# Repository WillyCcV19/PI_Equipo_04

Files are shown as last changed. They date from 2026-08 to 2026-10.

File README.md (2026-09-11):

# EQUIPO N° IV - Proyecto Integrador 2026-2  
<div align="center">

<!-- Banner animado (capsule-render funciona nativo en GitHub, sin GIFs pesados) -->


<!-- Texto tipo "máquina de escribir" (animado, se genera al vuelo) -->
<a href="#-qué-va-a-consistir-el-proyecto">
  Typing SVG
</a>

<br/><br/>






</div>

### Carrera de Ingeniería Industrial / Informática   
**Universidad Peruana Cayetano Heredia**

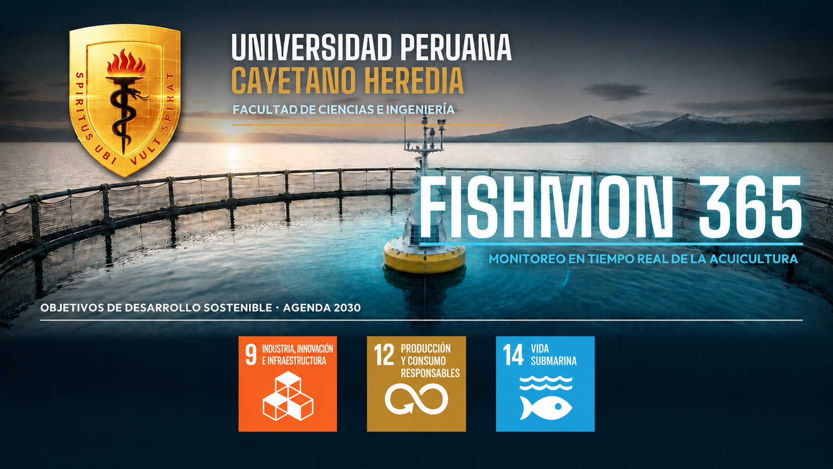
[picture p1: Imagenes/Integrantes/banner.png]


---

## 👫 ¿Quiénes somos?

Somos participantes del curso Proyecto Integrador 2026-2, integrados por estudiantes de Ingeniería Industrial e Informática de la Universidad Peruana Cayetano Heredia. Nuestra misión es utilizar la metodología de diseño para desarrollar soluciones creativas y técnicamente fundamentadas que aporten valor social, tecnológico y ambiental.

---

## ⚙️  Justificación Técnica y Fundamento Biológico

Para validar técnicamente el desarrollo de FISHMON 365, nos basamos en la normativa e investigación oficial del Fondo Nacional de Desarrollo Pesquero (FONDEPES - PRODUCE, Perú) [1]:

### 1. Especie Cultivada y Taxonomía

- **Especie de crianza:** Trucha Arco Iris [1].
- **Nombre científico oficial:** *Oncorhynchus mykiss* (denominada anteriormente *Salmo gairdneri irideus*) [1].
- **Ambiente de cultivo:** Agua dulce continental (recursos hídricos lóticos como ríos, arroyos y manantiales, y lénticos como lagunas) [1].

### 2. Sistemas de Acuicultura en el Perú y Diagnóstico de Mortalidad

| Criterio Técnico | Sistema Convencional (Estanquería) | Sistema No Convencional (Jaulas Flotantes) |
|---|---|---|
| **Infraestructura principal** | Estanques de concreto, mampostería de piedra y tierra [1]. | Jaulas flotantes en lagos y lagunas [1]. |
| **Distribución Regional** | Mayor prevalencia en la Región Junín [1]. | Predominante en la Región Puno (concentra el 98% de esta modalidad) [1]. |
| **Aporte a la Producción Nacional (2012)** | Junín: 3,412.53 TM/Año (13.78%) [1]. | Puno: 18,471.02 TM/Año (74.59%) [1]. |
| **Variabilidad del Medio** | Altamente vulnerable a fluctuaciones de caudal, temperatura y arrastre de sólidos por lluvias [1]. | Vulnerable a eventos de anoxia global en la columna de agua y ecorregiones lénticas [1]. |

### 3. Causa Principal de Mortalidad: Asfixia e Hipoxia por Deficiencia de Oxígeno Disuelto (O₂)

La mayor tasa de mortandad o pérdida de rendimiento biológico-económico en los cultivos de trucha se debe a la pérdida del equilibrio entre el Hospedador, el Patógeno y el Ambiente ($H + P + A = E$) [1].

Específicamente, el factor crítico es la asfixia e hipoxia por baja concentración de oxígeno disuelto ($O_2$). De acuerdo con FONDEPES [1]:

> *"Como la crianza se realiza a grandes densidades es recomendable que la cantidad de oxígeno no sea menor a 5.5 mg/l (60% de saturación de oxígeno) en los momentos de máximo consumo en el cultivo, ya que de lo contrario los peces van a presentar signos de asfixia"* [1, p. 12].
>
> *"Pueden presentarse peces con hipoxia, aunque haya suficiente oxígeno en el medio de cultivo por la presencia de nitritos"* [1, p. 62].

---

## ⚙️ ¿En qué va a consistir el proyecto?

**FISHMON 365** es un **dispositivo multiparámetro portátil y autónomo** diseñado para el **monitoreo en tiempo real y a multinivel** de la calidad del agua dulce en sistemas de cultivo de trucha (*Oncorhynchus mykiss*) [1]. 

El sistema está compuesto por una **sección flotante con electrónica blindada** y una **sonda sumergible vertical multinivel**, equipada con sensores calibrados para realizar lecturas continuas a tres profundidades distintas dentro de la columna de agua. Toda la información capturada es procesada y transmitida de forma inalámbrica mediante tecnología **IoT** directamente a una **aplicación móvil para smartphone**, enviando alertas tempranas en tiempo real ante variaciones fuera de los rangos seguros [1].

Para garantizar la continuidad operativa en zonas rurales o ante posibles cortes de energía eléctrica, el equipo integra un **sistema de alimentación autónomo con batería de respaldo**, asegurando mediciones ininterrumpidas las 24 horas del día.

---

### Perfil de Medición Multinivel en la Columna de Agua

Dado que parámetros críticos como el oxígeno disuelto y la temperatura varían verticalmente según la dinámica del estanque, la descomposición de materia orgánica y el nivel de alimentación [1], **FISHMON 365** monitorea tres estratos clave:

| Profundidad / Estrato | Justificación Técnica Biológica | Impacto en la Trucha Arco Iris |
| :--- | :--- | :--- |
| **Superficie** | Zona de mayor intercambio gaseoso atmosférico e incidencia de radiación solar [1]. | Evalúa la temperatura máxima y la saturación inicial de oxígeno [1]. |
| **Nivel Medio (Media Agua)** | Zona de natación activa y desplazamiento del cardumen de truchas en crecimiento [1]. | Garantiza que la masa de agua habitada mantenga tenores de $O_2 \ge 5.5\text{ mg/L}$ [1]. |
| **Nivel de Fondo (Suelo acuícola)** | Zona de acumulación de alimento no consumido, heces, materia orgánica y alimentación del pez [1]. | Detecta zonas anóxicas ($O_2 < 3.0\text{ mg/L}$), acumulación de nitritos y variaciones de pH por descomposición [1]. |

---

## 🌿 Contexto de Aplicación y Validación de Campo: Santa Eulalia

Para validar el prototipo en condiciones reales de campo de la sierra de Lima, el dispositivo se probará en las piscigranjas de agua dulce del distrito de Santa Eulalia (Provincia de Huarochirí, Lima):

- **Ubicación de prueba:** Valle del río Santa Eulalia (Afluente del río Rímac).
- **Altitud de evaluación:** Entre 1,036 m.s.n.m. y 1,400 m.s.n.m. (zona de cuenca media).
- **Características hídricas:** Aguas continentales dulceacuícolas lóticas (ríos y arroyos de deshielo/manantial) [1].
- **Impacto ambiental local:** Permite monitorear la variación de temperatura y oxígeno disuelto en temporadas de estiaje vs. avenidas (lluvias), previniendo el estrés branquial y mortandades masivas [1].

---

## 🌿 ¿Qué problemáticas soluciona?

| Problema Actual en la Truchicultura | Solución Técnica que Aporta FISHMON 365 | Sustento Oficial (FONDEPES) |
|---|---|---|
| Altas mortandades por asfixia silenciosa ($O_2 < 5.5\text{ mg/L}$) | Monitoreo continuo de Oxígeno Disuelto con alertas sonoras/visuales inmediatas. | *"A menores niveles de $O_2$ (0 - 3.0 mg/l), la trucha muere; entre 3.1 - 4.5 mg/l sufre grave estrés"* [1, p. 12]. |
| Elevados costos de equipos comerciales de laboratorio | Diseño portátil de bajo costo con componentes e integración local | Permite acceso a tecnología a productores de subsistencia y menor escala ($99.44\%$ del mercado) [1, p. 9]. |
| Mediciones manuales extemporáneas que no previenen crisis | Lectura inmediata en campo con diagnóstico automático vía IoT | Permite ajustar inmediatamente la tasa de recambio de agua por hora (R/A/H) [1, p. 11]. |
| Falta de conectividad en zonas altoandinas/rurales | Funcionamiento en modo offline con almacenamiento SD y sincronización posterior IoT | Asegura el registro histórico sin depender de cobertura celular continua. |
| Falta de estandarización técnica del criador | Configuración de umbrales bajo la NTP y manuales de PRODUCE/FONDEPES | Ajustado a los rangos óptimos del agua para *Oncorhynchus mykiss* [1, p. 12-13]. |

---

## 🌿 Alineación con Objetivos de Desarrollo Sostenible (ODS)

Nos comprometemos con la agenda global incorporando las metas oficiales ajustadas según la fuente de la Organización de las Naciones Unidas (ONU):

### 🌿 ODS 9: Industria, Innovación e Infraestructura

**Meta 9.5:** *Aumentar la investigación científica y mejorar la capacidad tecnológica de los sectores industriales de todos los países, en particular los países en desarrollo, entre otras cosas fomentando la innovación e incrementando considerablemente de aquí a 2030 el número de personas que trabajan en investigación y desarrollo por millón de habitantes y los gastos en investigación y desarrollo de los sectores público y privado.*

### 🌿 ODS 12: Producción y Consumo Responsables

**Meta 12.a:** *Ayudar a los países en desarrollo a fortalecer su capacidad científica y tecnológica para avanzar hacia modalidades de consumo y producción más sostenibles.*

### 🌿 ODS 14: Vida Submarina y Recursos Hídricos

**Meta 14.7:** *De aquí a 2030, aumentar los beneficios económicos que los pequeños Estados insulares en desarrollo y los países menos adelantados obtienen del uso sostenible de los recursos marinos, en particular mediante la gestión sostenible de la pesca, la acuicultura y el turismo.*

**Meta 14.a:** *Aumentar los conocimientos científicos, desarrollar la capacidad de investigación y transferir tecnología marina, teniendo en cuenta los Criterios y Directrices para la Transferencia de Tecnología Marina de la Comisión Oceanográfica Intergubernamental, a fin de mejorar la salud de los océanos y potenciar la contribución de la biodiversidad marina al desarrollo de los países en desarrollo, en particular los pequeños Estados insulares en desarrollo y los países menos adelantados.*

---

## 🌿 Matriz de Parámetros Técnicos de Medición (Agua Dulce)

Basado estrictamente en las especificaciones del Manual de Cultivo de Trucha - FONDEPES [1]:

| Parámetro Fisicoquímico | Rango Crítico / Letal | Rango Óptimo de Cultivo | Impacto Biológico en la Trucha Arco Iris |
|---|---|---|---|
| **Oxígeno Disuelto ($O_2$)** | $< 3.0\text{ mg/L}$ (Muerte)<br>$3.1 - 4.5\text{ mg/L}$ (Estrés grave) [1] | **$6.0 - 8.5\text{ mg/L}$** (Mínimo $5.5\text{ mg/L}$) [1] | La deficiencia causa asfixia, reducción del consumo de alimento y suspensión del crecimiento [1]. |
| **Temperatura ($T^\circ\text{C}$)** | $< 3^\circ\text{C}$ o $> 20^\circ\text{C}$ (Muerte / Riesgo severo) [1] | **$11 - 16^\circ\text{C}$** (Engorde óptimo: $15 - 16^\circ\text{C}$)<br>(Incubación: $8 - 10^\circ\text{C}$) [1] | Condiciona el metabolismo, apetito, velocidad de crecimiento y solubilidad del oxígeno disuelto [1]. |
| **Potencial de Hidrógeno (pH)** | $< 6.0$ o $> 9.0$ (Incompatible con la vida) [1] | **$7.0 - 8.0$** (Ligeramente alcalino) [1] | Niveles $< 6.5$ producen hemorragias branquiales y mortandades masivas [1]. |
| **Turbidez / Sólidos** | Elevados sólidos en suspensión [1] | Agua cristalina / Filtrada [1] | Los sólidos en suspensión dañan las branquias y sofocan a los alevinos [1]. |
| **Dióxido de Carbono ($CO_2$)** | $> 2.0\text{ ppm}$ [1] | $< 2.0\text{ ppm}$ [1] | Concentraciones altas merman el $O_2$ disuelto y alteran el pH sanguíneo del pez [1]. |

---

## 📷 Fotografía del equipo

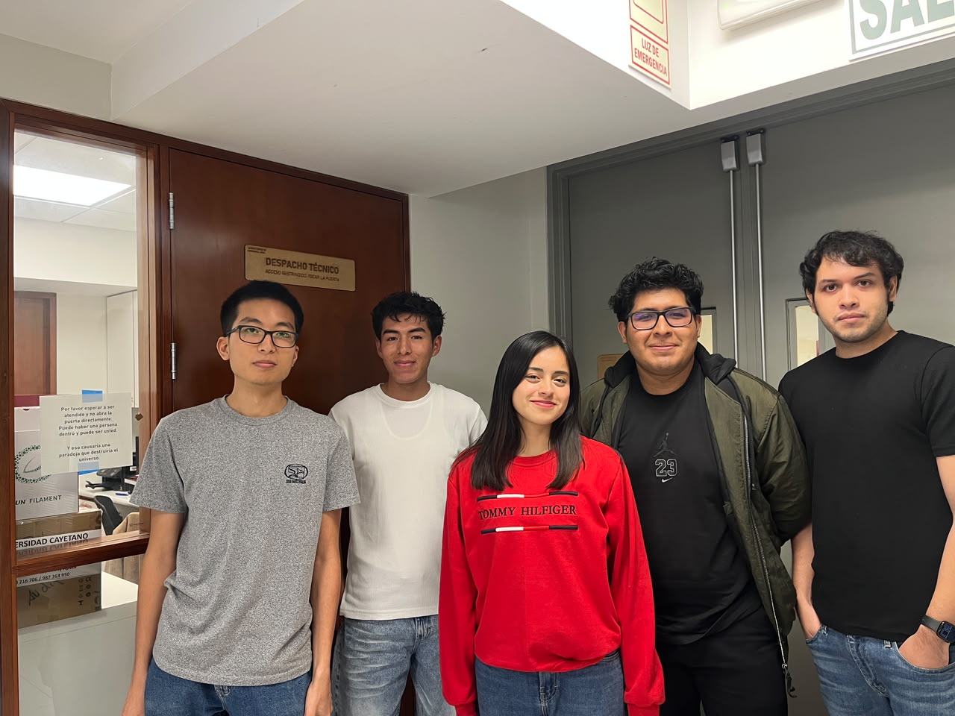
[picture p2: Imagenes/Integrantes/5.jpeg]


---

## 👫 Integrantes

| Foto | Nombre | Rol | Intereses |
|---|---| --- | --- |
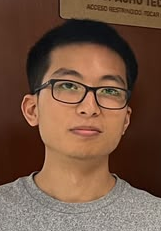
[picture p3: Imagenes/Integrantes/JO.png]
|  | **Karita John Kenneth** | **Líder / Diseñador** | **Diseño de prototipos, hardware** |
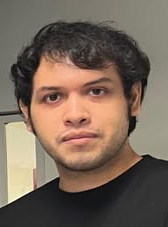
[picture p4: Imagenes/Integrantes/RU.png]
|  | **Cabrera Cermeno Ruben Andre** | **Desarrollo de sistemas** | **Tecnología e implementación de programas** |
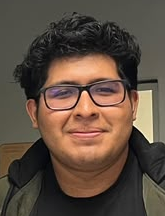
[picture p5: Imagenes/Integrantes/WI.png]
|  | **Ccatamayo Vasquez Willy Simeon** | **Programador / Modelador** | **Programación, simulación** |
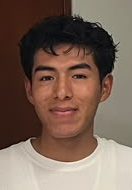
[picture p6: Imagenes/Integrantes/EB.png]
|  | **Pauccara Huancara Eber** | **Encargado de Documentación** | **Producción de documentos científicos y técnicos** |
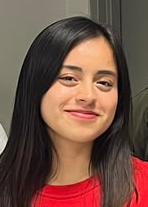
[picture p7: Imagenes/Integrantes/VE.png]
|  | **Quispitongo Leon Verenisse Mary**|  **Responsable de investigación** | **Gestión ambiental, desarrollo comunitario** |

---
##  Fotografía esperada del producto
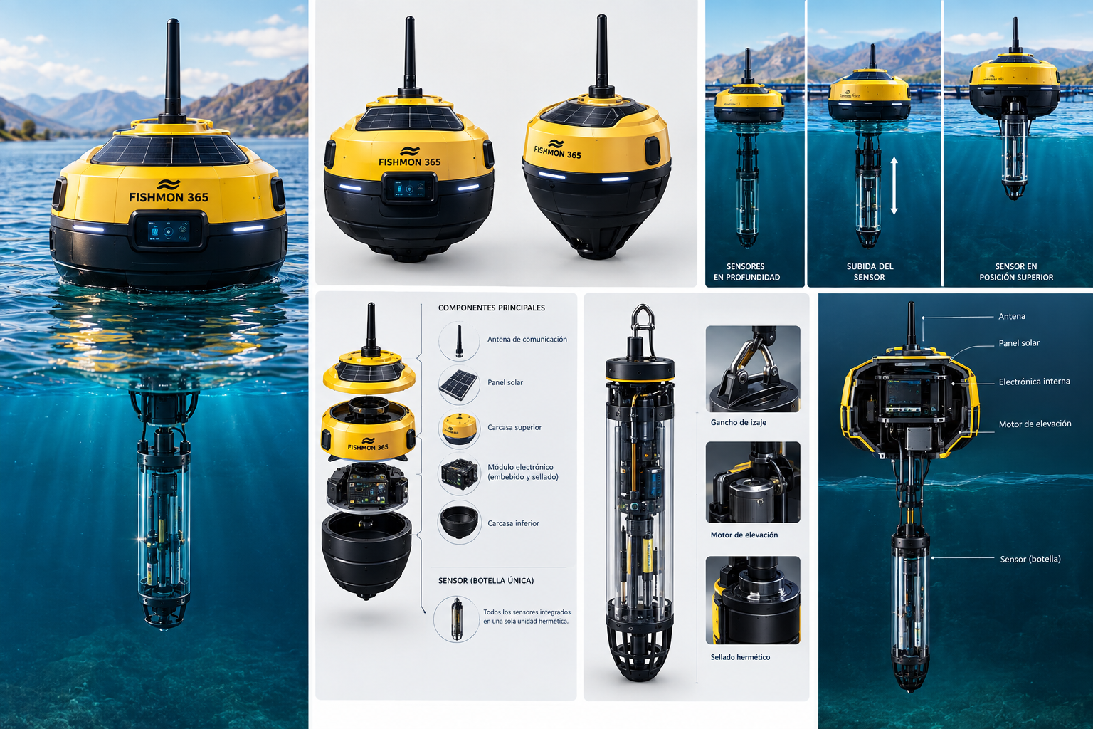
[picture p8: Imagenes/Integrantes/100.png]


---

##  Referencias Bibliográficas

1. **Fondo Nacional de Desarrollo Pesquero (FONDEPES).** (2013). *Manual de Cultivo de Trucha en Ambientes Convencionales*. Ministerio de la Producción (PRODUCE), Dirección General de Capacitación y Desarrollo Técnico en Acuicultura. Lima, Perú. 87 pp.
2. **Organización de las Naciones Unidas (ONU).** (2015). *Transformar nuestro mundo: la Agenda 2030 para el Desarrollo Sostenible*. Resolución aprobada por la Asamblea General el 25 de septiembre de 2015 (A/RES/70/1).

---

<p align="center">
  <strong>🐟 FISHMON 365 — Monitoreo inteligente para una acuicultura sostenible</strong>
</p>
<p align="center">
  <sub>© 2026 - Universidad Peruana Cayetano Heredia</sub>
</p>

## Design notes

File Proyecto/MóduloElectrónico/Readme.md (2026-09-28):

# Bill of materials (no necesariamente del esquemático presente en la carpeta)
- Sensor de oxígeno disuelto gravity
- 2x amplificadores CA3140
- 1x amplificador LM324N
- 2x transceptores LoRa V4 ... por especificar más
- 1x arduino nano
- 4x baterías 18650 1000mA (encontré varios en una laptop)
- respectivo socket paralelo
- módulo de carga
- 4x convertidores boost MT3608
- 1x regulador 7805 + circuito filtrado
- varios componentes pasivos (resistencias, capacitores)
- Conectores MOLEX varios ... por especificar más
- Motor paso a paso ... 28BYJ48 + ULN2003?
- Sensores IR de parada ... Por verse, se acoplarán con encoder
- Pin headers y pin sockets 2.54mm

## Esquemático en KiCAD
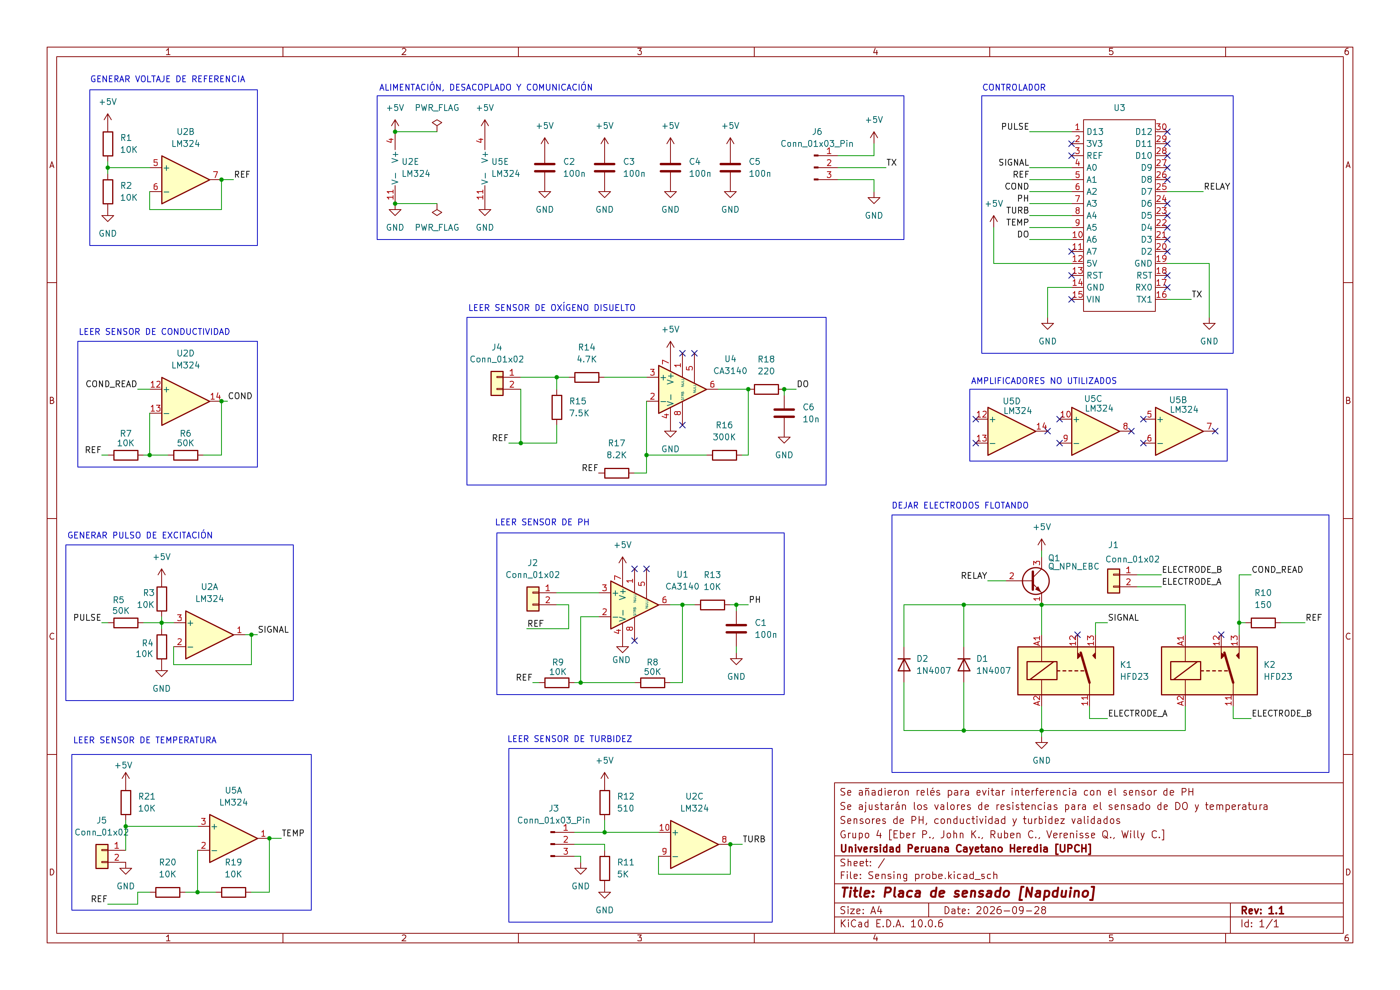
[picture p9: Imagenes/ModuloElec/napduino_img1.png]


## Renderizado 3D
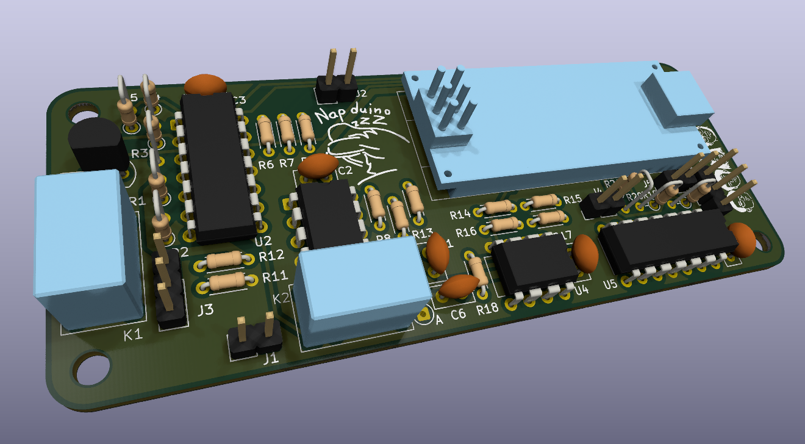
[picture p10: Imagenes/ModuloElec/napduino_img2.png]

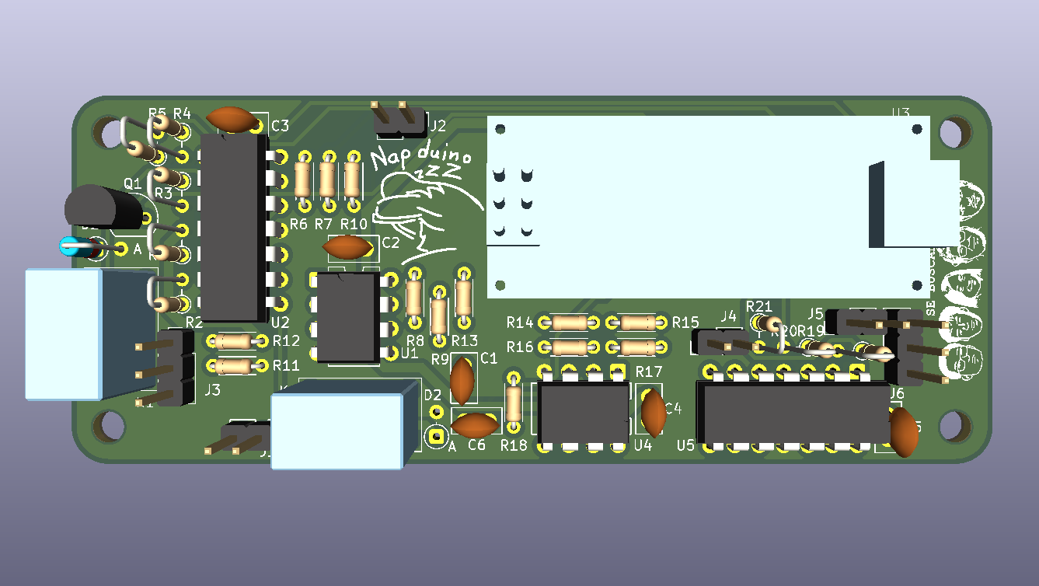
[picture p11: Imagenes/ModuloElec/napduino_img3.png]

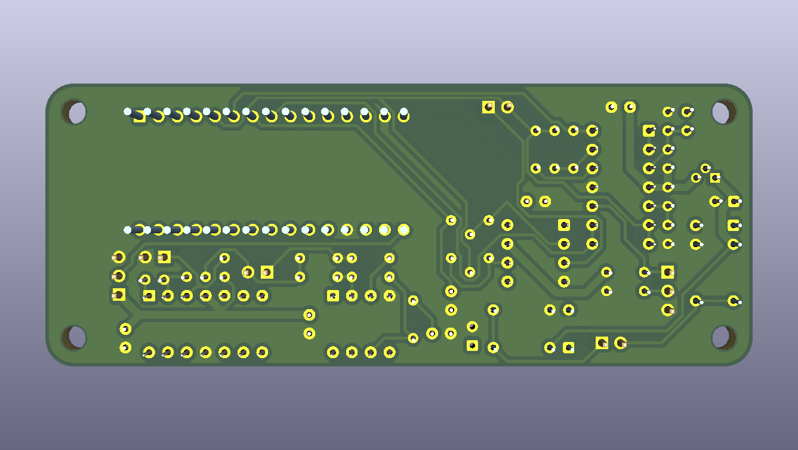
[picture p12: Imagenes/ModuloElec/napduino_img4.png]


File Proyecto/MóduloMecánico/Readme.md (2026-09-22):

Enlace de engranajes Onshape:
https://cad.onshape.com/documents/c017c4d093e17c726a0e157e/w/78a10127cb9374c262a4b3cb/e/6d86611f4e2b43c4129d2fff
Engranaje tipo gusano para evitar regresar....

## Engranaje tipo gusano
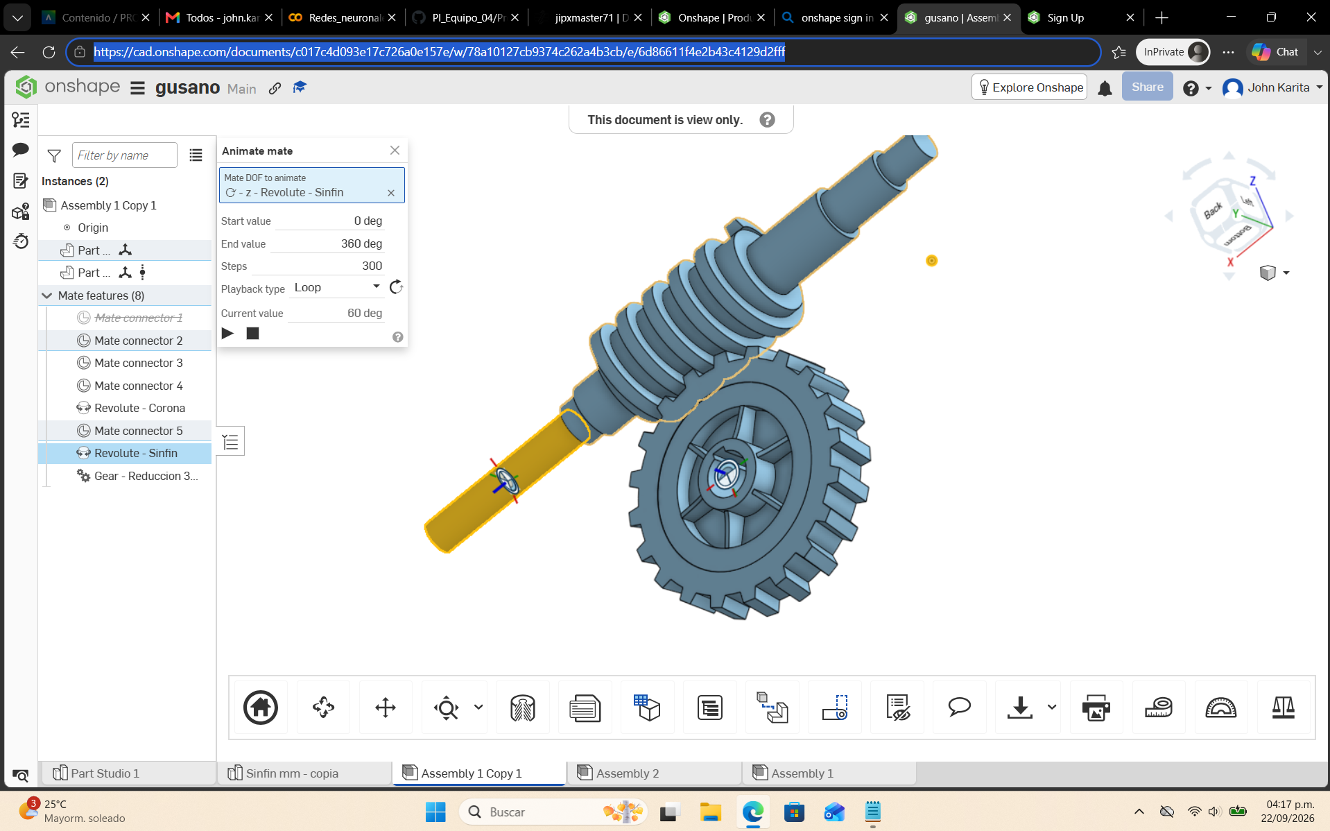
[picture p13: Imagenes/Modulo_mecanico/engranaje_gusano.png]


## Módulo de sensores
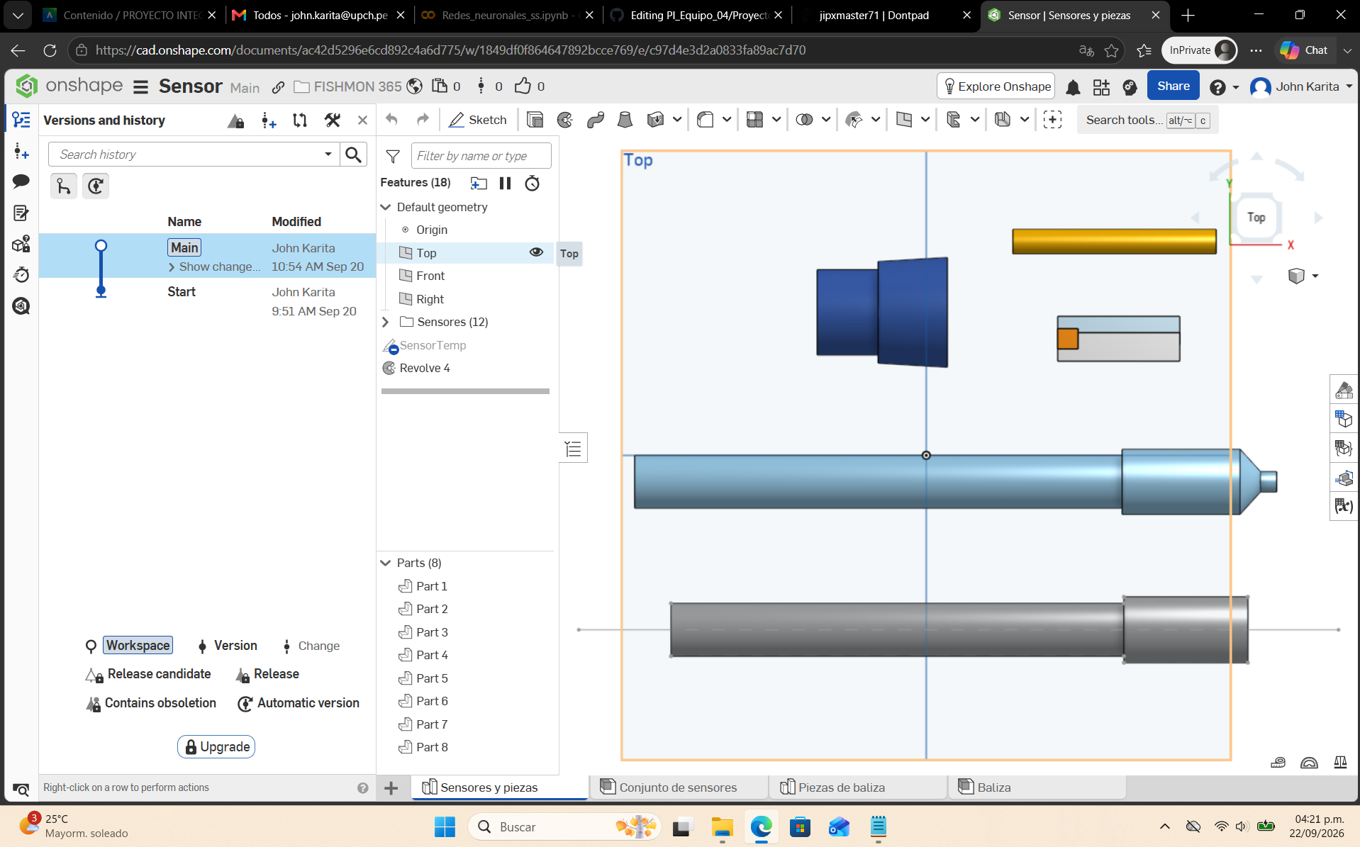
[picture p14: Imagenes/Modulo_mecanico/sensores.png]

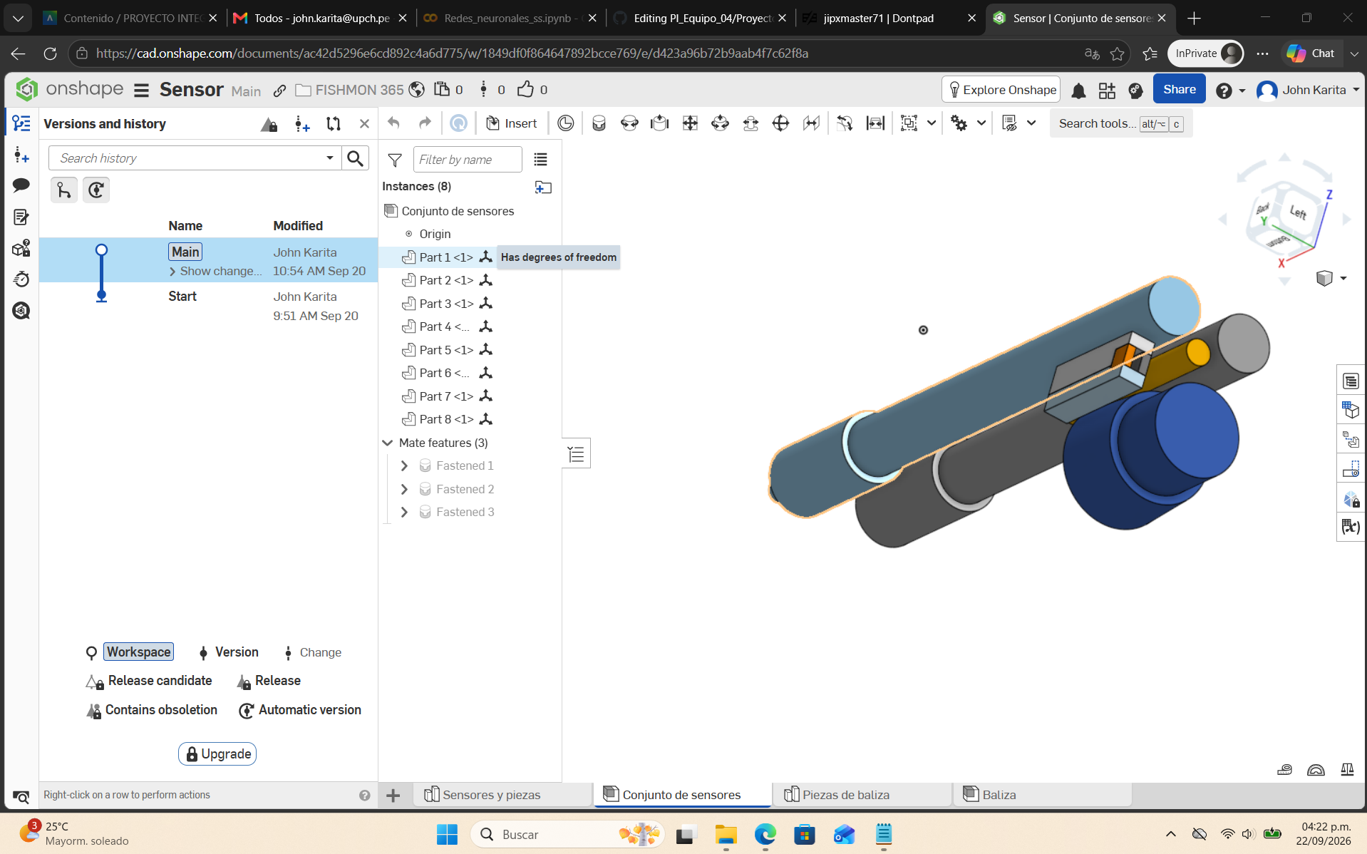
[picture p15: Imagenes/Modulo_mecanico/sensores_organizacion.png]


## Qué falta?
- Carcasa de engranajes + rodamientos
- Completar diseño de conjunto de sensores
- Comenzar carcasa de boya

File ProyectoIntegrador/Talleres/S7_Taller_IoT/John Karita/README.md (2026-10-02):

Ver códigos en la carpeta

## Actividad 1
- Lectura de voltaje promediado de un pin analógico
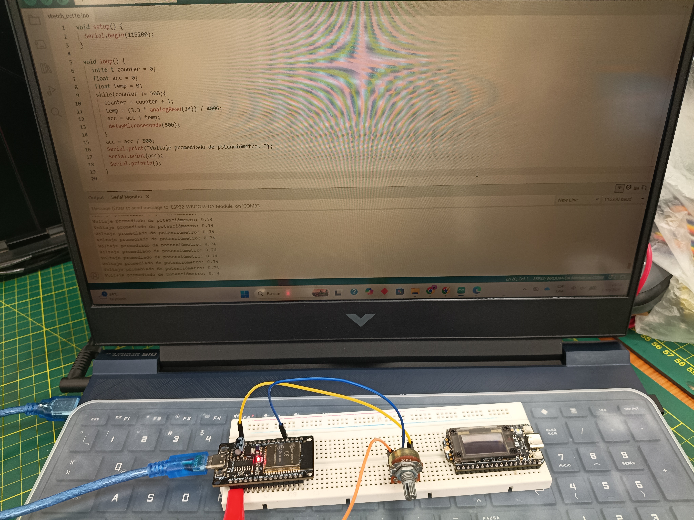
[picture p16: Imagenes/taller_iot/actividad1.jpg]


## Actividad 2
- Barrido de todas las redes disponibles
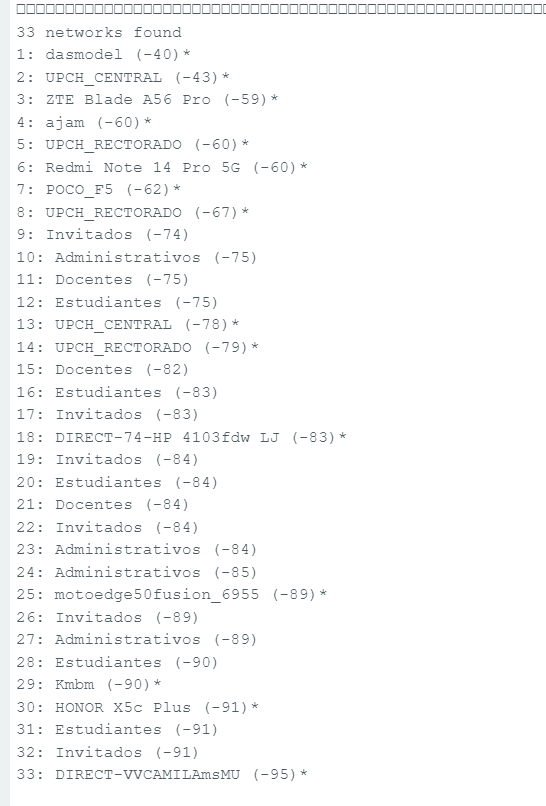
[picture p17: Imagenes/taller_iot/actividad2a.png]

- Conexión y resultados de intensidad, SSID y dirección IP
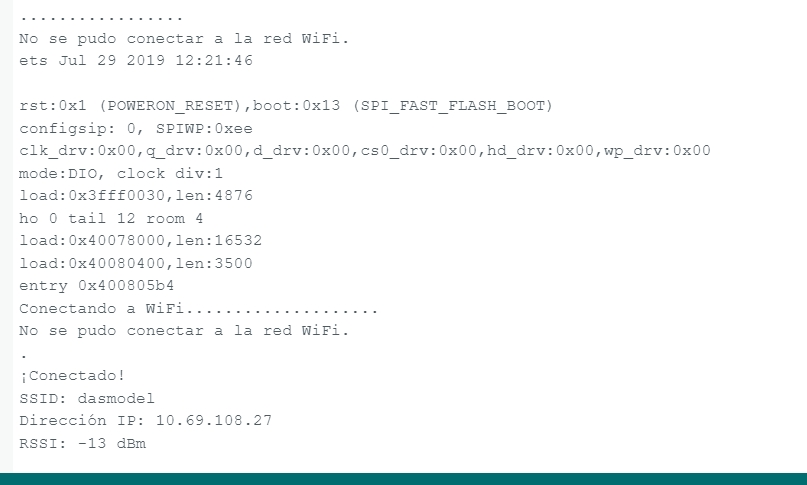
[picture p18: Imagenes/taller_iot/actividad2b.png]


## Actividad 3
- Envío de un único valor en Ubidots mqtt
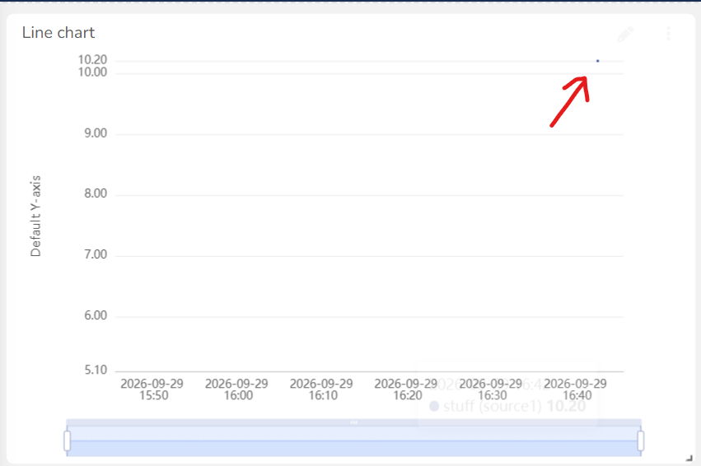
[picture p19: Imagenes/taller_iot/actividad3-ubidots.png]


## Actividad 4
- Recepción y visualización en dashboard de un sensor de turbidez 
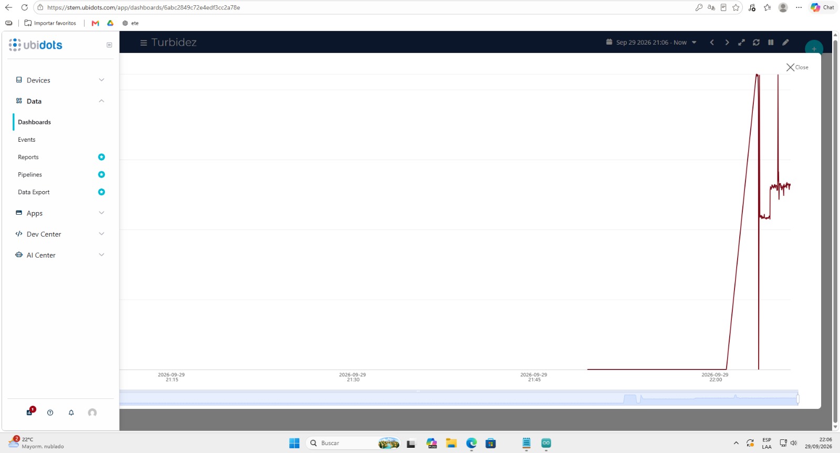
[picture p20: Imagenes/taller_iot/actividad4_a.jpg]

- Armado del circuito
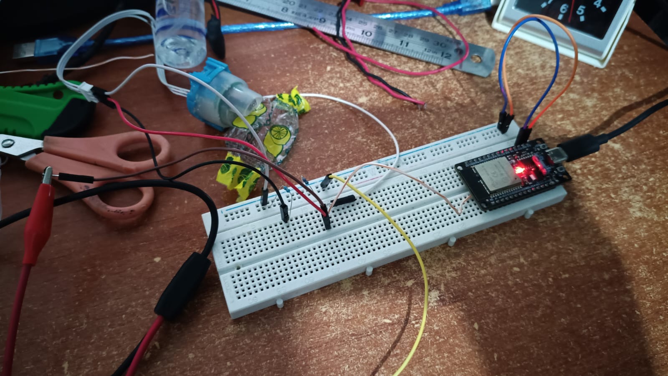
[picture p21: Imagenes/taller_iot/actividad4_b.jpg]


## Actividad 5
- Encendido de un LED mediante Ubidots con una variable creada
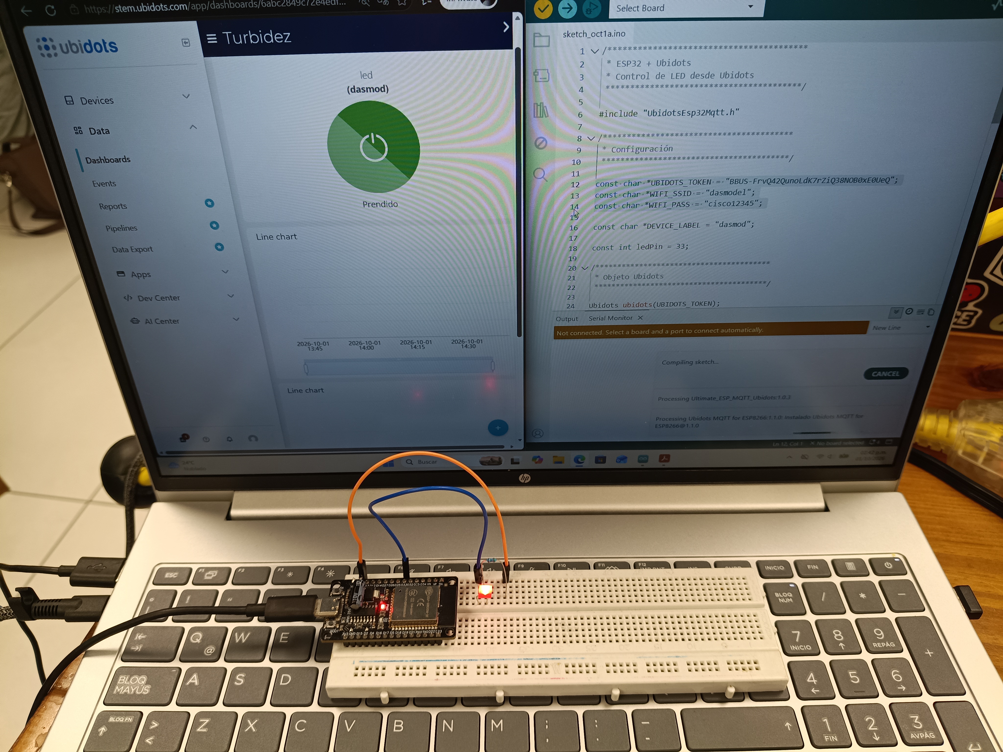
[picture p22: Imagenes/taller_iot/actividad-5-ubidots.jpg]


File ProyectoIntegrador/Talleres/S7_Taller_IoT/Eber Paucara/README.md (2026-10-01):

Taller de Internet de las Cosas (IoT)

## Actividad 01: Adquisición, filtrado y conversión de señal analógica a voltaje

| Evidencia | Código utilizado | Resultado e interpretación |
|---|---|---|
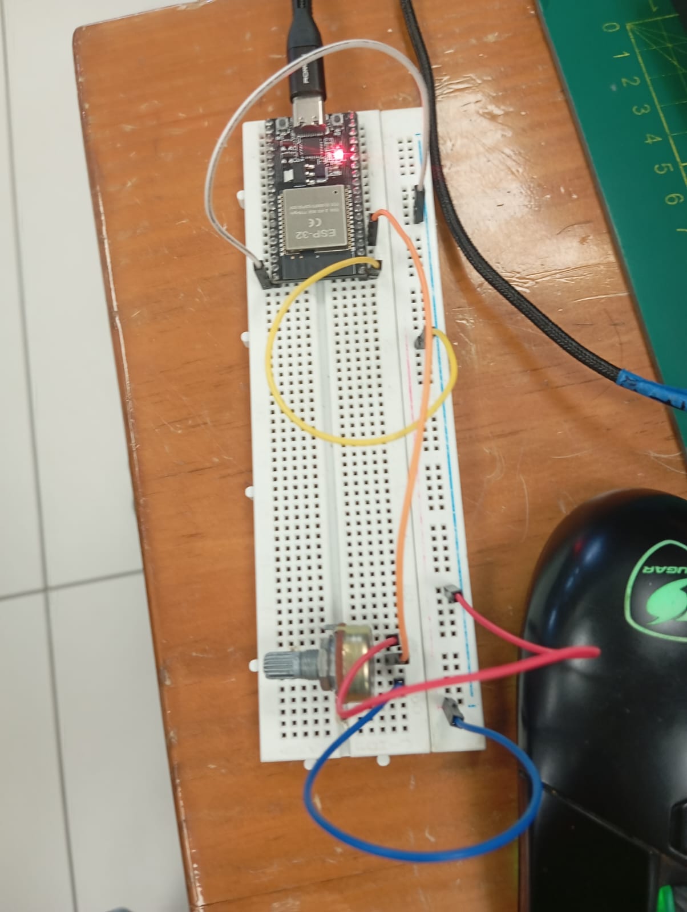
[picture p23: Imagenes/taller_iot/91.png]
| | ```cpp<br>int potPin = 34;<br>``` | Realicé la conexión del potenciómetro al pin 34 del ESP32 para obtener la lectura de la señal analógica. |
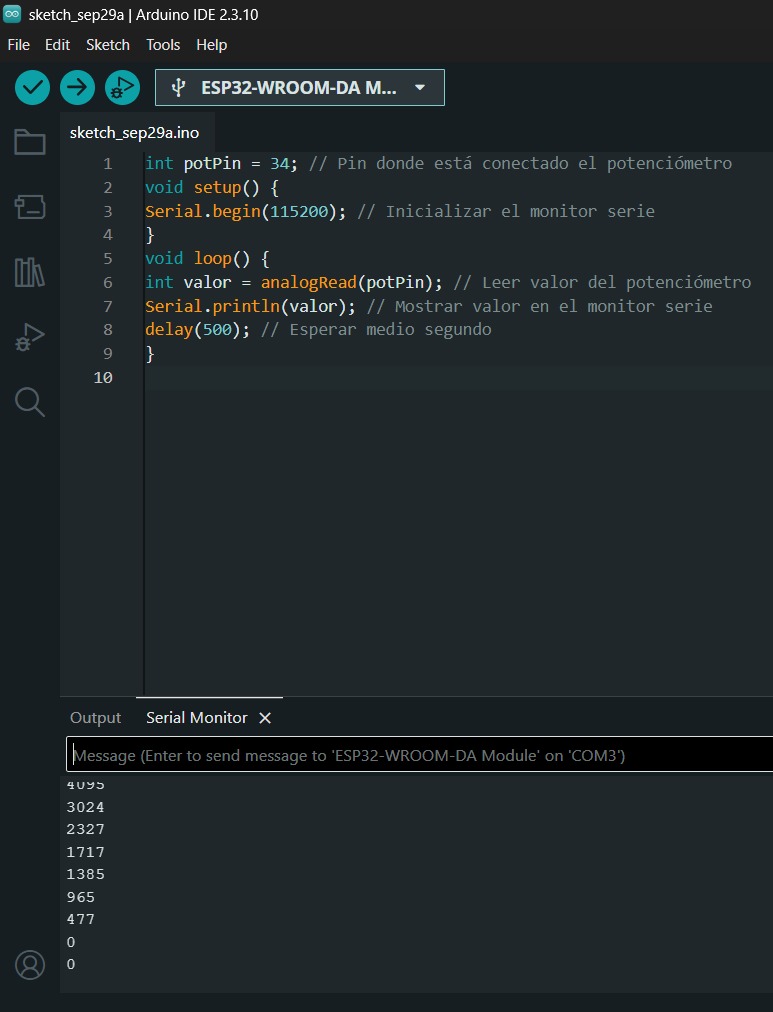
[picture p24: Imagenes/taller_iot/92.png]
|| ```cpp<br>valores[i] = analogRead(potPin);<br>suma = suma + valores[i];<br>delay(50);<br>``` | Realicé varias lecturas del potenciómetro para observar la variación de la señal. Para disminuir estas variaciones utilicé 10 lecturas y calculé su promedio. |
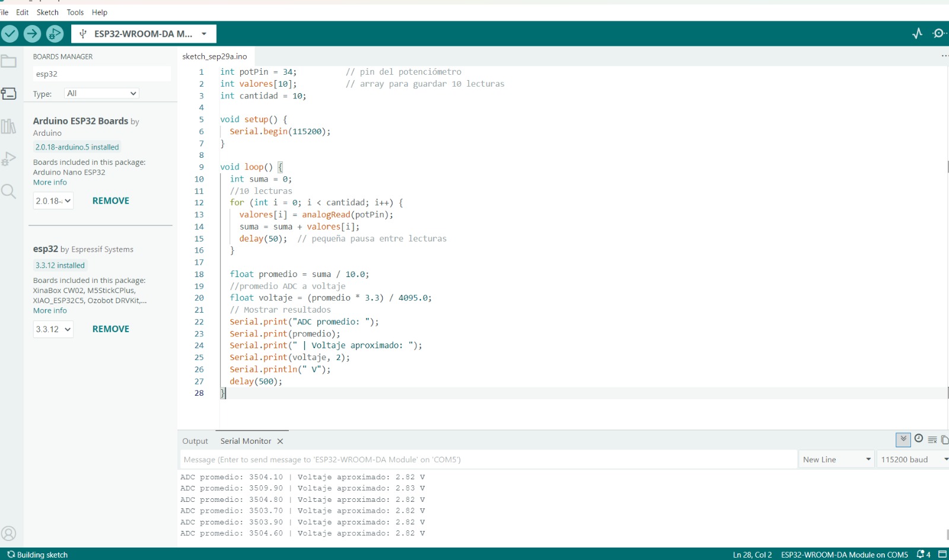
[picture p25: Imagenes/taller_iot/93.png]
|  | ```cpp<br>float promedio = suma / 10.0;<br>float voltaje = (promedio * 3.3) / 4095.0;<br>``` | Obtuve un **ADC promedio de 3504.70**. Luego convertí este valor a voltaje mediante la fórmula del ADC, obteniendo aproximadamente **2.82 V**. |

### Código completo utilizado

```cpp
int potPin = 34;
int valores[10];
int cantidad = 10;

void setup() {
  Serial.begin(115200);
}

void loop() {
  int suma = 0;

  for (int i = 0; i < cantidad; i++) {
    valores[i] = analogRead(potPin);
    suma = suma + valores[i];
    delay(50);
  }

  float promedio = suma / 10.0;
  float voltaje = (promedio * 3.3) / 4095.0;

  Serial.print("ADC promedio: ");
  Serial.print(promedio);
  Serial.print(" | Voltaje aproximado: ");
  Serial.print(voltaje, 2);
  Serial.println(" V");

  delay(500);
}
```

---

## Actividad 02: Escaneo de redes inalámbricas y conexión a red local

| Evidencia | Código utilizado | Resultado e interpretación |
|---|---|---|
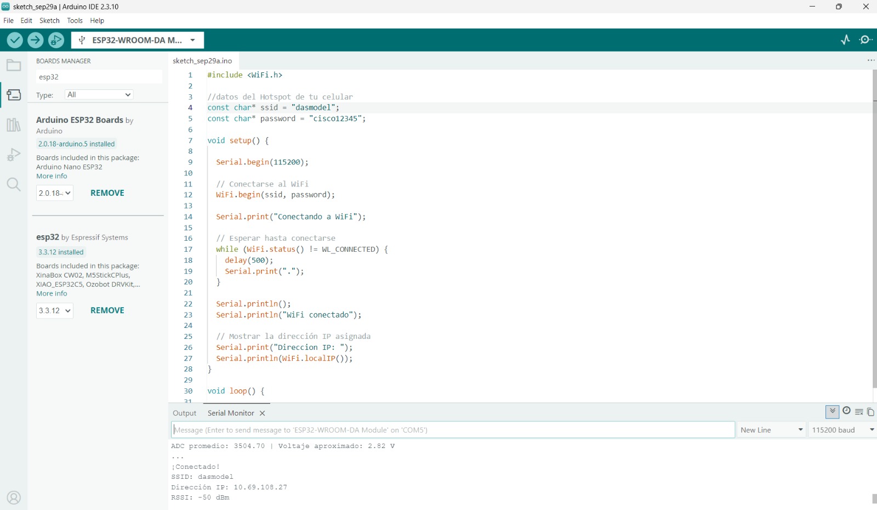
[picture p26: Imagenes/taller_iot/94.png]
|  | ```cpp<br>#include <WiFi.h><br>``` | Realicé el escaneo de las redes disponibles y se identificó la red **dasmodel** con una intensidad de **-43 dBm**. |
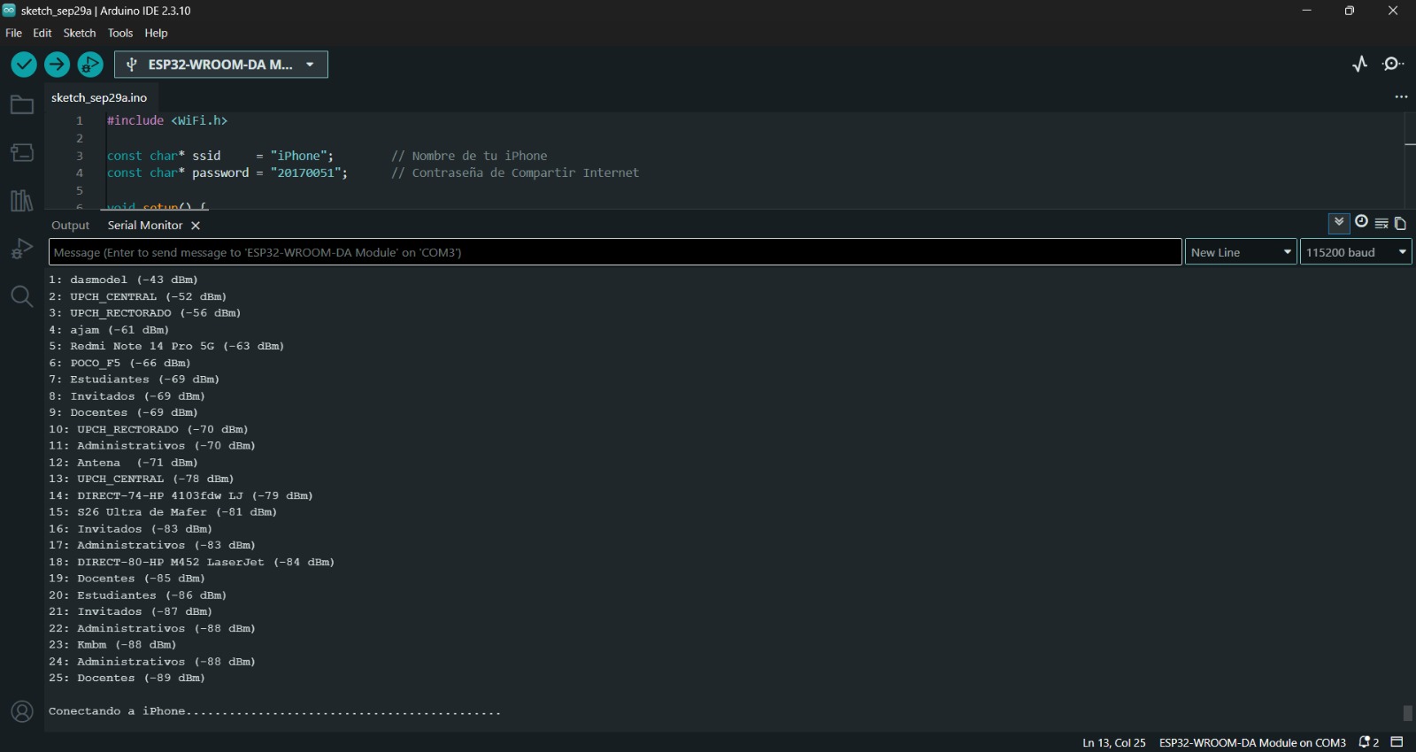
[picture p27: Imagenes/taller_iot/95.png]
|  | ```cpp<br>WiFi.begin(ssid, password);<br>while (WiFi.status() != WL_CONNECTED) {<br>  delay(500);<br>}<br>Serial.println("WiFi conectado");<br>Serial.println(WiFi.localIP());<br>``` | La conexión se realizó correctamente y el ESP32 mostró el mensaje **“WiFi conectado”**. La dirección IP asignada fue **10.69.108.27** y se registró una intensidad de señal de **-50 dBm**. |

### Código completo utilizado

```cpp
#include <WiFi.h>

const char* ssid = "dasmodel";
const char* password = "********";

void setup() {
  Serial.begin(115200);

  WiFi.begin(ssid, password);
  Serial.print("Conectando a WiFi");

  while (WiFi.status() != WL_CONNECTED) {
    delay(500);
    Serial.print(".");
  }

  Serial.println();
  Serial.println("WiFi conectado");
  Serial.print("Direccion IP: ");
  Serial.println(WiFi.localIP());
}

void loop() {
}
```

---

## Actividad 03: Telemetría del potenciómetro hacia ThingSpeak

| Evidencia | Código utilizado | Resultado e interpretación |
|---|---|---|
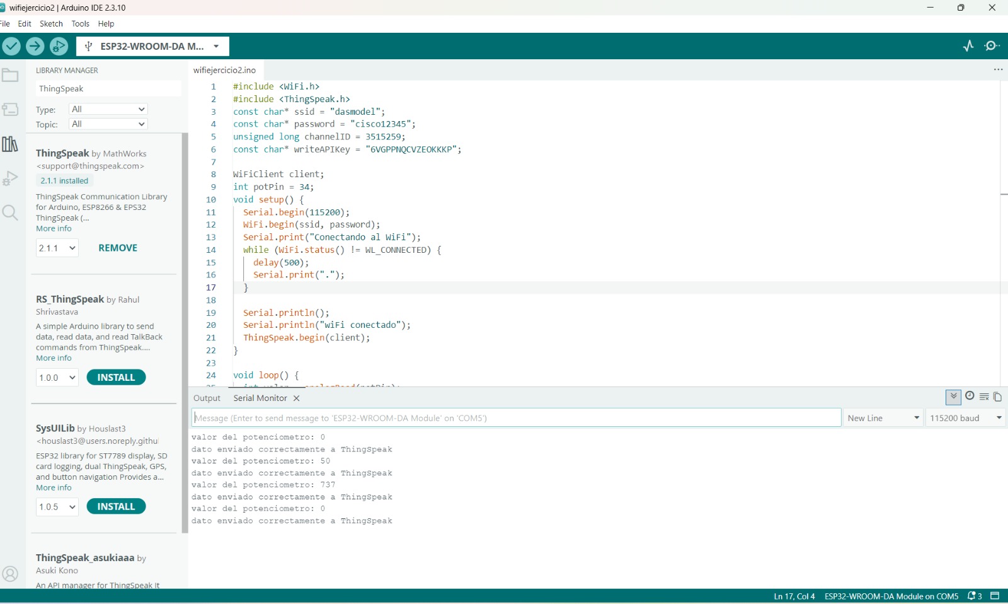
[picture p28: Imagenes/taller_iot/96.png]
|  | ```cpp<br>int valor = analogRead(potPin);<br>int respuesta = ThingSpeak.writeField(<br>  channelID, 1, valor, writeAPIKey<br>);<br>``` | Realicé la lectura del potenciómetro y envié su valor al **Campo 1** de ThingSpeak. La respuesta obtenida fue **200**, por lo que el envío se realizó correctamente. |
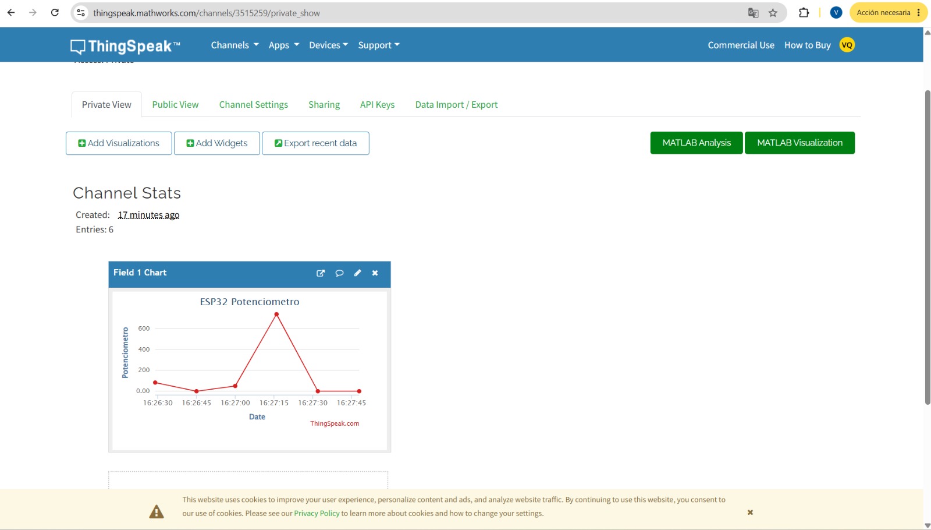
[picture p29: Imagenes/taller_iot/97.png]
|  | ```cpp<br>if (respuesta == 200) {<br>  Serial.println("dato enviado correctamente a ThingSpeak");<br>}<br>delay(15000);<br>``` | En el dashboard se observaron las variaciones del potenciómetro, con lecturas aproximadamente entre **0 y 737**. Los datos fueron enviados periódicamente cada **15 segundos**. |

### Código completo utilizado

```cpp
#include <WiFi.h>
#include <ThingSpeak.h>

const char* ssid = "dasmodel";
const char* password = "********";

unsigned long channelID = 3515259;
const char* writeAPIKey = "********";

WiFiClient client;
int potPin = 34;

void setup() {
  Serial.begin(115200);

  WiFi.begin(ssid, password);

  while (WiFi.status() != WL_CONNECTED) {
    delay(500);
  }

  ThingSpeak.begin(client);
}

void loop() {
  int valor = analogRead(potPin);

  int respuesta = ThingSpeak.writeField(
    channelID,
    1,
    valor,
    writeAPIKey
  );

  if (respuesta == 200) {
    Serial.println("dato enviado correctamente a ThingSpeak");
  } else {
    Serial.print("error al enviar. Codigo: ");
    Serial.println(respuesta);
  }

  delay(15000);
}
```
## Actividad 04: Visualización de lecturas continuas de sensores en Ubidots

| Evidencia | Descripción de la actividad | Resultado e interpretación |
|---|---|---|
|  | **Armado y conexión física del sensor**<br>Conecté el sensor de turbidez a la placa de pruebas mediante cables jumper, enlazando sus salidas hacia la tarjeta de desarrollo para capturar las lecturas del medio líquido. | El circuito quedó correctamente instalado en la mesa de trabajo, permitiendo enviar la señal analógica capturada por el sensor hacia la tarjeta para su procesamiento. |
|  | **Monitoreo y gráfica de turbidez en Ubidots**<br>Configuré un panel en la plataforma en la nube (Ubidots) denominado "Turbidez" para recibir y graficar las variaciones continuas del sensor en tiempo real. | La plataforma registró exitosamente la señal transmitida por internet, mostrando en la gráfica los picos y variaciones de turbidez a lo largo del tiempo de medición. |

---

## Actividad 05: Control remoto de actuadores (LED) desde la plataforma IoT

| Evidencia | Descripción de la actividad | Resultado e interpretación |
|---|---|---|
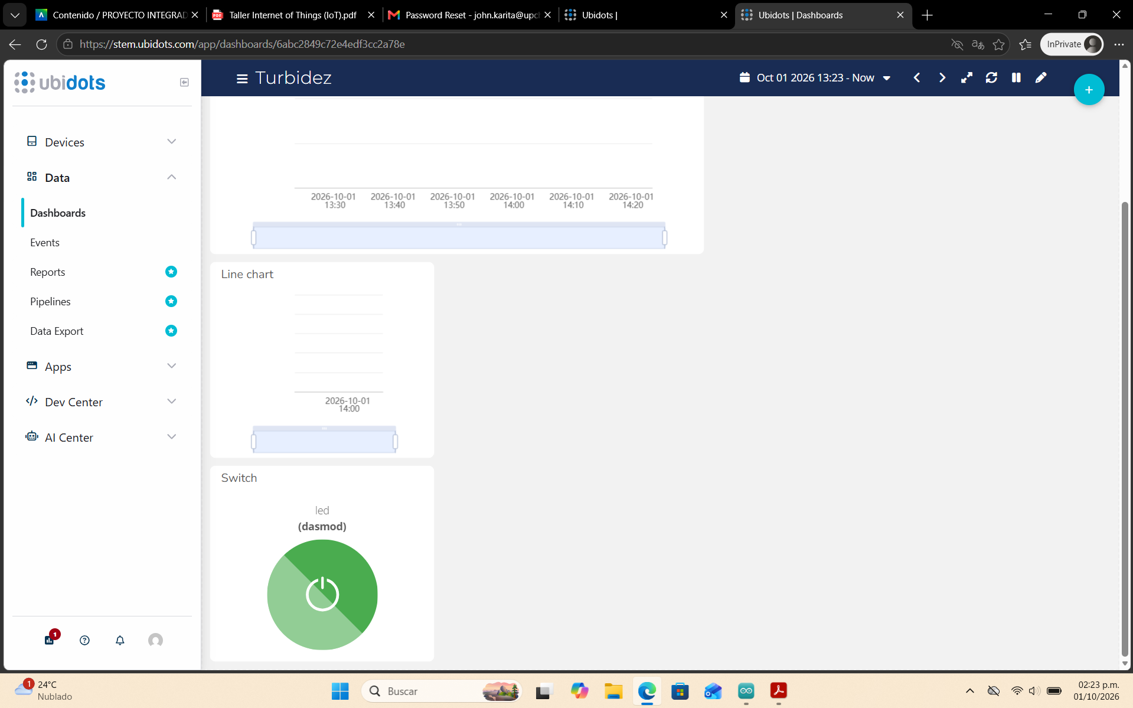
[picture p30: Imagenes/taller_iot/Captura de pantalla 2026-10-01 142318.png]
|  | **Creación del botón de control en la plataforma web**<br>Configuré una plataforma en la nube (Ubidots) creando un botón virtual encendido de color verde para mandar señales de control a la distancia[cite: 18, 47]. | Al presionar el botón virtual en la pantalla, la plataforma envió la orden por internet para activar el foco LED desde la página web en tiempo real[cite: 47]. |
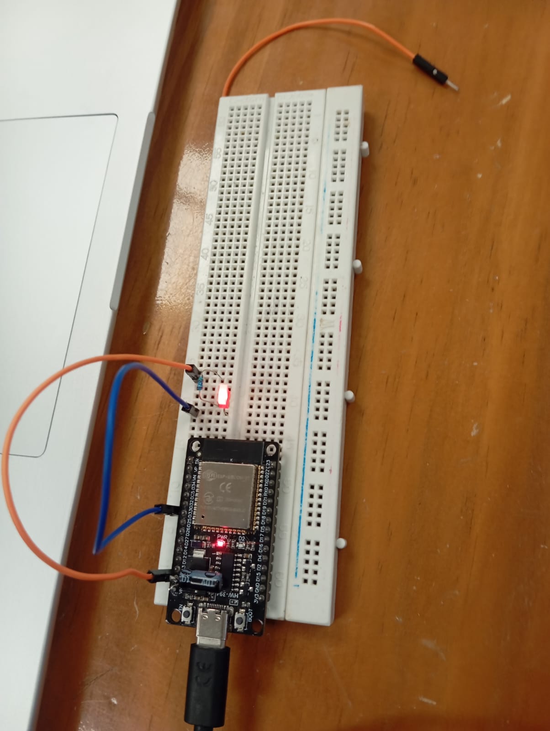
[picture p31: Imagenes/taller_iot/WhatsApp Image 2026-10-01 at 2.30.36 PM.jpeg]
|  | **Conexión e instalación del foco LED en la placa**<br>Conecté un foco LED rojo a la placa de pruebas junto a la tarjeta programable para que reciba las órdenes transmitidas por internet[cite: 5, 42]. | Al recibir la instrucción mandada desde la página web, la tarjeta encendió el foco LED rojo en la placa de manera inmediata[cite: 42]. |

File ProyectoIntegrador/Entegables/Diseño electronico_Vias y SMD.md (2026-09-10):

# Sistema de Monitoreo de Temperatura Subacuática

**ELABORADO POR:** Eber P.H.  
**PROYECTO:** PCB_Modulo_Sensores  

A continuación se presenta el desarrollo del circuito electrónico en EasyEDA para el **Módulo PCB — Sistema de Medición**, correspondiente a la versión de fabricación **THT** (Through-Hole Technology / tecnología de perforación e inserción).

---

| Vista | Tipo de Imagen | Descripción |
| :---: | :--- | :--- |
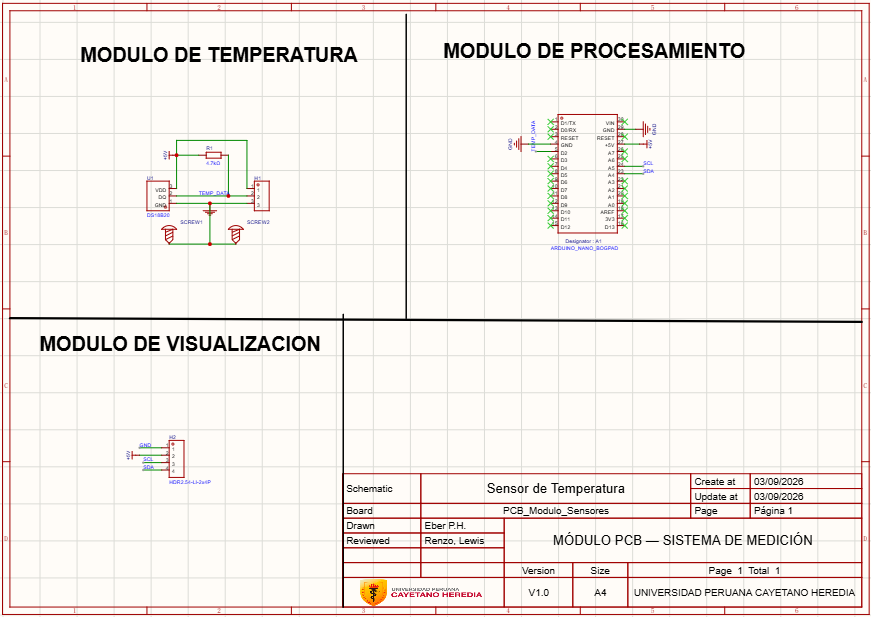
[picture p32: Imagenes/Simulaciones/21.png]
|  | **Esquemático General THT** | Diagrama eléctrico dividido en Módulo de Temperatura (sensor DS18B20 y resistencia de 4.7kΩ), Módulo de Procesamiento (Arduino Nano) y Módulo de Visualización (conector I2C). |
|  | **Diseño de PCB (Layout) THT** | Placa con perforaciones (*pads through-hole*) para los pines del Arduino Nano, sensor U1 en empaque TO-92, resistencia R1, conector I2C H2 y serigrafía institucional. |
|  | **Render 3D THT** | Visualización tridimensional de la tarjeta ensamblada con el módulo Arduino Nano sobre conectores tipo header, resistencia axial de carbón y conectores de interfaz. |

**ELABORADO POR:** Verenisse Quispitongo
**PROYECTO:** MODULO_PCB  

---

## 1. Versión Soldadura por Agujeros
| Vista | Tipo de Imagen | Descripción |
| :---: | :--- | :--- |
|  | **Esquemático General** | Diagrama eléctrico basado en el microcontrolador ESP32-WROOM-32 y un módulo óptico para la medición de turbidez, compuesto por un LED emisor y un fototransistor PT334-6C. La señal obtenida es enviada a una entrada del ESP32 para su procesamiento. |
|  | **Diseño de PCB (Layout)** | Distribución de los componentes del sistema en la tarjeta PCB, incluyendo el ESP32-WROOM-32, resistencias, LED y fototransistor utilizados para el módulo de turbidez, junto con sus respectivas conexiones y plano de tierra GND. |
|  | **Render 3D** | Modelo tridimensional de la tarjeta electrónica diseñada en EasyEDA, mostrando la disposición física del ESP32 y los componentes correspondientes al módulo óptico de medición de turbidez. |

---
*Diseño y documentación realizados en **EasyEDA**.*

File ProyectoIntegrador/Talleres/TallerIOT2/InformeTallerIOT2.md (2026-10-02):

# Práctica IoT: ESP32, MQTT y Node-RED

## 1. Objetivo

Implementar una comunicación IoT utilizando un ESP32, el protocolo MQTT y Node-RED, con el propósito de enviar datos de temperatura y humedad, visualizarlos en un dashboard y permitir el envío de comandos hacia el dispositivo.

---

## 2. Arquitectura implementada

La comunicación realizada durante la práctica puede representarse de la siguiente manera:

```text
Sensor
   ↓
 ESP32
   ↓
  WiFi
   ↓
Broker MQTT
   ↓
 Node-RED
   ↓
Dashboard
```

El ESP32 obtiene los datos del sensor y los publica mediante MQTT. Node-RED se suscribe al topic correspondiente, procesa la información recibida y finalmente la muestra mediante diferentes elementos gráficos. Node-RED permite conectar dispositivos, API y servicios mediante un editor visual basado en nodos.

---

## 4. Configuración en Node-RED

Se creó un flujo en Node-RED encargado de recibir los datos publicados por el ESP32.
El topic utilizado para recibir la información fue:

```text
equipo04/sensor/datos
```

Los datos recibidos fueron separados para mostrar:

- Temperatura.
- Humedad.
- Identificación del dispositivo.

También se agregó un control tipo **Switch LED**, mediante el cual se pueden enviar comandos al ESP32.

### Flujo implementado



En la imagen se observa el nodo MQTT de entrada conectado a distintos nodos de procesamiento y posteriormente a los elementos del dashboard.

---

## 5. Configuración del broker MQTT

Para establecer la comunicación se configuró Node-RED con el broker MQTT utilizado durante la práctica.
Se establecieron las credenciales correspondientes para permitir la autenticación con el broker.

### Configuración de seguridad


   
</div>
Posteriormente, en el nodo de entrada MQTT se configuró el topic:

```text
equipo04/sensor/datos
```

El mensaje fue configurado para recibirse como un **objeto JSON**, facilitando la extracción de los valores de temperatura, humedad y dispositivo.

### Configuración del topic



El broker actúa como intermediario entre el ESP32 y Node-RED, permitiendo que ambos puedan intercambiar información sin comunicarse directamente entre sí.

---
## 6. Circuito implementado

Para la implementación práctica se utilizó un ESP32 conectado a los sensores mediante una protoboard. El ESP32 se encargó de adquirir los datos de los sensores y posteriormente enviarlos mediante WiFi utilizando el protocolo MQTT.

A continuación se muestra el circuito utilizado durante la práctica:

<div align="center">



<br><br>


</div>

<p align="center">
  <em>Circuito implementado con ESP32 y sensor DTH11 con pin GPIO4.</em>
</p>

## 7. Visualización de los datos

Luego de establecer correctamente la comunicación, los datos recibidos fueron mostrados en el dashboard de Node-RED.
El dashboard permitió visualizar:

- Nombre del dispositivo.
- Temperatura en °C.
- Humedad relativa en %.
- Control del LED.
- Gráfica de variación de la temperatura.

### Dashboard

<div align="center">
  
</div>

Durante la prueba se obtuvo, por ejemplo:

```text
Dispositivo: ESP32_Equipo04
Temperatura: 24 °C
Humedad: 61 %
```

Esto permitió comprobar que los datos enviados desde el ESP32 estaban llegando correctamente al broker MQTT y posteriormente a Node-RED.

---

## 8. Gráfica en tiempo real

Además de los indicadores, se utilizó una gráfica para observar la variación de los datos a lo largo del tiempo.

<div align="center">

</div>

La gráfica permite observar los cambios producidos en las mediciones conforme el ESP32 continúa enviando información. Durante las pruebas se observan algunos cambios bruscos y una caída puntual en los valores, debido a que el ESP32 fue desconectado temporalmente para realizar ajustes y pruebas en el circuito. Una vez restablecida la conexión, el envío de datos continuó con normalidad, comprobándose que la comunicación entre el ESP32, el broker MQTT y Node-RED estaba funcionando correctamente.

---

## 9. Resultado

Se logró establecer correctamente la comunicación entre el ESP32, el broker MQTT y Node-RED. Los valores de temperatura y humedad fueron recibidos mediante el topic `equipo04/sensor/datos` y posteriormente mostrados en un dashboard mediante indicadores y una gráfica. También se implementó un control para el LED, demostrando que la comunicación puede realizarse en ambos sentidos: desde el ESP32 hacia Node-RED para enviar datos y desde Node-RED hacia el ESP32 para enviar comandos.

---

## 10. Conclusión

La práctica permitió comprender de manera aplicada el funcionamiento de una arquitectura IoT utilizando MQTT. El ESP32 actuó como dispositivo encargado de obtener y publicar los datos, el broker MQTT permitió gestionar la comunicación y Node-RED fue utilizado para procesar y visualizar la información mediante un dashboard. De esta manera se implementó un sistema básico de monitoreo y control en tiempo real.

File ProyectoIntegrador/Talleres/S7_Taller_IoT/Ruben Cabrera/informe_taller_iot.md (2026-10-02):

# Informe – Taller IoT con ESP32

---

## Introducción

En este taller se trabajó con la placa ESP32 en cinco actividades: la lectura de una señal analógica mediante un potenciómetro, el escaneo y la conexión a redes WiFi, el envío de datos a la plataforma Arduino Cloud para visualizarlos en tiempo real, el envío de la lectura de un sensor de temperatura a plataformas IoT y el control de un LED desde la nube. En este informe se interpretan las salidas obtenidas en cada ejercicio.

---

## Ejercicio 1: Lectura promediada de un potenciómetro

### Descripción del código

El programa toma **20 lecturas** del pin analógico conectado al potenciómetro, con una pausa de 10 ms entre cada una, y calcula su promedio para reducir el ruido de la señal. Luego convierte ese promedio a voltaje con la fórmula:

$$
V = \frac{\text{promedio ADC} \times 3.3}{4095}
$$

Finalmente, imprime el valor ADC promedio y el voltaje aproximado en el monitor serial cada 500 ms.

### Salida obtenida

Salida del ejercicio 1

### Interpretación

- El ADC del ESP32 tiene una resolución de **12 bits**, por lo que sus lecturas van de **0 a 4095**.
- Todas las lecturas muestran **4095.00**, que equivale a **3.30 V**. Es el valor máximo del ADC: el pin estaba recibiendo el voltaje completo de alimentación.
- Que el valor se mantenga constante indica que el potenciómetro estaba **girado al tope** durante la captura. En el ejercicio 3 se comprueba que, al girarlo, el valor sí recorre todo el rango de 0 a 4095.
- El promedio de 20 lecturas funciona como un **filtro**: en posiciones intermedias, el ADC del ESP32 suele variar varias unidades entre lecturas, y promediar estabiliza el resultado.

### Observaciones

- El texto del monitor serial (`ADC promedio:` con dos decimales) no coincide exactamente con el del código mostrado (`Promedio ADC:` con un decimal). Esto indica que la salida corresponde a una versión anterior del sketch, cargada antes de la última edición.
- En el cálculo del promedio se divide entre `20.0` de forma fija. Es preferible dividir entre `numLecturas`, para que el cálculo siga siendo correcto si se cambia la cantidad de lecturas.

---

## Ejercicio 2: Escaneo de redes WiFi y conexión

### Descripción del código

El programa utiliza la librería `WiFi.h` para escanear las redes WiFi cercanas y mostrar cada una con su intensidad de señal (RSSI, en dBm). Después intenta conectarse a la red `iPhone`, un hotspot creado desde un celular.

### Salida obtenida

Salida del ejercicio 2

### Interpretación del escaneo

El ESP32 detectó **25 redes**, ordenadas de mayor a menor intensidad de señal. El RSSI siempre es negativo, y mientras más cercano a 0, mejor es la señal:

| Rango RSSI | Calidad de señal | Ejemplos detectados |
|---|---|---|
| −30 a −50 dBm | Excelente | dasmodel (−43 dBm) |
| −50 a −60 dBm | Muy buena | UPCH_CENTRAL (−52 dBm), UPCH_RECTORADO (−56 dBm) |
| −60 a −70 dBm | Buena | ajam, Redmi Note 14 Pro 5G, POCO_F5, Estudiantes |
| −70 a −80 dBm | Débil | Antena, UPCH_CENTRAL (−78 dBm), DIRECT-74-HP |
| Menor a −80 dBm | Muy débil | Invitados (−83 dBm), Kmbm (−88 dBm), Docentes (−89 dBm) |

Algunas redes aparecen **repetidas** con distinta intensidad (Estudiantes, Docentes, Invitados, Administrativos, UPCH_CENTRAL). No es un error: son **varios puntos de acceso** de la red de la universidad que transmiten el mismo nombre desde distintas ubicaciones, y el ESP32 detecta cada uno por separado. También se detectaron hotspots de celulares y redes `DIRECT-…` de impresoras con WiFi Direct.

### Interpretación del intento de conexión

- Después del escaneo aparece `Conectando a iPhone...` seguido de muchos puntos, que representan los intentos de conexión. La conexión **no se logró**.
- La red `iPhone` **no aparece entre las 25 redes detectadas**, por lo que el ESP32 no podía conectarse a ella. Una causa probable es que el hotspot transmitía en la banda de **5 GHz**, mientras que el ESP32 **solo trabaja en 2.4 GHz**. En iPhone esto se soluciona activando la opción **"Maximizar compatibilidad"** en los ajustes de Compartir Internet.
- Al final aparecen **caracteres ilegibles**. Esto suele indicar que el ESP32 **se reinició**: al arrancar, la placa imprime mensajes a 74880 baudios, y el monitor configurado en 115200 baudios los muestra como caracteres extraños. El reinicio pudo deberse a un tiempo de espera definido en el código, al watchdog o a una caída de voltaje.

---

## Ejercicio 3: Monitoreo del potenciómetro en Arduino Cloud

### Descripción

El ESP32 lee el potenciómetro y envía el valor promedio a una variable de **Arduino Cloud**. El valor se visualiza en un widget **Chart** del dashboard en modo **LIVE**, y al mismo tiempo en el monitor serial web del sketch `Actividad3` (puerto COM3, 115200 baudios).

### Salida obtenida

Salida del ejercicio 3

### Interpretación de los valores

- Los valores **varían entre 0 y 4095**, es decir, todo el rango del ADC. Esto confirma que el potenciómetro está correctamente conectado y que se giró de un extremo al otro durante la prueba.
- **0** equivale a 0 V (potenciómetro al mínimo) y **4095** a 3.3 V (al máximo). Los valores intermedios corresponden a posiciones parciales; por ejemplo, 2125 = 1.71 V y 1308 = 1.05 V.
- Los valores se muestran como **enteros**, lo que indica que la variable enviada a la nube es de tipo entero.

### Interpretación de la gráfica

- Cada **pico** (cerca de 4K) corresponde al potenciómetro girado al máximo, y cada **valle** (en 0) al mínimo. Las oscilaciones reflejan los giros de ida y vuelta durante la prueba.
- Hacia el final de la gráfica , la curva se **estabiliza cerca de 3,500**: el potenciómetro se dejó en una posición fija.
- La gráfica tiene **menos puntos** que el monitor serial. Esto es esperado: Arduino Cloud no envía cada lectura, sino que sincroniza la variable con una frecuencia limitada, mientras que el monitor serial muestra todas las lecturas.
- El widget **suaviza la curva** uniendo los puntos con líneas curvas, por lo que la gráfica se ve más continua que los datos reales.

---

## Ejercicio 4: Envío de la temperatura a ThingSpeak

### Actividad

Escribir un código que muestre en tiempo real la variación de uno de los sensores del kit Keystudio (LM35, LDR, etc.) conectado al ESP32 en las plataformas de IoT Arduino Cloud, ThingSpeak y Ubidots.

### Descripción del código

Se utilizó el sensor de temperatura **LM35**. El programa lee el valor del ADC, lo convierte a voltaje y luego a temperatura en C, e imprime los tres valores en el monitor serial. Después envía la temperatura al **campo 1** de un canal de **ThingSpeak** con la función `ThingSpeak.writeField(channelID, 1, temperatura, writeAPIKey)`. El programa espera **15 segundos** entre cada envío.

### Salida obtenida

Salida del ejercicio 4

### Interpretación

- Cada lectura muestra tres valores: el **ADC** (entre 124 y 138), el **voltaje** (entre 0.100 y 0.111 V) y la **temperatura** (entre 23.99 y 25.12 C).
- Después de cada lectura aparece `Temperatura enviada a ThingSpeak`. Este mensaje solo se imprime cuando la función devuelve el código **200**, que en HTTP significa que la solicitud fue **exitosa**. Por lo tanto, todos los envíos llegaron correctamente al canal.
- El LM35 entrega **10 mV por cada C**. En los datos se observa esa relación: una diferencia de 0.004 V entre lecturas corresponde a una diferencia de 0.4 C. La temperatura obtenida, alrededor de **24 C**, es coherente con la temperatura de un ambiente interior.
- La variación entre lecturas (menos de 1.2 C) no refleja un cambio real de temperatura, sino el **ruido del ADC**: cada unidad del ADC equivale a unos 0.8 mV, por lo que una variación de pocas unidades produce cambios de algunas décimas de grado.
- La pausa de **15 segundos** responde al límite de la cuenta gratuita de ThingSpeak, que acepta como máximo una actualización cada 15 segundos por canal. Si se envían datos más rápido, el servidor los rechaza.

### Observaciones

- El ruido podría reducirse promediando varias lecturas antes de calcular la temperatura, como se hizo en el ejercicio 1.
- El ADC del ESP32 es poco preciso en voltajes bajos, cercanos a 0 V, que es justamente el rango en el que trabaja el LM35 a temperatura ambiente. Para mejorar la precisión se puede usar la función `analogReadMilliVolts()`, que aplica la calibración interna del ESP32.

---

## Ejercicio 5: Control de un LED desde la nube con Ubidots

### Actividad

Conectar un LED en uno de los pines digitales del ESP32 y controlar su encendido desde alguna de las plataformas web de su preferencia.

### Descripción

Se eligió la plataforma **Ubidots**. En el dashboard `Turbidez` se agregó un widget **Switch** vinculado a la variable `led` del dispositivo `dasmod`. Al activar o desactivar el switch, Ubidots cambia el valor de la variable a 1 o 0. El ESP32, conectado a la plataforma, recibe ese valor y enciende o apaga el LED conectado al pin digital.

### Salida obtenida

Salida del ejercicio 5

### Interpretación

- El widget **Switch** muestra el control de la variable `led` del dispositivo `dasmod`. Su color **verde** indica que está en estado **encendido** (valor 1), por lo que el LED conectado al ESP32 debería estar prendido.
- Este ejercicio funciona en sentido contrario a los anteriores: en lugar de que el ESP32 **envíe** datos a la nube, el ESP32 **recibe** una orden desde la nube y la ejecuta sobre un actuador. Así, el LED puede controlarse desde cualquier lugar con acceso a internet.
- El dashboard también tiene dos gráficos de línea (**Line chart**), con el rango de tiempo desde el 1 de octubre de 2026 a las 13:23 hasta el momento actual. Ambos aparecen **vacíos**, lo que indica que las variables asociadas a esos gráficos no recibieron datos en ese periodo. Estos gráficos no forman parte de esta actividad, que solo requiere el control del LED.

### Evidencia del LED encendido

LED encendido desde Ubidots

- La foto muestra el **circuito físico**: el ESP32 montado en el protoboard, alimentado por USB-C, y el LED rojo conectado a la placa mediante dos cables (uno al pin digital de control y otro a tierra).
- El **LED rojo está encendido**, lo que coincide con el estado **activado** del switch en el dashboard de Ubidots. Esto confirma que la orden enviada desde la nube llegó al ESP32 y se ejecutó sobre el pin digital.
- La pequeña luz roja sobre la placa, junto al conector USB, es el **LED de encendido del ESP32**, que indica que la placa está alimentada. No forma parte del ejercicio.

---

## Conclusiones

1. El ADC de 12 bits del ESP32 convierte voltajes de 0 a 3.3 V en valores de 0 a 4095, y promediar varias lecturas permite obtener mediciones más estables.
2. El escaneo WiFi permite evaluar la calidad de señal de las redes cercanas mediante el RSSI. Para conectarse, la red debe transmitir en la banda de 2.4 GHz, la única compatible con el ESP32.
3. Arduino Cloud permite visualizar en tiempo real los datos del sensor desde un dashboard web, lo que muestra la integración entre el hardware y una plataforma IoT en la nube.
4. Los caracteres ilegibles en el monitor serial son una señal útil para diagnosticar reinicios de la placa.
5. ThingSpeak permite almacenar y graficar datos de sensores mediante solicitudes HTTP. El código de respuesta 200 confirma que cada envío fue exitoso, y el límite de una actualización cada 15 segundos debe respetarse en el código.
6. Ubidots permite controlar actuadores desde un dashboard web. Esto demuestra que la comunicación IoT funciona en ambos sentidos: el ESP32 puede enviar datos a la nube y también recibir órdenes desde ella.

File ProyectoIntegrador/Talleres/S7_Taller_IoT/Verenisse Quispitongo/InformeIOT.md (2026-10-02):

## Ejercicio 1: Lectura de un potenciómetro con ESP32
## Mejorar el código anterior haciendo uso de un promediado de los datos y convirtiendo los valores del ADC a valores de voltaje.

En este ejercicio se conectó un potenciómetro al ESP32 utilizando el pin analógico GPIO 34. Primero se realizó la lectura directa de los valores del ADC y se visualizaron en el monitor serial.
Posteriormente, se mejoró la lectura tomando 10 muestras consecutivas y calculando su promedio, con el fin de obtener un valor más estable.
Finalmente, el valor promedio del ADC se convirtió a voltaje mediante la relación entre el rango del ADC y el voltaje de referencia de 3.3 V.

### Código utilizado


### Circuito Implementado



## Ejercicio 2: Conexión del ESP32 a una red WiFi

En este ejercicio se creó una red WiFi utilizando la función de **Hotspot o zona WiFi de un smartphone**. El objetivo fue conectar el ESP32 a dicha red y verificar la comunicación mostrando en el monitor serial la dirección IP asignada al dispositivo.

Para realizar la conexión se utilizaron el nombre de la red (`SSID`) y la contraseña del hotspot del celular.

### Funcionamiento

El programa realiza los siguientes pasos:

1. Inicializa la comunicación serial a 115200 baudios.
2. El ESP32 intenta conectarse al hotspot utilizando el nombre de red y contraseña configurados.
3. Mientras no se establece la conexión, se muestran puntos en el monitor serial.
4. Una vez conectado, se muestra el mensaje WiFi conectado.
5. Finalmente, se imprime la dirección IP asignada al ESP32.

### Evidencias


### Resultado

Se logró conectar correctamente el ESP32 al hotspot creado desde el smartphone.

En el monitor serial se visualizaron los datos de la conexión:

- **SSID:** dasmodel
- **Dirección IP:** 10.69.108.27
- **RSSI:** -50 dBm

El valor RSSI representa la intensidad de la señal WiFi recibida por el ESP32. En este caso, el valor obtenido indica una buena conexión con el hotspot.

## Ejercicio 3: Visualización del potenciómetro en ThingSpeak

En este ejercicio se conectó un potenciómetro al ESP32 y se enviaron sus lecturas a la plataforma IoT ThingSpeak mediante una conexión WiFi.

El potenciómetro fue conectado al pin analógico GPIO 34 del ESP32. El valor leído por el ADC varía aproximadamente entre 0 y 4095 dependiendo de la posición del potenciómetro.

Para enviar estos datos a Internet, el ESP32 se conectó a una red WiFi utilizando el nombre y contraseña de la red.

### Configuración en ThingSpeak

Primero se creó un canal en ThingSpeak con un campo llamado:

Field 1: Potenciometro

Luego se obtuvieron los siguientes datos del canal:

- Channel ID
- Write API Key

Estos datos permiten que el ESP32 pueda identificar el canal y enviar información hacia ThingSpeak.

### Funcionamiento

El programa realiza los siguientes pasos:

1. El ESP32 se conecta a la red WiFi.
2. Se realiza una lectura del potenciómetro mediante el GPIO 34.
3. El valor obtenido se muestra en el monitor serial.
4. El ESP32 envía el dato al `Field 1` del canal de ThingSpeak.
5. ThingSpeak almacena los valores recibidos y los representa gráficamente.

Se utilizó un intervalo de aproximadamente 15 segundos entre cada envío de información.

### Evidencias


#### Variación del potenciómetro en ThingSpeak


### Resultado

Se logró conectar el ESP32 a ThingSpeak mediante WiFi y enviar correctamente las lecturas obtenidas del potenciómetro.

Al modificar la posición del potenciómetro, los valores enviados también cambiaron, permitiendo visualizar su variación mediante una gráfica en tiempo real en ThingSpeak.

# Actividad 04: Monitoreo de temperatura con LM35 y ThingSpeak

## Objetivo

Implementar un sistema IoT utilizando un sensor **LM35 conectado al ESP32**, con el fin de obtener mediciones de temperatura y enviarlas mediante WiFi a la plataforma **ThingSpeak**, donde se puede observar su variación mediante una gráfica.

## Componentes utilizados

- ESP32
- Sensor de temperatura LM35
- Protoboard
- Cables jumper
- Conexión WiFi
- Plataforma ThingSpeak

## Funcionamiento

El sensor LM35 genera una salida analógica que cambia dependiendo de la temperatura. Esta señal es leída por el ADC del ESP32.
Primero se obtiene la lectura analógica:

```cpp
int valorADC = analogRead(lm35Pin);
```

Luego, el valor del ADC se convierte a voltaje:

```cpp
float voltaje = (valorADC * 3.3) / 4095.0;
```

Se utiliza `4095` debido a que el ADC del ESP32 trabaja con una resolución de 12 bits, permitiendo valores entre aproximadamente 0 y 4095.

### Conversión de voltaje a temperatura

El LM35 entrega aproximadamente **10 mV por cada grado Celsius**, es decir:

```text
10 mV = 0.01 V = 1 °C
```

Por este motivo, para convertir el voltaje a temperatura se divide entre `0.01`:

```text
Temperatura = Voltaje / 0.01
```

lo cual es equivalente a multiplicar por 100:

```cpp
float temperatura = voltaje * 100.0;
```

Por ejemplo:

```text
0.25 V × 100 = 25 °C
```

De esta manera, la lectura analógica del sensor puede expresarse directamente en grados Celsius.

## Envío de datos a ThingSpeak

El ESP32 se conectó a una red WiFi y posteriormente se utilizó la librería de ThingSpeak para enviar las mediciones.
La plataforma fue inicializada mediante:

```cpp
ThingSpeak.begin(client);
```

La temperatura obtenida se envió al `Field 1` del canal creado en ThingSpeak:

```cpp
int respuesta = ThingSpeak.writeField(
    channelID,
    1,
    temperatura,
    writeAPIKey
);
```

## Resultados obtenidos

Durante la ejecución se visualizaron en el monitor serial los valores obtenidos por el sensor.

<div align="center">
  
</div>

<p align="center">
  <em>Lecturas del LM35 y envío de datos a ThingSpeak.</em>
</p>

En el monitor serial se observaron diferentes valores del ADC, voltaje y temperatura. Además, el mensaje:

```text
Temperatura enviada a ThingSpeak
```

permitió comprobar que las mediciones estaban siendo enviadas correctamente a la plataforma.

Posteriormente, en ThingSpeak se observó la variación de la temperatura mediante una gráfica.

<div align="center">
  
</div>

<p align="center">
  <em>Variación de temperatura registrada en ThingSpeak.</em>
</p>

La gráfica muestra las diferentes mediciones recibidas desde el ESP32. Durante las pruebas se produjeron algunos cambios bruscos debido a conexiones, desconexiones y ajustes realizados al sensor durante la implementación. Finalmente, las mediciones se estabilizaron alrededor de los valores observados en el monitor serial.

## Resultado

Se logró obtener información del sensor LM35 mediante el ESP32 y enviar las mediciones a ThingSpeak utilizando una conexión WiFi. La plataforma permitió visualizar de manera remota la variación de la temperatura, demostrando el funcionamiento básico de un sistema IoT compuesto por un sensor, un microcontrolador, conexión a Internet y una plataforma de visualización.

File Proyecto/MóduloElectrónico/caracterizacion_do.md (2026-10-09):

# Caracterización inicial del sensor de Oxígeno disuelto "Gravity Analog Dissolved Oxygen Sensor SEN0237-A"

## Objetivo: Obtener voltajes en condiciones de 100% y 0% de oxígeno disuelto en agua
- Caracterizar de manera preliminar la respuesta del sensor de oxígeno disuelto en aire, agua aireada y agua con sulfito de sodio
- Identificar lecturas de referencia para una posterior calibración

## Detalles
- Para lograr una concentración cercana (no verificada) de 0% oxígeno disuelto se disolvió 1 gramo de sulfito de sodio en 30mL de agua destilada (era la unidad mínima de mi balanza)
- Para lograr un aproximado (no verificado) de 100% se agitó el agua vigorosamente y se lo dejó airear numerosas veces
- El osciloscopio posee 8 cuadros de altura (con precisión variable por cada uno)
- Las mediciones son de RMS hechas durante 12 segundos (12 cuadros horizontales, 1 segundo cada uno)

# Primer intento: 
- 1.85v aire (500mv res)
  
| Tiempo | Voltaje (mv) | Precisión por cuadro (mv) |
|--|--|--|
|1:30|200|500|
|4:15|40|500|
|6:12|27|500|
|7:44|44|20|
|10:30|38|20|
|11:30|36|20|
|12:30|34|20|
|13:30|33|20|
|14:30|32|20|

# Segundo intento: agua con sulfito de sodio
- 1.79v al aire 

| Tiempo | Voltaje (mv) | Precisión por cuadro (mv) |
|--|--|--|
|1:30|122|500|
|2:00|100|50|
|4:00|46|50|
|4:30|44|50|
|5:30|37|20|
|6:30|33|20|
|9:30|25|20|
|11:00|25|20|
|15:30|22|20|

# Primer intento de agua agitada
1.78v al aire

| Tiempo | Voltaje (mv) | Precisión por cuadro (mv) |
|--|--|--|
|1:30|1200|500|
|2:30|1030|500|
|3:30|940|500|
|4:30|870|500|
|5:00|850|500|

# Misma agua, sin agitar más
- 1.76v al aire

| Tiempo | Voltaje (mv) | Precisión por cuadro (mv) |
|--|--|--|
|1:30|1030|500|
|2:00|970|500|
|2:30|930|500|
|3:00|910|500|
|4:00|860|500|
|5:00|840|500|

# Segundo intento: agua nuevamente agitada
- 1.78v al aire

| Tiempo | Voltaje (mv) | Precisión por cuadro (mv) |
|--|--|--|
|1:30|1200|500|
|2:00|1130|500|
|2:30|1040|500|
|3:00|1000|500|
|4:00|940|500|
|5:00|900|500|

# Tener en cuenta
- Todas las mediciones hechas a 24 grados celsius
- Las pruebas fueron hechas en casa
- Se midió con el circuito amplificador que viene de fábrica con el sensor
- Es un informe preliminar antes de calibrar en laboratorio

## Reacción del sensor de Oxígeno disuelto ante un cambio brusco de su entorno

<table>
  <tr>
    <td align="center">
      
      <br>
      <em>Respuesta del sensor al sumergirlo en solución con sulfito de sodio</em>
    </td>
    <td align="center">
      
      <br>
      <em>Respuesta del sensor al removerlo de la solución</em>
    </td>
  </tr>
</table>

<table>
  <tr>
    <td align="center">
      
      <br>
      <em>Primeros segundos al sumergirse en agua aireada</em>
    </td>
    <td align="center">
      
      <br>
      <em>Medición realizada 90 segundos después</em>
    </td>
  </tr>
</table>

<table>
  <tr>
    <td align="center">
      
      <br>
      <em>Reacción del sensor al removerlo tras 5 minutos sumergido en agua aireada </em>
    </td>
    <td align="center">
      
      <br>
      <em>Materiales utilizados</em>
    </td>
  </tr>
</table>

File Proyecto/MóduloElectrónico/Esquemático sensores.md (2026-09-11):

## ESQUEMA NO TERMINADO - INICIAL
## Falta colocar más detalles, PCB, grupo, curso, etc


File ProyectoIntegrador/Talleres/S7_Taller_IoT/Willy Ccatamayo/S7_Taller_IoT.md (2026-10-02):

# Taller de Internet de las Cosas (IoT)

# Actividad 01: Promediado del ADC y conversión a voltaje

## Procedimiento realizado

Se mejoró el código del ESP32 para tomar 20 lecturas del potenciómetro conectado al pin 34 y calcular su promedio, reduciendo las fluctuaciones de la medición. Luego, se convirtió el promedio del ADC a un voltaje aproximado mediante la fórmula `voltaje = promedio × 3.3 / 4095`. Ambos resultados se mostraron en el monitor serial a 115200 baudios.

## Resultados



En el monitor serial se observa que el promedio del ADC aumenta desde 0 hasta 4095, mientras el voltaje calculado pasa de 0.00 a 3.30 V. Por ejemplo, un promedio de 1084.70 corresponde a 0.87 V y uno de 2515.90 corresponde a 2.03 V. Esta variación es consistente con el ajuste del potenciómetro. Las últimas lecturas permanecen en 4095 y 3.30 V, indicando que el ADC alcanzó su valor máximo.

El promediado ayuda a reducir las fluctuaciones entre lecturas. Los voltajes son aproximados, ya que se calculan mediante la fórmula utilizada en el programa.

## Código utilizado

```cpp
const int potPin = 34;       // Pata central del potenciómetro
const int numLecturas = 20;  // Lecturas para calcular el promedio

void setup() {
  Serial.begin(115200);
}

void loop() {
  long suma = 0;

  // Tomar 20 lecturas
  for (int i = 0; i < numLecturas; i++) {
    suma += analogRead(potPin);
    delay(10);
  }

  float promedio = suma / 20.0;
  float voltaje = promedio * 3.3 / 4095.0;  // Voltaje aproximado

  Serial.print("Promedio ADC: ");
  Serial.print(promedio, 1);
  Serial.print(" | Voltaje aproximado: ");
  Serial.print(voltaje, 2);
  Serial.println(" V");

  delay(500);
}
```

# Actividad 02: Conexión del ESP32 a un hotspot WiFi

## Procedimiento realizado

Se creó una red WiFi mediante la función de compartir Internet del smartphone. Se programó el ESP32 para escanear las redes disponibles, mostrar sus nombres e intensidad de señal y conectarse al hotspot llamado “iPhone”. El programa muestra la dirección IP asignada cuando se establece la conexión.

## Resultados





La captura muestra las redes WiFi detectadas y su intensidad de señal en dBm. Un valor menos negativo indica una señal más fuerte. Al final aparece el mensaje “Conectando a iPhone…”, indicando que el ESP32 está intentando conectarse. Todavía no aparece el mensaje de conexión exitosa ni la dirección IP, por lo que esta captura confirma el escaneo y el inicio de la conexión, pero no su finalización.

## Código utilizado

```cpp
#include <WiFi.h>

const char* ssid     = "iPhone";          // Nombre del hotspot
const char* password = "20170051";   // Contraseña de Compartir Internet

void setup() {
  Serial.begin(115200);
  delay(1000);
  WiFi.mode(WIFI_STA);
  WiFi.disconnect();
  delay(100);

  // 1. Escaneo de redes
  Serial.println("Escaneando redes WiFi...");
  int n = WiFi.scanNetworks();
  for (int i = 0; i < n; i++) {
    Serial.printf("%d: %s (%d dBm)\n", i + 1, WiFi.SSID(i).c_str(), WiFi.RSSI(i));
  }

  // 2. Conexión al hotspot del iPhone
  Serial.printf("\nConectando a %s", ssid);
  WiFi.begin(ssid, password);
  while (WiFi.status() != WL_CONNECTED) {
    delay(500);
    Serial.print(".");
  }

  // 3. Mostrar IP asignada
  Serial.println("\n¡Conectado!");
  Serial.print("Dirección IP asignada: ");
  Serial.println(WiFi.localIP());
}

void loop() {
}
```

# Actividad 03: Monitoreo del potenciómetro mediante Arduino Cloud

## Procedimiento realizado

Para esta actividad se utilizó Arduino Cloud para visualizar la variación del potenciómetro conectado al ESP32.

1. **Configuración del dispositivo:** Se registró el ESP32 Dev Module con el nombre “Actividad3” y se vinculó a un Thing en Arduino Cloud.

2. **Configuración de la red:** Se ingresaron el nombre del hotspot “iPhone”, su contraseña y la clave del dispositivo para permitir la conexión con la plataforma. Durante las primeras pruebas se observaron intentos fallidos de conexión.

3. **Creación de la variable:** Se configuró la variable `potenciometro` como un número entero, con permiso de solo lectura y actualización cuando cambia su valor.



4. **Programación del ESP32:** Se utilizó un código que obtiene varias lecturas del ADC, calcula su promedio y asigna el resultado a la variable `potenciometro`. También se imprimieron las lecturas en el monitor serial para comprobar sus cambios.

5. **Configuración del dashboard:** Se agregó un widget de tipo Chart y se vinculó a la variable `potenciometro` para representar sus valores a lo largo del tiempo.

6. **Prueba de funcionamiento:** Se varió la posición del potenciómetro y se revisaron las lecturas del monitor serial, la variable en Arduino Cloud y el estado de conexión del ESP32.

## Resultados



En el monitor serial se registraron diferentes lecturas, como 1308, 3274 y 1521, mostrando la variación del potenciómetro. Además, Arduino Cloud registró un último valor de 3712 en la variable configurada, lo que confirma la recepción de datos en la plataforma.



Finalmente, el dispositivo apareció con el estado ONLINE y asociado a la red “iPhone”, confirmando su conexión con Arduino Cloud.

# Actividad 04: Monitoreo de temperatura mediante ThingSpeak

## Procedimiento realizado

Se utilizó el sensor de temperatura LM35 conectado al ESP32 para registrar sus mediciones en ThingSpeak.

1. **Lectura del sensor:** Se programó el ESP32 para obtener la lectura del ADC, convertirla a voltaje y calcular la temperatura del LM35.

2. **Conexión WiFi:** Se configuró la conexión del ESP32 a una red con acceso a Internet para enviar las mediciones a la plataforma.

3. **Configuración de ThingSpeak:** Se utilizó un canal y se destinó el campo 1 al registro de temperatura, con el gráfico titulado “Temperatura LM35”.

4. **Envío de datos:** Se empleó la función `ThingSpeak.writeField()` para enviar la temperatura utilizando el identificador del canal y la clave de escritura. El programa incluyó una espera de 15 segundos entre envíos.

5. **Verificación:** Se revisaron los mensajes del monitor serial y el gráfico del canal para comprobar la recepción de las mediciones.

## Resultados



En el monitor serial se muestran las lecturas del sensor y mensajes de envío de temperatura a ThingSpeak. El código verifica la respuesta del servidor y muestra un mensaje de confirmación cuando recibe el código 200.



En ThingSpeak se observa el gráfico “Temperatura LM35” y un total de 98 registros en el canal al momento de la captura. Esto confirma que la plataforma recibió datos y permitió visualizar las mediciones de temperatura a lo largo del tiempo.

# Actividad 05: Control remoto de un LED desde Ubidots

## Descripción de la actividad

1. **Configuración del control web:** Se creó un botón virtual en el dashboard de Ubidots para enviar las órdenes de encendido y apagado al ESP32.

2. **Conexión del LED:** Se conectó un LED rojo en la placa de pruebas junto al ESP32, utilizando una resistencia limitadora y un pin digital configurado como salida.

3. **Programación del ESP32:** Se configuró la conexión WiFi y la recepción de las órdenes de control para cambiar el estado del LED desde la plataforma.



Se configuró un botón virtual en Ubidots para enviar órdenes de control al ESP32. Este botón permite seleccionar el encendido o apagado del LED desde la plataforma web.

## Resultados e interpretación

Al activar el botón virtual en Ubidots, se envió una orden por Internet al ESP32 y el LED rojo se encendió. Al desactivar el botón, el dispositivo recibió la orden de apagado.

Esta prueba permitió comprobar la comunicación entre la plataforma web y el ESP32, así como el control remoto de un actuador mediante Internet.



El LED rojo conectado al ESP32 se encendió al recibir la orden enviada desde Ubidots. Este resultado demuestra la comunicación entre la plataforma web y el dispositivo para controlar un actuador a distancia.

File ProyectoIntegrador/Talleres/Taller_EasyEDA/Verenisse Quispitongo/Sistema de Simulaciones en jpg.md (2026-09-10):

**ELABORADO POR:** Verenisse Quispitongo

**MODULO SENSOR DE TURBIDEZ**
---

## 1. Versión Soldadura por Agujeros
| Vista | Tipo de Imagen | Descripción |
| :---: | :--- | :--- |
|  | **Esquemático General** | Diagrama eléctrico basado en el microcontrolador ESP32-WROOM-32 y un módulo óptico para la medición de turbidez, compuesto por un LED emisor y un fototransistor PT334-6C. La señal obtenida es enviada a una entrada del ESP32 para su procesamiento. |
|  | **Diseño de PCB (Layout)** | Distribución de los componentes del sistema en la tarjeta PCB, incluyendo el ESP32-WROOM-32, resistencias, LED y fototransistor utilizados para el módulo de turbidez, junto con sus respectivas conexiones y plano de tierra GND. |
|  | **Render 3D** | Modelo tridimensional de la tarjeta electrónica diseñada en EasyEDA, mostrando la disposición física del ESP32 y los componentes correspondientes al módulo óptico de medición de turbidez. |

---

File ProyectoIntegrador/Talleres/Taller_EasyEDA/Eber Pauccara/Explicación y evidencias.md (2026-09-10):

# Sistema de Monitoreo de Temperatura Subacuática

**ELABORADO POR:** Eber P.H.  
**PROYECTO:** PCB_Modulo_Sensores  

A continuación se presenta el desarrollo del circuito electrónico en EasyEDA para el **Módulo PCB — Sistema de Medición**, correspondiente a la versión de fabricación **THT** (Through-Hole Technology / tecnología de perforación e inserción).

---

| Vista | Tipo de Imagen | Descripción |
| :---: | :--- | :--- |
|  | **Esquemático General THT** | Diagrama eléctrico dividido en Módulo de Temperatura (sensor DS18B20 y resistencia de 4.7kΩ), Módulo de Procesamiento (Arduino Nano) y Módulo de Visualización (conector I2C). |
|  | **Diseño de PCB (Layout) THT** | Placa con perforaciones (*pads through-hole*) para los pines del Arduino Nano, sensor U1 en empaque TO-92, resistencia R1, conector I2C H2 y serigrafía institucional. |
|  | **Render 3D THT** | Visualización tridimensional de la tarjeta ensamblada con el módulo Arduino Nano sobre conectores tipo header, resistencia axial de carbón y conectores de interfaz. |

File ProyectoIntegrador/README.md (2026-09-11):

<div align="center">

<!-- Banner animado (capsule-render funciona nativo en GitHub, sin GIFs pesados) -->


<!-- Texto tipo "máquina de escribir" (animado, se genera al vuelo) -->
<a href="#-qué-va-a-consistir-el-proyecto">
  Typing SVG
</a>

<br/><br/>






</div>

---

## 📚 Tabla de contenidos

- [¿Quiénes somos?](#-quiénes-somos)
- [Justificación técnica y fundamento biológico](#️-justificación-técnica-y-fundamento-biológico)
- [¿En qué consiste el proyecto?](#-en-qué-va-a-consistir-el-proyecto)
- [Perfil de medición multinivel](#perfil-de-medición-multinivel-en-la-columna-de-agua)
- [Validación de campo: Santa Eulalia](#-contexto-de-aplicación-y-validación-de-campo-santa-eulalia)
- [Problemáticas que soluciona](#-qué-problemáticas-soluciona)
- [Alineación con los ODS](#-alineación-con-objetivos-de-desarrollo-sostenible-ods)
- [Matriz de parámetros técnicos](#-matriz-de-parámetros-técnicos-de-medición-agua-dulce)
- [Equipo](#-integrantes)

---

## 🌍 ¿Quiénes somos?

Somos participantes del curso **Proyecto Integrador 2026-2**, integrados por estudiantes de Ingeniería Industrial e Informática de la **Universidad Peruana Cayetano Heredia**. Nuestra misión es utilizar la metodología de diseño para desarrollar soluciones creativas y técnicamente fundamentadas que aporten valor social, tecnológico y ambiental.

<p align="center">
  
</p>

---

## ⚙️ Justificación Técnica y Fundamento Biológico

Para validar técnicamente el desarrollo de **FISHMON 365**, nos basamos en la normativa e investigación oficial del **Fondo Nacional de Desarrollo Pesquero (FONDEPES – PRODUCE, Perú)**.

### 1. Especie cultivada y taxonomía

| Campo | Detalle |
|---|---|
| **Especie de crianza** | Trucha Arco Iris |
| **Nombre científico oficial** | *Oncorhynchus mykiss* (antes *Salmo gairdneri irideus*) |
| **Ambiente de cultivo** | Agua dulce continental (ríos, arroyos, manantiales y lagunas) |

### 2. Sistemas de acuicultura en el Perú y diagnóstico de mortalidad

| Criterio Técnico | Sistema Convencional (Estanquería) | Sistema No Convencional (Jaulas Flotantes) |
|---|---|---|
| **Infraestructura principal** | Estanques de concreto, mampostería de piedra y tierra | Jaulas flotantes en lagos y lagunas |
| **Distribución regional** | Mayor prevalencia en la Región Junín | Predominante en la Región Puno (98% de esta modalidad) |
| **Aporte a la producción nacional (2012)** | Junín: 3,412.53 TM/Año (13.78%) | Puno: 18,471.02 TM/Año (74.59%) |
| **Variabilidad del medio** | Vulnerable a fluctuaciones de caudal, temperatura y arrastre de sólidos por lluvias | Vulnerable a eventos de anoxia global en la columna de agua |

### 3. Causa principal de mortalidad: asfixia e hipoxia por deficiencia de oxígeno disuelto (O₂)

La mayor tasa de mortandad o pérdida de rendimiento biológico-económico en los cultivos de trucha se debe a la pérdida del equilibrio entre el Hospedador, el Patógeno y el Ambiente (**H + P + A = E**).

<details>
<summary><b>📖 Ver cita textual del manual FONDEPES</b></summary>
<br/>

> *"Como la crianza se realiza a grandes densidades es recomendable que la cantidad de oxígeno no sea menor a 5.5 mg/l (60% de saturación de oxígeno) en los momentos de máximo consumo en el cultivo, ya que de lo contrario los peces van a presentar signos de asfixia".*
>
> *"Pueden presentarse peces con hipoxia, aunque haya suficiente oxígeno en el medio de cultivo por la presencia de nitritos".*

</details>

---

## 🌿 ¿En qué va a consistir el proyecto?

**FISHMON 365** es un **dispositivo multiparámetro portátil y autónomo** diseñado para el **monitoreo en tiempo real y a multinivel** de la calidad del agua dulce en sistemas de cultivo de trucha (*Oncorhynchus mykiss*).

El sistema está compuesto por una **sección flotante con electrónica blindada** y una **sonda sumergible vertical multinivel**, equipada con sensores calibrados para realizar lecturas continuas a tres profundidades distintas dentro de la columna de agua. Toda la información capturada es procesada y transmitida de forma inalámbrica mediante tecnología **IoT** directamente a una **aplicación móvil para smartphone**, enviando alertas tempranas en tiempo real ante variaciones fuera de los rangos seguros.

Para garantizar la continuidad operativa en zonas rurales o ante posibles cortes de energía eléctrica, el equipo integra un **sistema de alimentación autónomo con batería de respaldo**, asegurando mediciones ininterrumpidas las 24 horas del día.

### Perfil de medición multinivel en la columna de agua

Dado que parámetros críticos como el oxígeno disuelto y la temperatura varían verticalmente según la dinámica del estanque, la descomposición de materia orgánica y el nivel de alimentación, **FISHMON 365** monitorea tres estratos clave:

| Profundidad / Estrato | Justificación Técnica Biológica | Impacto en la Trucha Arco Iris |
| :--- | :--- | :--- |
| **Superficie** | Zona de mayor intercambio gaseoso atmosférico e incidencia de radiación solar | Evalúa la temperatura máxima y la saturación inicial de oxígeno |
| **Nivel Medio (Media Agua)** | Zona de natación activa y desplazamiento del cardumen de truchas en crecimiento | Garantiza que la masa de agua habitada mantenga tenores de O₂ ≥ 5.5 mg/L |
| **Nivel de Fondo (Suelo acuícola)** | Zona de acumulación de alimento no consumido, heces, materia orgánica | Detecta zonas anóxicas (O₂ < 3.0 mg/L), gas metano/nitritos y variaciones de pH |

<p align="center">
  
</p>

---

## 🌿 Contexto de Aplicación y Validación de Campo: Santa Eulalia

Para validar el prototipo en condiciones reales de campo de la sierra de Lima, el dispositivo se probará en las piscigranjas de agua dulce del distrito de **Santa Eulalia** (Provincia de Huarochirí, Lima):

- **Ubicación de prueba:** Valle del río Santa Eulalia (afluente del río Rímac)
- **Altitud de evaluación:** Entre 1,036 y 1,400 m.s.n.m. (zona de cuenca media)
- **Características hídricas:** Aguas continentales dulceacuícolas lóticas (río y arroyos de deshielo/manantial)
- **Impacto ambiental local:** Permite monitorear la variación de temperatura y oxígeno disuelto en temporadas de estiaje vs. avenidas (lluvias), previniendo el estrés branquial y mortandades masivas

---

## 🌿 ¿Qué problemáticas soluciona?

| Problema Actual en la Truchicultura | Solución Técnica que Aporta FISHMON 365 | Sustento Oficial (FONDEPES) |
|---|---|---|
| Altas mortandades por asfixia silenciosa (O₂ < 5.5 mg/L) | Monitoreo continuo de Oxígeno Disuelto con alertas sonoras/visuales inmediatas | A menores niveles de O₂ (0–3.0 mg/L) la trucha muere; entre 3.1–4.5 mg/L sufre grave estrés |
| Elevados costos de equipos comerciales de laboratorio | Diseño portátil de bajo costo con componentes e integración local | Acceso a tecnología para productores de subsistencia y menor escala (99.44% del mercado) |
| Mediciones manuales extemporáneas que no previenen crisis | Lectura inmediata en campo con diagnóstico automático vía IoT | Permite ajustar la tasa de recambio de agua por hora (R/A/H) |
| Falta de conectividad en zonas altoandinas/rurales | Funcionamiento offline con almacenamiento SD y sincronización posterior IoT | Registro histórico sin depender de cobertura celular continua |
| Falta de estandarización técnica del criador | Configuración de umbrales bajo la NTP y manuales de PRODUCE/FONDEPES | Ajustado a los rangos óptimos del agua para *Oncorhynchus mykiss* |

---

## 🌿 Alineación con Objetivos de Desarrollo Sostenible (ODS)

<table>
<tr>
<td width="33%" align="center" valign="top">

**🏭 ODS 9**
Industria, Innovación e Infraestructura

**Meta 9.5:** Aumentar la investigación científica y la capacidad tecnológica de los sectores industriales, fomentando la innovación e incrementando el número de personas en I+D.

</td>
<td width="33%" align="center" valign="top">

**♻️ ODS 12**
Producción y Consumo Responsables

**Meta 12.a:** Fortalecer la capacidad científica y tecnológica de los países en desarrollo hacia modalidades de consumo y producción más sostenibles.

</td>
<td width="33%" align="center" valign="top">

**🌊 ODS 14**
Vida Submarina y Recursos Hídricos

**Metas 14.7 / 14.a:** Aumentar los beneficios económicos del uso sostenible de recursos dulceacuícolas y fortalecer la capacidad de investigación para la salud de los ecosistemas acuáticos.

</td>
</tr>
</table>

---

## 🌿 Matriz de Parámetros Técnicos de Medición (Agua Dulce)

Basado estrictamente en las especificaciones del *Manual de Cultivo de Trucha* – FONDEPES:

| Parámetro Fisicoquímico | Rango Crítico / Letal | Rango Óptimo de Cultivo | Impacto Biológico en la Trucha Arco Iris |
|---|---|---|---|
| **Oxígeno Disuelto (O₂)** | < 3.0 mg/L (muerte)<br>3.1–4.5 mg/L (estrés grave) | 6.0–8.5 mg/L (mínimo 5.5 mg/L) | Asfixia, reducción del consumo de alimento y suspensión del crecimiento |
| **Temperatura (T°C)** | < 3°C o > 20°C (riesgo severo) | 11–16°C (engorde óptimo: 15–16°C; incubación: 8–10°C) | Condiciona metabolismo, apetito, crecimiento y solubilidad del O₂ |
| **Potencial de Hidrógeno (pH)** | < 6.0 o > 9.0 (incompatible con la vida) | 7.0–8.0 (ligeramente alcalino) | < 6.5 produce hemorragias branquiales y mortandades masivas |
| **Turbidez / Sólidos** | Elevados sólidos en suspensión | Agua cristalina / filtrada | Daña branquias y sofoca a los alevinos |
| **Dióxido de Carbono (CO₂)** | > 2.0 ppm | < 2.0 ppm | Merma el O₂ disuelto y altera el pH sanguíneo del pez |

---

## 📷 Fotografía del equipo

<p align="center">
  
</p>

## 🖼️ Fotografía esperada del producto

<p align="center">
  
</p>

---

## 👫 Integrantes

<div align="center">

| Foto | Nombre | Rol | Intereses |
|:---:|:---|:---|:---|
|  | **Karita John Kenneth** | Líder / Diseñador | Diseño de prototipos, hardware |
|  | **Cabrera Cermeno Ruben Andre** | Desarrollo de sistemas | Tecnología e implementación de programas |
|  | **Ccatamayo Vasquez Willy Simeon** | Programador / Modelador | Programación, simulación |
|  | **Pauccara Huancara Eber** | Encargado de Documentación | Producción de documentos científicos y técnicos |
|  | **Quispitongo Quispe Verenisse Mary** | Responsable de investigación | Gestión ambiental, desarrollo comunitario |

</div>

---

<div align="center">



**🐟 FISHMON 365 — Monitoreo inteligente para una acuicultura sostenible**




<sub>© 2026 – Universidad Peruana Cayetano Heredia</sub>

</div>

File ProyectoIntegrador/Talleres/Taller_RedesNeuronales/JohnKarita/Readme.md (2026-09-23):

## Lo aprendido:

### CNN [Convolutional Neural Network]
- Trabaja principalmente con imágenes y estas pueden aumentarse mediante transformaciones (data augmentation), salvo que dichas modificaciones puedan alterar información importante.
- Menor tiempo de ejecución cuando se utiliza GPU.
- Extrae características de las imágenes para identificar regiones relevantes, que pueden visualizarse posteriormente.




- Se puede observar de las imágenes que las áreas de los cuellos de las botellas/frascos tienen bastante influencia para la clasificación
  
### Keras
- Permite construir redes neuronales por capas de manera sencilla.
- Permite utilizar funciones de activación como tangente hiperbólica, ReLU y sigmoide.
- Puede reducir el sobreajuste mediante dropout, desactivando aleatoriamente algunas neuronas durante el entrenamiento.
  
### Perceptrón
- Realiza el producto punto entre las entradas y los pesos, y suma un sesgo (bias).
- Puede realizar operaciones como AND y OR, pero no XOR con un solo perceptrón.
- Utiliza una función de activación.


- Para que realice la discriminación tipo XOR requiere ambos perceptrones y definir una región entre ellos dos, como se detalla arriba.

## ¿Cuál utilizaría para el proyecto?
- Utilizaría perceptrones para obtener los parámetros (Tiempo, PH, DO, Temperatura, Turbidez y conductividad) y simplemente una salida que decida advertir o no, sería un punto inicial.
- Para características más refinadas o con variables más difíciles de pesar utilizaría Keras para construir una red más compleja. Solo tendría que recopilar un buen dataset y evitar el sobreajuste.

## ¿Es necesario la inteligencia artificial?
- Realísticamente advertir según límites no requiere una inteligencia artificial muy sofisticada, pero, para predecir posibles causantes de contaminantes asociando dos o más valores sí puede resultar útil.
- Podría haber observaciones adicionales al agua, como la presencia de espuma o el color presente, sería como un dato adicional.

### Ejemplo 1:
- Detección de sensores: PH alto, conductividad alta, ligera turbidez
- Observación: Presencia de espuma
- Posible contaminante: Detergentes

### Ejemplo 2:
- Detección de sensores: PH bajo, conductividad alta
- Observación: Ninguna
- Posible contaminante: Ácidos descartados incorrectamente

### Ejemplo 3:
- Detección de sensores: PH bajo, temperatura alta, oxígeno disuelto decreciente con el tiempo, turbidez alta, conductividad alta
- Observación: Agua turbia y maloliente
- Posible contaminante: Aguas residuales

### Notas:
- Estos ejemplos, pese a no detallar rangos exactos, representan el tipo de tareas que podría desempeñar un modelo de redes neuronales, requiriendo una clasificación, por así decirlo.
- No son asociaciones definitivas y tienen únicamente el fin de ilustrar la clasificación de patrones más complejos.

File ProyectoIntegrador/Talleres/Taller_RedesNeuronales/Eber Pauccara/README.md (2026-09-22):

### Resumen de la sesión: CNN, Clasificación con Keras,  Perceptrón y aplicacion en Fishmon 365
---
> Taller de Redes Neuronales — Fundamentos de CNN, Keras y Perceptrón aplicados a un caso de clasificación de residuos, análisis de texto y compuertas lógicas.
---

## Parte 1: Redes Neuronales Convolucionales (CNN)

### Conceptos generales

Una CNN es un tipo de inteligencia artificial diseñada para analizar imágenes. A diferencia de otros métodos, no revisa los puntos de una foto de forma aislada, sino que analiza zonas cercanas entre sí, de manera similar a cómo el ojo humano reconoce formas y patrones.

### Proceso de funcionamiento

| Etapa | Qué ocurre |
|---|---|
| Convolución | Un filtro pequeño ("kernel") recorre la imagen detectando rasgos simples: bordes, cambios de color, texturas. En capas más profundas, estos rasgos se combinan para reconocer formas completas. |
| Activación (ReLU) | Se descartan los rasgos que no aportan información relevante y se conservan los que sí. Esto permite que el modelo aprenda relaciones más complejas que una simple suma de valores. |
| Reducción (Pooling) | La información se resume, conservando lo esencial y descartando detalles menores. Esto acelera el procesamiento y evita que el modelo dependa de detalles insignificantes. |
| Capas finales (densas) | Toda la información recolectada se combina para producir una decisión final: a qué categoría pertenece la imagen. |

### Aplicación práctica: clasificación de vidrio y plástico

Se entrenó una CNN desde cero para distinguir imágenes de vidrio y plástico, utilizando el dataset TrashNet (organizado mediante el script `trash_dataset.py`, que separa las imágenes en 70% para entrenamiento, 15% para validación y 15% para prueba final).

| Resultado obtenido | Descripción |
|---|---|
| Curvas de entrenamiento | Muestran la evolución del error y de la precisión del modelo a lo largo de las rondas de entrenamiento. |
| Matriz de confusión | Resume los aciertos y errores del modelo al clasificar las imágenes de prueba, evidenciando un desempeño limitado en esta primera versión. |

### Mejora mediante Transfer Learning

Se incorporó un modelo previamente entrenado con un gran volumen de imágenes generales, ajustando únicamente su parte final al problema específico de vidrio y plástico. Esta estrategia produjo mejores resultados que el entrenamiento desde cero, con menor esfuerzo y menos datos necesarios.

### Aumento de datos (Data Augmentation)

Se generaron variaciones artificiales de las imágenes existentes (giros, cambios de orientación) para evitar que el modelo memorizara posiciones específicas en lugar de aprender el patrón real de cada material.

### Interpretabilidad (Grad-CAM)

Se aplicó una técnica que genera un mapa de calor sobre la imagen, señalando qué zona utilizó el modelo para tomar su decisión. Esto permite verificar si el modelo está basando su clasificación en información relevante.

---

## Parte 2: Clasificación binaria con Keras

### Descripción del problema

Se trabajó con un conjunto de reseñas de películas, cada una etiquetada previamente como positiva o negativa, con el objetivo de que un modelo aprendiera a clasificar reseñas nuevas.

### Procesamiento de los datos

Cada reseña se transformó en una lista numérica de ceros y unos, donde cada posición indica la presencia o ausencia de una palabra determinada del vocabulario. Esta representación numérica es la que el modelo utiliza como entrada.

### Modelo y resultado

| Elemento | Detalle |
|---|---|
| Estructura | Conjunto de capas densas apiladas, que refinan progresivamente la clasificación. |
| Resultado de prueba | El modelo predijo una reseña de ejemplo como positiva con 99.4% de confianza. |

### Comparaciones y ajustes

| Prueba realizada | Propósito |
|---|---|
| Modelo más pequeño | Evaluar si un modelo con menos capacidad generaliza mejor o peor que el original. |
| Regularización | Penaliza al modelo cuando se vuelve demasiado complejo, evitando que memorice en exceso los datos de entrenamiento. |
| Dropout | Desactiva neuronas al azar durante el entrenamiento, distribuyendo el aprendizaje en toda la red en lugar de concentrarlo en unas pocas unidades. |

Ambas técnicas (regularización y Dropout) buscan el mismo objetivo: que el modelo mantenga un buen desempeño frente a datos nuevos, no solo frente a los datos ya vistos.

---

## Parte 3: Perceptrón

### Concepto

El perceptrón es la unidad más elemental de una red neuronal: una sola neurona artificial que recibe varias entradas, las pondera según su importancia y produce una salida.

### Funciones de decisión utilizadas

| Función | Comportamiento |
|---|---|
| Escalón | Respuesta binaria estricta: 0 o 1, sin valores intermedios. |
| Tanh | Respuesta entre -1 y 1, permitiendo expresar distintos niveles de certeza. |

### Caso aplicado

Se utilizó un perceptrón para simular una alerta de sobrecalentamiento en un equipo industrial, a partir de ciertos factores de entrada. En las pruebas realizadas, el resultado indicó ausencia de alerta con ambas funciones de activación.

### Compuertas lógicas

| Compuerta | Resultado con el perceptrón simple |
|---|---|
| AND | Resuelta correctamente. |
| OR | Resuelta correctamente. |
| XOR | No pudo resolverse; no existe una única línea recta capaz de separar correctamente los casos. |

Esta limitación es la razón histórica por la cual se desarrollaron las redes con múltiples capas: conectando varias neuronas es posible combinar distintas líneas de separación y resolver problemas que una sola neurona no puede resolver por sí sola.

---

## Imágenes del documento

| N° | Sección correspondiente | Qué muestra y qué significa |
|---|---|---|
| 1 |   | Son las fotos de vidrio y plástico usadas para entrenar el modelo. No mide ningún resultado, solo confirma con qué datos se trabajó. Las fotos están claras y bien etiquetadas, lo cual es necesario para que el modelo tenga una base decente de aprendizaje. |
| 2 |  | La curva de error casi no baja y la precisión se mantiene plana durante varias rondas, subiendo recién al final. El modelo entrenado desde cero no aprendió bien, el resultado no es bueno. |
| 3 | | La matriz muestra 38 aciertos y 38 errores en vidrio, 44 aciertos y 29 errores en plástico. Los aciertos y los errores están muy parejos, el modelo casi no logra diferenciar mejor que adivinando al azar. |
| 4 |  | El mapa de calor marca el cuerpo central de la botella como la zona que usó el modelo para decidir que era vidrio. Esa zona tiene sentido para un ojo humano también, es una señal de que el modelo miró algo razonable y no algo irrelevante como el fondo. |
| 5 |  | El error de entrenamiento baja todo el tiempo, pero el error de validación empieza a subir cerca de la ronda 5. El modelo empieza a memorizar las reseñas que ya vio en vez de aprender el patrón general. |
| 6 | | El modelo más pequeño llega a su punto más bajo de error antes y se mantiene un poco más estable que el original. Con menos neuronas el modelo generaliza mejor en este caso, no peor. |
| 7 |  | El modelo con regularización sigue subiendo su error con el tiempo, aunque de forma menos brusca que el original. Ayuda, pero no resuelve el problema por completo. |
| 8 |  | El modelo con dropout arranca peor pero su curva sube de forma más pareja, sin el salto brusco que tiene la regularización. Es más estable, aunque también termina subiendo con el tiempo. |
| 9 | | La línea verde separa los casos de AND, la línea roja separa los casos de OR. Ambas compuertas quedan resueltas porque una sola línea recta logra dejar los casos verdaderos de un lado y los falsos del otro. |
| 10 |  | Las líneas azules intentan separar los casos de XOR. Los puntos verdaderos (0,1) y (1,0) quedan en esquinas opuestas, y los falsos (0,0) y (1,1) también en esquinas opuestas entre sí. Ninguna línea recta logra dejar todos los verdaderos de un lado, por eso XOR no se resuelve con un solo perceptrón. |

---

## Aplicación al proyecto FISHMON 365

FISHMON 365 es una boya flotante autónoma, los sensores están selladas herméticamente en un recipiente cilíndrico, con los sensores de pH, temperatura, oxígeno disuelto y turbidez expuestos al agua en y a  distintas alturas. No tiene cámara ni conexión constante a internet porque trabaja en el campo.

| Herramienta | ¿Aplica? | Justificación |
|---|---|---|
| Perceptrón | Sí | El perceptrón recibe varias entradas numéricas, las pondera y da una salida de alerta o no alerta, exactamente el mismo caso que la alarma de sobrecalentamiento del equipo industrial ya trabajada. Aquí las entradas serían las lecturas de pH, temperatura, oxígeno disuelto y turbidez, y la salida sería agua en condición normal. Es simple, no necesita imágenes ni grandes volúmenes de datos, y puede correr en un microcontrolador dentro de la caja sellada. |
| Clasificación con Keras (tipo reseñas) | No | Ese modelo está pensado para textos largos con miles de palabras posibles como entrada, un problema mucho más grande que decidir con cuatro o cinco lecturas de sensores. Usar una red así sería más complejidad de la necesaria para este caso, el perceptrón ya cubre lo que se necesita. |
| CNN | No | La CNN necesita imágenes para funcionar, y la boya no tiene cámara, solo sensores. Tampoco tiene sentido depender de ella porque el dispositivo trabaja en campo sin conexión constante a internet, y este tipo de modelo suele necesitar más capacidad de procesamiento de la que tendría un dispositivo sellado y autónomo como este. |

---

## Conclusiones

- De las tres herramientas del taller, solo el perceptrón encaja de forma directa con FISHMON 365, porque el proyecto trabaja con unas pocas lecturas numéricas de sensores y necesita una decisión simple: alerta o no alerta.
- La clasificación con Keras usada en el taller (reseñas de texto) no aplica, ese problema maneja un volumen de datos mucho mayor al que maneja la boya con sus sensores.
- La CNN tampoco aplica, la boya no cuenta con cámara y su condición de trabajo en campo sin internet constante hace que un modelo de ese tamaño no sea viable.
- El caso de la alarma de sobrecalentamiento resuelto con perceptrón en el taller es, en la práctica, el mismo tipo de problema que FISHMON 365 necesita resolver con sus lecturas de pH, temperatura, oxígeno disuelto y turbidez.

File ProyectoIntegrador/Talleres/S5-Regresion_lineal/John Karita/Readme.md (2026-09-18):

# Análisis de datos de calidad de aire en Iowa, Estados Unidos (2022-2023)

## Introducción

El siguiente documento detalla el análisis de la calidad de aire para predecir la concentración diaria máxima de monóxido de carbono utilizando regresión lineal, con datos obtenidos de la Agencia de Protección Ambiental (EPA por sus siglas en inglés) [1]. El análisis exploratorio fue utilizado para identificar relaciones entre variables y evaluar la capacidad predictiva.

## Metodología

El conjunto de datos presenta mediciones diarias desde el 1/1/2022 hasta 31/12/2023 de distintos lugares dentro del estado de Iowa como Birmingham del norte, FairField y Arkadelfia [1].

El objetivo fue estudiar la relación existente entre variables y observar el poder predictivo cuando al modelo de regresión lineal se le presentan variables que pueden dar lugar a fugas de información y cuando se remueven dichas variables.

Para el caso 1 se seleccionaron las siguientes variables:

Predictores:
- POC
- Índice de calidad de aire diario
- número de observaciones
- Porcentaje completo
- Latitud
- Longitud
- Elevación
- Longitud de sensor
- Función seno del año
- Función coseno del año

Objetivo:
- Concentración máxima de monóxido de carbono

Para el caso 2 se removió el Índice de calidad de aire diario.

La "Concentración diaria máxima de monóxido de carbono" y el "Índice diario de calidad de aire (AQI)" presentan una muy fuerte relación (0.99), debido a que la concentración de Monóxido de Carbono es una de las variables utilizadas para el cálculo del índice AQI. Ver página 18 de [2]

## Análisis exploratorio

A partir del gráfico se observa la relación entre el Índice diario de calidad de aire (Daily AQI Value) y la concentración diaria máxima de monóxido de carbono (Daily Max CO Concentration):


## División de los datos y construcción del modelo de regresión

70% fue utilizado de entrenamiento.
30% fue utilizado de prueba.

Se utilizó un modelo de regresión lineal proveniente de la librería scikit learn.

## Resultados

### Caso 1: Con AQI (Índice de calidad de aire)
| Curva de regresión | Residuales | Distribución de residuales |
| --- | --- | --- |
|  |  |  |

### Caso 2: Sin AQI como una de las variables predictoras
| Curva de regresión | Residuales | Distribución de residuales |
| --- | --- | --- |
|  |  |  |

- En el caso 1 se puede observar que la predicción sigue a los valores actuales, pero en el caso 2 la relación lineal entre los valores reales y las predicciones se debilita considerablemente.

- En los residuales se puede observar que el rango aumenta considerablemente, pasando de (-0.125 a 0.075) a (-0.4 a 0.6).

## Conclusiones

El modelo con AQI presenta un mejor desempeño y menor rango de residuales. Al eliminar dicha variable, los errores aumentan considerablemente, evidenciando que aporta información muy relacionada con la concentración máxima de CO. Por otra parte, el segundo modelo permite evaluar mejor el poder predictivo de las demás variables.

## Referencias
[1] U.S. Environmental Protection Agency, U.S. E.P.A. Air data. [En línea]. Disponible en: https://rconnect-public.epa.gov/AirData/

[2] U.S. Environmental Protection Agency, "Technical Assistance Document for the Reporting of Daily Air Quality", U.S. E.P.A. [En línea]. Disponible en: https://document.airnow.gov/technical-assistance-document-for-the-reporting-of-daily-air-quailty.pdf

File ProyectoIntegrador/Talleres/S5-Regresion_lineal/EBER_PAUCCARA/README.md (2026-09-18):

# “Año de la Esperanza y el Fortalecimiento de la Democracia”

<br>



<br>

# INFORME TÉCNICO DE EVALUACIÓN ESTADÍSTICA Y CALIDAD DEL AIRE POR DIÓXIDO DE AZUFRE ($SO_2$) EN NORTH BIRMINGHAM (2023)

---
***Curso:*** *Proyecto Integrador*

---

### **Docentes:**

- UMBERT LEWIS DE LA CRUZ RODRIGUEZ
- VANESSA STEFANNY STEFANNY AREVALO
- RENZO JOSE CHAN RIOS

---

### **Integrante:**

- Eber Pauccara Huancara

<br>

### **2026**

### **Lima – Perú**

## ÍNDICE

1. **Introducción**
   * 1.1 Contexto Institucional y Origen Factual de los Datos
   * 1.2 Justificación del Análisis de Dióxido de Azufre ($SO_2$)
   * 1.3 Objetivos del Estudio
2. **Metodología y Configuración Instrumental**
   * 2.1 Ubicación Geográfica y Estaciones de Monitoreo
   * 2.2 Métodos Instrumentales de Medición de la EPA
   * 2.3 Definición de Variables Técnicas y Filtros Estadísticos
   * 2.4 Formulación y Algoritmos Estadísticos Aplicados
3. **Resultados e Interpretación Exhaustiva**
   * 3.1 Caracterización Estadística Global del Dataset
   * 3.2 Análisis de Distribución de Frecuencias y Cuantiles
   * 3.3 Evaluación Técnica de Anomalías (Valores Negativos y Deriva del Cero)
   * 3.4 Análisis de Eficiencia Operativa y Completitud de Datos
4. **Discusión**
   * 4.1 Evaluación Comparativa frente a la Normativa de Salud Pública
   * 4.2 Dinámica Instrumental y Explicación del Comportamiento Sensórico
5. **Conclusiones**
6. **Referencias [IEEE]**

---

## 1. INTRODUCCIÓN

### 1.1 Contexto Institucional y Origen Factual de los Datos
El presente informe técnico se fundamenta en los registros primarios extraídos del **Air Quality System (AQS)**, la base de datos centralizada de la **Agencia de Protección Ambiental de los Estados Unidos (US EPA)** [1]. 

Los datos analizados corresponden a la medición continua de dióxido de azufre ($SO_2$) recolectada del 1 de enero al 31 de diciembre del año 2023 en la estación de monitoreo ambiental ubicada en **North Birmingham**, en el condado de Jefferson, Alabama [1], [2].

* **País / Estado / Condado:** Estados Unidos / Alabama (FIPS: 01) / Condado de Jefferson (FIPS: 073) [1].
* **Área Estadística Metropolitana (CBSA):** Birmingham-Hoover, AL (Código CBSA: 13820) [1].
* **Identificadores Únicos de Estación (Site ID):** 
  * Estación Principal: `01-073-0023` (North Birmingham) [1].
  * Estación Adyacente de Control: `01-073-1003` [1].
* **Código de Parámetro del Contaminante:** `42401` (Dióxido de Azufre / $SO_2$) [1].



La **Figura 1** ilustra la localización estratégica de la estación de monitoreo dentro del entramado urbano de North Birmingham. El emplazamiento del sitio `01-073-0023` permite capturar de forma representativa la exposición atmosférica real de la población local, considerando la proximidad a vías de transporte con tráfico pesado e instalaciones industriales históricas de la zona [2], [3].

### 1.2 Justificación del Análisis de Dióxido de Azufre ($SO_2$)
El dióxido de azufre es un gas incoloro, de olor penetrante y altamente reactivo, clasificado como uno de los seis contaminantes criterio primarios regulados por la Ley de Aire Limpio (*Clean Air Act*) [2]. Se origina fundamentalmente durante la combustión de insumos fósiles con presencia de azufre (como carbón y diésel) en plantas termoeléctricas, fundiciones y complejas instalaciones industriales [2], [4].

La exposición a concentraciones elevadas de $SO_2$, incluso durante intervalos breves de $5$ a $10$ minutos, desencadena la constricción de las vías respiratorias en personas astemáticas o sensibles, provocando un incremento directo en los ingresos hospitalarios de emergencia [2], [4]. Por esta razón, el monitoreo continuo de la concentración máxima diaria de $1\text{ hora}$ constituye un requerimiento técnico fundamental para la protección de la salud pública.

### 1.3 Objetivos del Estudio

#### Objetivo General
Evaluar la calidad del aire mediante el análisis estadístico riguroso de las concentraciones de dióxido de azufre ($SO_2$) registradas en la estación North Birmingham durante el año 2023, determinando el grado de cumplimiento normativo y la estabilidad de la red de monitoreo.

#### Objetivos Específicos Estadísticos
1. **Caracterización de Tendencia Central y Dispersión:** Calcular la media ($\mu$), desviación estándar ($\sigma$), mediana ($P_{50}$), percentiles ($P_{25}, P_{75}$) y valores extremos para las $712$ observaciones recopiladas en 2023 [1].
2. **Evaluación del Índice de Calidad del Aire (AQI):** Cuantificar la distribución del valor diario de AQI (*Daily AQI Value*) para determinar la categoría de riesgo en la población [1], [2].
3. **Control de Calidad e Integridad de Muestreo:** Analizar el porcentaje de completitud (*% Completeness*) para verificar el cumplimiento del criterio de suficiencia de datos del $75\%$ exigido por la EPA [3].
4. **Diagnóstico Instrumental de Anomalías:** Explicar el origen de las lecturas negativas (hasta $-0.5 \text{ ppb}$) asociadas al ruido de línea base y deriva del punto cero en los fotómetros de fluorescencia ultravioleta [3], [5].

---

## 2. METODOLOGÍA Y CONFIGURACIÓN INSTRUMENTAL

### 2.1 Ubicación Geográfica y Estaciones de Monitoreo

Tabla 1: *Parámetros operacionales y de localización de la estación de monitoreo.*

| Parámetro Geográfico / Administrativo | Detalle de Identificación | Referencia |
| :--- | :--- | :---: |
| **Entidad Reguladora** | US Environmental Protection Agency (EPA) - Región 4 | [1] |
| **Estado / Condado** | Alabama (FIPS: 01) / Jefferson County (FIPS: 073) | [1] |
| **Área Urbana (CBSA)** | Birmingham-Hoover, AL (13820) | [1] |
| **Estación Principal (Site ID)** | `01-073-0023` (North Birmingham) | [1] |
| **Estación Adyacente (Site ID)** | `01-073-1003` | [1] |
| **Código de Parámetro** | `42401` ($SO_2$) | [1] |
| **Frecuencia de Muestreo** | Muestreo continuo expresado como Máximo Diario de 1 hora | [1], [3] |

### 2.2 Métodos Instrumentales de Medición de la EPA
Las mediciones recolectadas provienen de analizadores automáticos operados bajo metodologías equivalentes aprobadas por la EPA (*Equivalent Methods*) [1], [3]:

1. **Método Código 100 (*UV Fluorescence*):** El aire ingresa de forma continua a una cámara de reacción donde las moléculas de $SO_2$ son irradiadas con luz ultravioleta en una longitud de onda de aproximadamente $214 \text{ nm}$ [5]. Al volver a su estado fundamental, el $SO_2$ emite fotones fluorescentes cuya intensidad es medida por un tubo fotomultiplicador, siendo directamente proporcional a la concentración en el ambiente [5].
2. **Método Código 188 (*Advanced UV Fluorescence*):** Sistema óptico mejorado que incorpora tecnología digital para la compensación de interferencias por hidrocarburos aromáticos y variaciones térmicas de la lámpara UV [3], [5].




La **Figura 2** detalla la configuración instrumental de la estación. La presencia concurrente de los métodos $100$ y $188$ en los canales de control **POC 1** y **POC 2** demuestra que la estación cuenta con redundancia tecnológica [1], [3]. Esto garantiza la recolección ininterrumpida de datos aun durante periodos de mantenimiento o calibración de uno de los equipos [3].

### 2.3 Definición de Variables Técnicas
* **Concentración Diaria Máxima de $SO_2$ ($\text{ppb}$):** Es el valor más alto observado de concentración promedio de $1 \text{ hora}$ en el periodo de $24 \text{ horas}$ del día [1], [2].
* **Valor AQI Diario (Daily AQI Value):** Índice estandarizado por la EPA que convierte las concentraciones en una escala de riesgo de $0$ a $500$ [2].
* **Completitud de Datos (% Completeness):** Proporción de lecturas válidas de $1 \text{ hora}$ capturadas en el día respecto a las $24$ posibles [1], [3].

### 2.4 Formulación y Algoritmos Estadísticos Aplicados
El procesamiento de las $N = 712$ observaciones se realizó mediante la aplicación de las siguientes ecuaciones formales [1]:

* **Media Aritmética ($\mu$):**
  $$\mu = \frac{1}{N} \sum_{i=1}^{N} x_i$$

* **Desviación Estándar Muestral ($\sigma$):**
  $$\sigma = \sqrt{\frac{1}{N-1} \sum_{i=1}^{N} (x_i - \mu)^2}$$

* **Percentiles y Mediana ($P_{25}, P_{50}, P_{75}$):** Calculados a partir de la muestra ordenada de forma ascendente $x_{(1)} \le x_{(2)} \le \dots \le x_{(N)}$. El percentil $P_{k}$ representa el valor por debajo del cual se encuentra el $k\%$ de los datos.

---

## 3. RESULTADOS E INTERPRETACIÓN EXHAUSTIVA

### 3.1 Caracterización Estadística Global del Dataset
En la Tabla 2 se concentran los valores estadísticos calculados para el conjunto de observaciones del año 2023.

Tabla 2: *Resumen estadístico del monitoreo de $SO_2$, AQI y completitud de datos en North Birmingham (2023).*

| Variable Analizada | Registros ($N$) | Media ($\mu$) | Desviación Est. ($\sigma$) | Mínimo | $P_{25}$ | Mediana ($P_{50}$) | $P_{75}$ | Máximo |
| :--- | :---: | :---: | :---: | :---: | :---: | :---: | :---: | :---: |
| **Concentración $SO_2$ ($\text{ppb}$)** | $712$ | $1.7$ | $1.9$ | $-0.5$ | $0.5$ | $1.2$ | $2.1$ | $17.5$ |
| **Índice AQI Diario** | $712$ | $1.7$ | $2.7$ | $0.0$ | $0.0$ | $1.0$ | $3.0$ | $24.0$ |
| **Completitud de Datos ($\%$)** | $712$ | $98.3\%$ | $4.9\%$ | $75.0\%$ | $100.0\%$ | $100.0\%$ | $100.0\%$ | $100.0\%$ |



La **Figura 3** muestra una distribución fuertemente asimétrica hacia la derecha (sesgo positivo). La mayor densidad de observaciones se concentra de manera persistente entre $0.0$ y $2.5 \text{ ppb}$. El sesgo indica que la presencia de concentraciones más elevadas se reduce a eventos infrecuentes y acotados a lo largo del año [1].

### 3.2 Análisis de Distribución de Frecuencias y Cuantiles
Los valores centrales y de dispersión permiten caracterizar la atmósfera local:

1. **Valores Centrales:** La concentración media anual se ubicó en $1.7 \text{ ppb}$, mientras que la mediana ($P_{50}$) se registró en $1.2 \text{ ppb}$ [1]. En distribuciones con asimetría pronunciada, la mediana describe de manera más precisa el nivel habitual del entorno, al no verse distorsionada por picos esporádicos.
2. **Evaluación por Percentiles:**
   * El $25\%$ de las mediciones registradas ($P_{25}$) presentaron valores iguales o inferiores a $0.5 \text{ ppb}$ [1].
   * El $75\%$ de los días ($P_{75}$) mantuvieron concentraciones por debajo de $2.1 \text{ ppb}$ [1].
   * En términos prácticos, esto demuestra que durante tres cuartas partes del año la presencia de $SO_2$ en el aire fue prácticamente imperceptible.
3. **Variabilidad:** La desviación estándar ($\sigma = 1.9 \text{ ppb}$) resulta ligeramente superior a la media ($\mu = 1.7 \text{ ppb}$), lo que refleja la presencia de incrementos puntuales sobre una línea base consistentemente baja [1].

### 3.3 Evaluación Técnica de Anomalías (Valores Negativos y Deriva del Cero)
El análisis revela la existencia de concentraciones mínimas de **$-0.5 \text{ ppb}$** [1]. Desde la perspectiva física pura, no existen concentraciones de materia negativas en la atmósfera. Sin embargo, este resultado es un comportamiento metodológico esperado en la operación de sensores ópticos de alta precisión [3], [5].

Los analizadores de fluorescencia UV requieren calibraciones continuas del "punto cero" utilizando aire libre de contaminantes [3], [5]. Cuando el entorno real presenta concentraciones sumamente cercanas a cero, fluctuaciones menores en la temperatura interna de la caseta, ligeros cambios de voltaje o el envejecimiento natural de la lámpara UV generan desplazamientos en la señal electrónica (*zero-drift*) [3], [5].

La directiva técnica de la EPA prohíbe explícitamente truncar o reemplazar estas lecturas negativas por cero en las bases de datos primarias [3]. Forzar estos valores a cero alteraría artificialmente el promedio real de la estación, introduciendo un sesgo positivo e invalidando el cálculo estadístico estandarizado [3].

### 3.4 Análisis de Eficiencia Operativa y Completitud de Datos
El protocolo de control de calidad exige que cada día cuente con al menos el $75\%$ de mediciones horarias válidas para ser incorporado al cálculo oficial [3].

* **Desempeño Anual:** La completitud promedio de la estación alcanzó un **$98.3\%$**, registrando un valor mínimo del $75.0\%$ [1]. Esto confirma el cumplimiento riguroso de la norma de captura de datos de la EPA [3].
* **Volumen Muestral:** Los $712$ registros recopilados en un año de $365$ días corresponden al monitoreo simultáneo de los canales **POC 1** y **POC 2** [1]. Sobre un total teórico de $730$ lecturas posibles para ambos canales, la captura efectiva alcanzó el **$97.5\%$**, demostrando la alta disponibilidad de la infraestructura [1], [3].



La **Figura 4** exhibe el comportamiento temporal del AQI a lo largo del año. Todos los puntos graficados se posicionan dentro de la franja inferior del gráfico, confirmando que la calidad del aire se mantuvo dentro del rango óptimo durante todo el periodo analizado [1], [2].

---

## 4. DISCUSIÓN

### 4.1 Evaluación Comparativa frente a la Normativa de Salud Pública
El Estándar Nacional de Calidad del Aire Ambiente (**NAAQS**) de la EPA establece para el dióxido de azufre un límite primario de protección a la salud de **$75 \text{ ppb}$** en el promedio de $1 \text{ hora}$ [2].

$$\text{Proporción del Límite Promedio} = \left( \frac{1.7 \text{ ppb}}{75.0 \text{ ppb}} \right) \times 100 = 2.27\%$$

$$\text{Proporción del Límite Máximo} = \left( \frac{17.5 \text{ ppb}}{75.0 \text{ ppb}} \right) \times 100 = 23.33\%$$

El promedio anual de $1.7 \text{ ppb}$ representa apenas un **$2.27\%$** del umbral máximo permitido por la norma de salud [1], [2]. Incluso el pico más elevado de todo el año ($17.5 \text{ ppb}$, registrado con un AQI de $24$) alcanzó únicamente el **$23.33\%$** de dicho límite [1], [2]. 

Dado que el umbral para categorizar la calidad del aire como "Buena" se extiende hasta los $50$ puntos de AQI ($35 \text{ ppb}$ de $SO_2$), la totalidad de los días del año 2023 se mantuvieron dentro del rango de menor riesgo ambiental [1], [2]. Estos resultados confirman la ausencia de episodios de contaminación por $SO_2$ que representen un peligro para la población vulnerable o con afecciones respiratorias crónicas [2], [4].

### 4.2 Dinámica Instrumental y Explicación del Comportamiento Sensórico
Los incrementos aislados que distanciaron el valor máximo ($17.5 \text{ ppb}$) de la mediana habitual ($1.2 \text{ ppb}$) obedecen a dinámicas atmosféricas y de emisión locales [2], [4]:

* **Condiciones Meteorológicas Locales:** Fenómenos de inversión térmica durante las primeras horas del día o periodos de calma eólica reducen la dispersión de gases en las capas bajas de la atmósfera, acumulando temporalmente las emisiones [4].
* **Influencia de Fuentes Puntuales:** Variaciones en la dirección del viento pueden desplazar plumas de emisión provenientes de actividades industriales o corredores de carga directamente hacia la toma de muestra de la estación [2], [4].

---

## 5. CONCLUSIONES

1. **Cumplimiento de Estándares de Salud:** La estación North Birmingham registró niveles de dióxido de azufre ($SO_2$) plenamente satisfactorios durante todo el año 2023. El $100\%$ de los días se clasificaron dentro de la categoría de **Calidad del Aire Buena** ($AQI \le 50$), alcanzando un valor máximo de AQI de $24$ ($17.5 \text{ ppb}$), muy por debajo del estándar de la EPA ($75 \text{ ppb}$) [1], [2].
2. **Confiabilidad del Monitoreo:** La captura de $712$ observaciones distribuidas en dos canales independientes (POC 1 y POC 2) con un promedio de completitud del **$98.3\%$** otorga solidez estadística y representatividad técnica al análisis anual [1], [3].
3. **Explicación Metrológica:** Los valores mínimos observados de $-0.5 \text{ ppb}$ corresponden a fluctuaciones normales de la señal de cero en analizadores de fluorescencia UV bajo concentraciones extremadamente bajas, cumpliendo con los protocolos de conservación de datos de la EPA [3], [5].

---

## 6. REFERENCIAS [IEEE]

* [1] U.S. Environmental Protection Agency (EPA), "Air Quality System (AQS) Data Mart," Parameter 42401 (Sulfur Dioxide), Site IDs 01-073-0023 and 01-073-1003, Jefferson County, AL, 2023.
* [2] U.S. Environmental Protection Agency (EPA), *Primary National Ambient Air Quality Standards for Sulfur Oxides (Sulfur Dioxide)*, Code of Federal Regulations, Title 40, Part 50.17 (40 CFR Part 50.17), 2010.
* [3] U.S. Environmental Protection Agency (EPA), *Quality Assurance Handbook for Air Pollution Measurement Systems: Volume II. Ambient Air Quality Monitoring Program*, EPA-454/B-17-001, Office of Air Quality Planning and Standards, Research Triangle Park, NC, 2017.
* [4] World Health Organization (WHO), *WHO Global Air Quality Guidelines: Particulate Matter ($PM_{2.5}$ and $PM_{10}$), Ozone, Nitrogen Dioxide, Sulfur Dioxide and Carbon Monoxide*, Geneva, Switzerland: World Health Organization, 2021.
* [5] D. L. DL, *Air Monitoring Methods and Instrumentation for Atmospheric Sulfur Dioxide*, 3rd ed., Boca Raton, FL: CRC Press, 2019.

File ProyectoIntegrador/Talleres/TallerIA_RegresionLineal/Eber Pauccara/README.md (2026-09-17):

# Resumen del Análisis Exploratorio de Datos (EDA) y Proyecto de Regresión

Este documento sintetiza la estructura, el comportamiento y los hallazgos fundamentales del conjunto de datos analizado en el proyecto. Su objetivo es explicar de manera clara y rigurosa la relación entre las variables de operación y el consumo energético obtenido.

## 1. Visión General del Dataset

El análisis se basa en un conjunto de datos industrial (**Data_PI_regresion.csv**) que cuenta con **5,000 registros y 5 variables numéricas continuas**. No presenta valores nulos, lo que proporciona una base sólida para el modelado mediante Regresión Lineal Múltiple.

El objetivo principal es entender qué variables influyen de manera directa en el **Consumo de Energía** (variable dependiente o *target*) a partir de cuatro variables independientes o predictoras (variables operativas y ambientales).

## 2. Descripción de Componentes y Variables

A continuación se detalla la caracterización estadística de cada variable analizada:

| Variable | Tipo de Variable | Media (Promedio) | Rango (Mín - Máx) | Descripción y Comportamiento |
| --- | --- | ---: | ---: | --- |
| **Temperatura** | Predictora (Ambiental) | $26.5^\circ\text{C}$ | $18.0^\circ\text{C} - 35.0^\circ\text{C}$ | Registra la temperatura ambiente del entorno operativo. Muestra una distribución simétrica. |
| **Horas_Operacion** | Predictora (Operativa) | $7.0\text{ hrs}$ | $2.0\text{ hrs} - 12.0\text{ hrs}$ | Representa el tiempo activo de trabajo. Es el factor directo de mayor impacto sobre el consumo. |
| **Carga** | Predictora (Operativa) | $65.0%$ | $30.0% - 100.0%$ | Mide el porcentaje de capacidad/exigencia a la que trabaja el equipo. Presenta impacto moderado-alto. |
| **Humedad** | Predictora (Ambiental) | $65.1%$ | $40.0% - 90.0%$ | Refleja el porcentaje de humedad relativa. Muestra muy bajo impacto directo en el consumo energético. |
| **Consumo_Energia** | Objetivo (Target) | $26.0\text{ kWh}$ | $9.1\text{ kWh} - 42.6\text{ kWh}$ | Variable dependiente a predecir. Su distribución es Gaussiana (Normal) centrada en $26.0\text{ kWh}$. |

## 3. Principales Hallazgos y Patrones Encontrados

| Aspecto Analizado | Hallazgo Clave | Explicación Técnica y Práctica |
| --- | --- | --- |
| **Calidad de Datos** | Completitud del $100%$ | Las $5,000$ filas están completas, lo que elimina la necesidad de imputación de datos. |
| **Relación Principal** | Correlación Lineal Alta | Horas_Operacion muestra una fuerte pendiente positiva con Consumo_Energia. A más horas de uso, el consumo aumenta de forma lineal y constante. |
| **Relación Secundaria** | Correlación Lineal Moderada | Carga incrementa proporcionalmente la exigencia eléctrica del sistema. |
| **Independencia de Variables** | Ausencia de Multicolinealidad | Las variables predictoras no están fuertemente correlacionadas entre sí, lo que favorece la estabilidad de un modelo de regresión. |

## 4. Visualizaciones y Fotografías Referenciales

Para facilitar la interpretación del análisis exploratorio, se incluyen las visualizaciones clave generadas en el entorno del notebook.

<p align="center">
  
</p>

**Descripción:** Visión global de las relaciones cruzadas entre todas las variables del dataset (sns.pairplot). En la diagonal principal se observan las distribuciones individuales (histogramas) y en los paneles fuera de la diagonal las nubes de puntos de dispersión.

<p align="center">
  
</p>

**Descripción:** Mapa de calor de correlación de Pearson. Cuantifica en una escala de $-1$ a $+1$ la fuerza de la relación lineal entre cada par de variables.

<p align="center">
  
</p>

**Descripción:** Gráfico de dispersión (scatterplot) que detalla cómo evoluciona el Consumo_Energia conforme aumentan las Horas_Operacion, discriminando los datos mediante la variable Temperatura.

## 5. Conclusión del Proyecto

El análisis exploratorio confirma que el dataset es adecuado para la implementación de algoritmos de aprendizaje supervisado, específicamente la Regresión Lineal Múltiple. Las variables operativas (**Horas_Operacion** y **Carga**) explican la mayor parte de la varianza observada en el **Consumo_Energia**, mientras que las variables ambientales (**Temperatura** y **Humedad**) aportan matices secundarios pero útiles para ajustar la precisión de las predicciones.

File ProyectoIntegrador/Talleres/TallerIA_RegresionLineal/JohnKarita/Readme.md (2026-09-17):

## Lo visto:
- Exploración estadística de datos
- Regresión lineal múltiple
- Obtención de coeficientes, interceptos y error estándar
- Generación de datos artificiales

## Lo importante:
- Una exploración primero antes de aplicar algún método de regresión
- Los datos pseudo aleatorios con semilla definida son útiles para obtener resultados reproducibles. Importante para algún tipo de "troubleshooting"

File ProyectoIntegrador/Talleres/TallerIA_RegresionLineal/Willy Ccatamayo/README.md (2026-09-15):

# Resumen de la sesión: modelos de regresión

## ¿Qué se hizo hoy?

- Se cargaron y exploraron los datos de consumo energético mediante estadísticas descriptivas, histogramas, diagramas de dispersión y correlaciones.
- Se entrenó una regresión lineal múltiple para predecir el consumo a partir de temperatura, horas de operación, carga y humedad, utilizando un 70 % de los datos para entrenamiento y un 30 % para prueba.
- Se revisaron los coeficientes, el intercepto y un cálculo manual de errores estándar y estadísticos t. También se compararon las predicciones con los valores reales y se analizaron los residuos.
- Se generaron datos artificiales y se entrenó un árbol de decisión para regresión. Se evaluó mediante el error cuadrático medio (MSE) y se examinó la importancia de sus características.
- Se ajustó una regresión por mínimos cuadrados ordinarios (OLS) sobre los datos artificiales y se interpretó su resumen estadístico.

## ¿Qué se aprendió?

- Explorar los datos permite conocer sus características y detectar relaciones antes de construir un modelo.
- Separar entrenamiento y prueba ayuda a evaluar las predicciones sobre observaciones que el modelo no utilizó para aprender.
- Los coeficientes lineales describen cambios estimados en la respuesta, manteniendo constantes los demás predictores.
- Los residuos muestran cómo se equivoca el modelo; el MSE resume el tamaño de los errores y penaliza más los errores grandes.
- Los errores estándar, estadísticos t e intervalos de confianza ayudan a interpretar la incertidumbre de los coeficientes bajo los supuestos del modelo.

## Aspectos importantes

- **Correlación no implica causalidad** y las magnitudes de los coeficientes dependen de las unidades de las variables.
- Los gráficos de residuos permiten explorar patrones, pero no demuestran por sí solos normalidad ni varianza constante de los errores.
- El cálculo manual de errores estándar es ilustrativo: utiliza grados de libertad que no descuentan el intercepto y no considera completamente las relaciones entre predictores.
- Se implementó **un árbol de decisión, no un Random Forest**. Sus importancias no indican causalidad ni el signo de los efectos.
- El OLS final utiliza todos los datos artificiales: su R² no corresponde a una evaluación en prueba ni al consumo energético.
- La regresión del consumo se evaluó gráficamente; quedó pendiente calcular sus métricas numéricas de prueba.

**Conclusión:** Se practicó el proceso de explorar, entrenar, evaluar e interpretar modelos de regresión, reconociendo que un buen ajuste debe acompañarse de una revisión de los errores y las limitaciones del análisis.

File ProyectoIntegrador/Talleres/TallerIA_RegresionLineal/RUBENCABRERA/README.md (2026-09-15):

# Taller de Regresión Lineal - Ruben Cabrera
En este taller aprendí a construir y evaluar modelos de regresión en Python. Primero hice un análisis exploratorio (estadísticas, histogramas y correlaciones) y luego entrené una regresión lineal múltiple para predecir el consumo de energía, donde Horas_Operacion resultó ser la variable más influyente. Validé los supuestos del modelo revisando que los residuos fueran normales y homocedásticos. Después usé datos sintéticos para entrenar un árbol de decisión, lo evalué con el MSE y vi qué variables eran más importantes. Por último, con statsmodels obtuve un R2 de 0.976 y usé los p-valores para confirmar que solo X1, X2 y X3 eran significativas. Así se pudo distinguir las variables que realmente influyen en un resultado de las que solo aportan ruido.

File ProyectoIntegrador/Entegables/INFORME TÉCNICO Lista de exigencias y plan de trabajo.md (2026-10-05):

# **1\. Lista de Exigencias** 

**Tabla 1: Lista de Exigencias**

| LISTA DE EXIGENCIAS |  |  | Páginas: 7 |
| ----- | :---: | ----- | ----- |
|  |  |  | **Edición: Rev. 2** |
| **PROYECTO:** |  | **FISHMON 360 — Diseño de dispositivo portátil para el monitoreo de la calidad del agua en sistemas de cultivo de trucha.**  | **Fecha: 20/08/2026** |
|  |  |  | **Revisado: 02/10/26** |
| **CLIENTE:**  |  | **UNIVERSIDAD PERUANA CAYETANO HEREDIA** | **Elaborado: J.K,W.C,V.Q.,E.P,R.C.** |
| Fecha (cambios) | Deseo o Exigencia | **Descripción** | **Responsable** |
| 25/09/26 | E | **Función Principal:** Monitorear la calidad del agua en sistemas de cultivo de trucha mediante una boya sumergible  y detectar condiciones potencialmente desfavorables para el cultivo mediante la medición de los parámetros: pH (0-14 ±0.1), turbidez (0-1000 NTU), conductividad (0-2000 µS/cm), temperatura (0-40 °C) y oxígeno disuelto (0-30 mg/L ±0.1 mg/L).  Los datos se transmitirán de forma continua a la plataforma IoT.  | **J.K,W.C,V.Q.,E.P,R.C.** |
| 13/11/26 | E | **Geometría:** El dispositivo, junto con sus sensores y demás implementos necesarios para su operación, deberá poder ser almacenado dentro de una envolvente máximo de 40 x 9.2 x 13.7 cm, establecida como límite superior de portabilidad tomando como referencias las dimensiones del transceptor Motorola SCR-536. | **J.K. V.Q.** |
| 13/11/26 | E | **Cinemática:** El diseño y la disposición de los sensores deben garantizar una correcta inmersión y contacto con el agua del estanque. La boya debe mantener estabilidad hidrodinámica en la superficie, y el mecanismo de elevación debe posicionar la sonda en cada nivel de profundidad, manteniéndola estable durante la medición para asegurar lecturas precisas y representativas. | **V.Q.** |
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

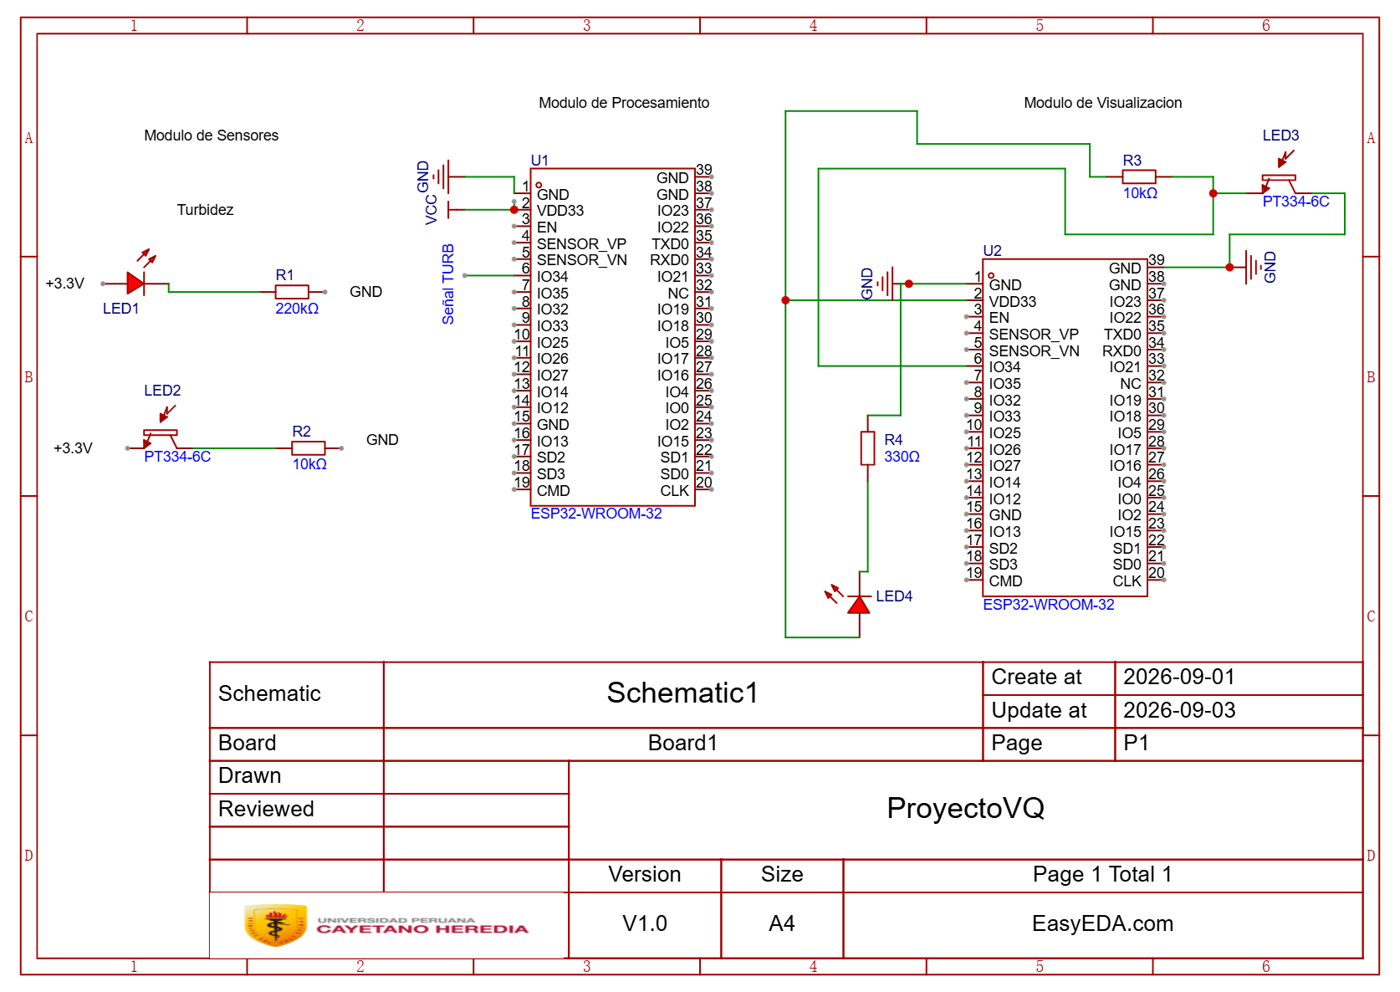
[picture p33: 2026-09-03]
Imagenes/Simulaciones/SCH_Schematic1_1-P1_2026-09-03 (1).png

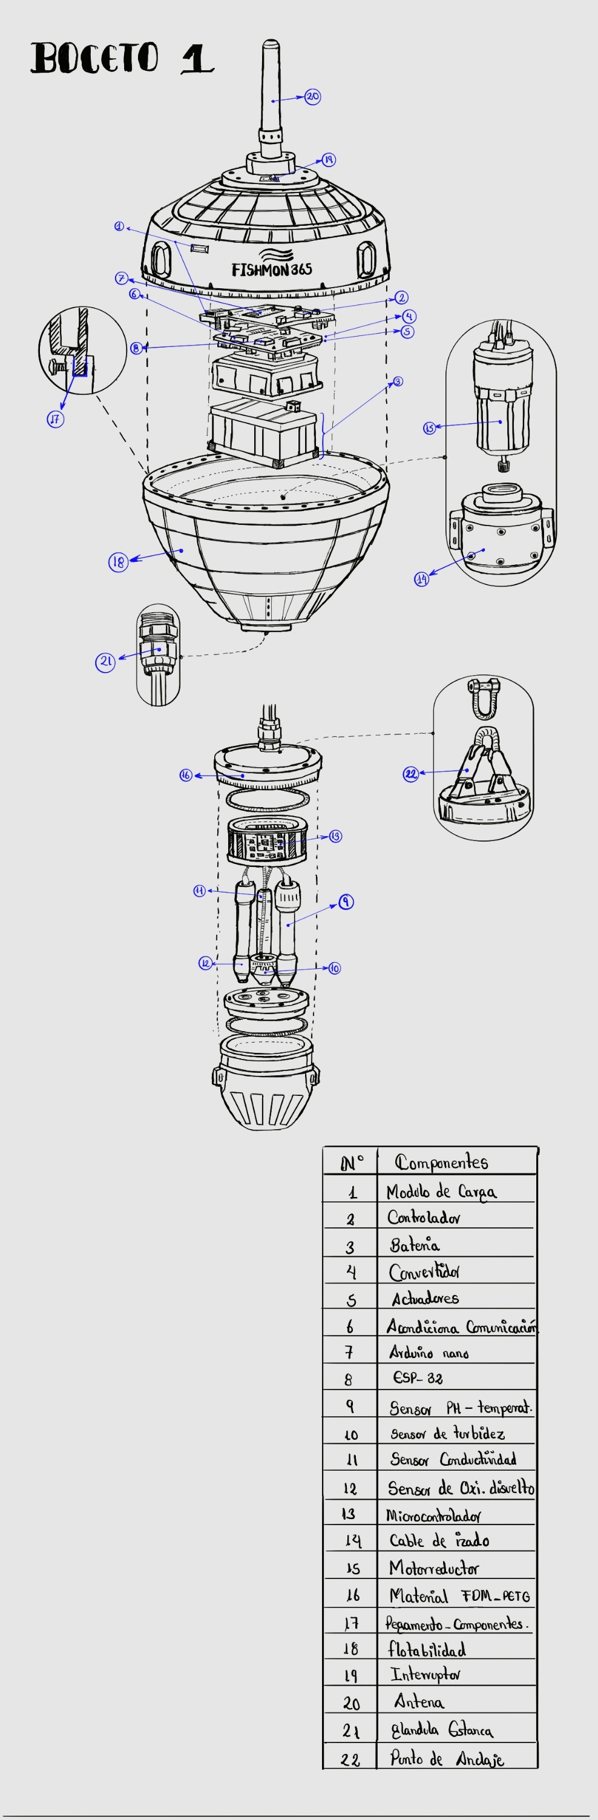
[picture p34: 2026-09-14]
Imagenes/func/Boceto.jpg

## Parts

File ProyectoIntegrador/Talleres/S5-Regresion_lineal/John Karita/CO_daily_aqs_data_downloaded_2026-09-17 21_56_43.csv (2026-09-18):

Date | Site ID | POC | Daily Max CO Concentration | Units | Daily AQI Value | Local Site Name | Daily Obs Count | Percent Complete | AQS Parameter Code | AQS Parameter Description | Method Code | Method Description | CBSA Code | CBSA Name | Site Latitude | Site Longitude | Dominant Source | Elevation (m) | Measurement Scale | Measurement Scale Definition | Monitor Type | Monitoring Agency | Monitoring Objective | NAAQS Primary Monitor? | Networks | Probe Height (m) | QA Primary Monitor?
2022-01-01 | 010730023 | 2 | 0.1 | Parts per million | 1 | North Birmingham | 19 | 79 | 42101 | Carbon monoxide | 093 | INSTRUMENTAL - GAS FILTER CORRELATION CO ANALYZER | 13820 | Birmingham-Hoover, AL | 33.553056 | -86.815 | POINT | 177 | NEIGHBORHOOD | 500 M TO 4KM | SLAMS | Jefferson County, AL Department Of Health | OTHER |  | NCORE | 17.5
2022-01-02 | 010730023 | 2 | 0.2 | Parts per million | 2 | North Birmingham | 24 | 100 | 42101 | Carbon monoxide | 093 | INSTRUMENTAL - GAS FILTER CORRELATION CO ANALYZER | 13820 | Birmingham-Hoover, AL | 33.553056 | -86.815 | POINT | 177 | NEIGHBORHOOD | 500 M TO 4KM | SLAMS | Jefferson County, AL Department Of Health | OTHER |  | NCORE | 17.5
2022-01-03 | 010730023 | 2 | 0.2 | Parts per million | 2 | North Birmingham | 12 | 50 | 42101 | Carbon monoxide | 093 | INSTRUMENTAL - GAS FILTER CORRELATION CO ANALYZER | 13820 | Birmingham-Hoover, AL | 33.553056 | -86.815 | POINT | 177 | NEIGHBORHOOD | 500 M TO 4KM | SLAMS | Jefferson County, AL Department Of Health | OTHER |  | NCORE | 17.5
2022-01-04 | 010730023 | 2 | 0.2 | Parts per million | 2 | North Birmingham | 4 | 17 | 42101 | Carbon monoxide | 093 | INSTRUMENTAL - GAS FILTER CORRELATION CO ANALYZER | 13820 | Birmingham-Hoover, AL | 33.553056 | -86.815 | POINT | 177 | NEIGHBORHOOD | 500 M TO 4KM | SLAMS | Jefferson County, AL Department Of Health | OTHER |  | NCORE | 17.5
2022-01-05 | 010730023 | 2 | 0.5 | Parts per million | 6 | North Birmingham | 9 | 38 | 42101 | Carbon monoxide | 093 | INSTRUMENTAL - GAS FILTER CORRELATION CO ANALYZER | 13820 | Birmingham-Hoover, AL | 33.553056 | -86.815 | POINT | 177 | NEIGHBORHOOD | 500 M TO 4KM | SLAMS | Jefferson County, AL Department Of Health | OTHER |  | NCORE | 17.5
2022-01-06 | 010730023 | 2 | 0.6 | Parts per million | 7 | North Birmingham | 24 | 100 | 42101 | Carbon monoxide | 093 | INSTRUMENTAL - GAS FILTER CORRELATION CO ANALYZER | 13820 | Birmingham-Hoover, AL | 33.553056 | -86.815 | POINT | 177 | NEIGHBORHOOD | 500 M TO 4KM | SLAMS | Jefferson County, AL Department Of Health | OTHER |  | NCORE | 17.5
2022-01-07 | 010730023 | 2 | 0.3 | Parts per million | 3 | North Birmingham | 24 | 100 | 42101 | Carbon monoxide | 093 | INSTRUMENTAL - GAS FILTER CORRELATION CO ANALYZER | 13820 | Birmingham-Hoover, AL | 33.553056 | -86.815 | POINT | 177 | NEIGHBORHOOD | 500 M TO 4KM | SLAMS | Jefferson County, AL Department Of Health | OTHER |  | NCORE | 17.5
2022-01-08 | 010730023 | 2 | 0.3 | Parts per million | 3 | North Birmingham | 24 | 100 | 42101 | Carbon monoxide | 093 | INSTRUMENTAL - GAS FILTER CORRELATION CO ANALYZER | 13820 | Birmingham-Hoover, AL | 33.553056 | -86.815 | POINT | 177 | NEIGHBORHOOD | 500 M TO 4KM | SLAMS | Jefferson County, AL Department Of Health | OTHER |  | NCORE | 17.5
2022-01-09 | 010730023 | 2 | 0.2 | Parts per million | 2 | North Birmingham | 24 | 100 | 42101 | Carbon monoxide | 093 | INSTRUMENTAL - GAS FILTER CORRELATION CO ANALYZER | 13820 | Birmingham-Hoover, AL | 33.553056 | -86.815 | POINT | 177 | NEIGHBORHOOD | 500 M TO 4KM | SLAMS | Jefferson County, AL Department Of Health | OTHER |  | NCORE | 17.5
2022-01-10 | 010730023 | 2 | 0.2 | Parts per million | 2 | North Birmingham | 12 | 50 | 42101 | Carbon monoxide | 093 | INSTRUMENTAL - GAS FILTER CORRELATION CO ANALYZER | 13820 | Birmingham-Hoover, AL | 33.553056 | -86.815 | POINT | 177 | NEIGHBORHOOD | 500 M TO 4KM | SLAMS | Jefferson County, AL Department Of Health | OTHER |  | NCORE | 17.5
2022-01-11 | 010730023 | 2 | 0.3 | Parts per million | 3 | North Birmingham | 11 | 46 | 42101 | Carbon monoxide | 093 | INSTRUMENTAL - GAS FILTER CORRELATION CO ANALYZER | 13820 | Birmingham-Hoover, AL | 33.553056 | -86.815 | POINT | 177 | NEIGHBORHOOD | 500 M TO 4KM | SLAMS | Jefferson County, AL Department Of Health | OTHER |  | NCORE | 17.5
2022-01-12 | 010730023 | 2 | 0.8 | Parts per million | 9 | North Birmingham | 24 | 100 | 42101 | Carbon monoxide | 093 | INSTRUMENTAL - GAS FILTER CORRELATION CO ANALYZER | 13820 | Birmingham-Hoover, AL | 33.553056 | -86.815 | POINT | 177 | NEIGHBORHOOD | 500 M TO 4KM | SLAMS | Jefferson County, AL Department Of Health | OTHER |  | NCORE | 17.5
2022-01-13 | 010730023 | 2 | 0.8 | Parts per million | 9 | North Birmingham | 24 | 100 | 42101 | Carbon monoxide | 093 | INSTRUMENTAL - GAS FILTER CORRELATION CO ANALYZER | 13820 | Birmingham-Hoover, AL | 33.553056 | -86.815 | POINT | 177 | NEIGHBORHOOD | 500 M TO 4KM | SLAMS | Jefferson County, AL Department Of Health | OTHER |  | NCORE | 17.5
2022-01-14 | 010730023 | 2 | 0.5 | Parts per million | 6 | North Birmingham | 16 | 67 | 42101 | Carbon monoxide | 093 | INSTRUMENTAL - GAS FILTER CORRELATION CO ANALYZER | 13820 | Birmingham-Hoover, AL | 33.553056 | -86.815 | POINT | 177 | NEIGHBORHOOD | 500 M TO 4KM | SLAMS | Jefferson County, AL Department Of Health | OTHER |  | NCORE | 17.5
2022-01-15 | 010730023 | 2 | 0.6 | Parts per million | 7 | North Birmingham | 24 | 100 | 42101 | Carbon monoxide | 093 | INSTRUMENTAL - GAS FILTER CORRELATION CO ANALYZER | 13820 | Birmingham-Hoover, AL | 33.553056 | -86.815 | POINT | 177 | NEIGHBORHOOD | 500 M TO 4KM | SLAMS | Jefferson County, AL Department Of Health | OTHER |  | NCORE | 17.5
2022-01-16 | 010730023 | 2 | 0.3 | Parts per million | 3 | North Birmingham | 24 | 100 | 42101 | Carbon monoxide | 093 | INSTRUMENTAL - GAS FILTER CORRELATION CO ANALYZER | 13820 | Birmingham-Hoover, AL | 33.553056 | -86.815 | POINT | 177 | NEIGHBORHOOD | 500 M TO 4KM | SLAMS | Jefferson County, AL Department Of Health | OTHER |  | NCORE | 17.5
2022-01-17 | 010730023 | 2 | 0.5 | Parts per million | 6 | North Birmingham | 24 | 100 | 42101 | Carbon monoxide | 093 | INSTRUMENTAL - GAS FILTER CORRELATION CO ANALYZER | 13820 | Birmingham-Hoover, AL | 33.553056 | -86.815 | POINT | 177 | NEIGHBORHOOD | 500 M TO 4KM | SLAMS | Jefferson County, AL Department Of Health | OTHER |  | NCORE | 17.5
2022-01-18 | 010730023 | 2 | 0.6 | Parts per million | 7 | North Birmingham | 17 | 71 | 42101 | Carbon monoxide | 093 | INSTRUMENTAL - GAS FILTER CORRELATION CO ANALYZER | 13820 | Birmingham-Hoover, AL | 33.553056 | -86.815 | POINT | 177 | NEIGHBORHOOD | 500 M TO 4KM | SLAMS | Jefferson County, AL Department Of Health | OTHER |  | NCORE | 17.5
2022-01-19 | 010730023 | 2 | 0.3 | Parts per million | 3 | North Birmingham | 9 | 38 | 42101 | Carbon monoxide | 093 | INSTRUMENTAL - GAS FILTER CORRELATION CO ANALYZER | 13820 | Birmingham-Hoover, AL | 33.553056 | -86.815 | POINT | 177 | NEIGHBORHOOD | 500 M TO 4KM | SLAMS | Jefferson County, AL Department Of Health | OTHER |  | NCORE | 17.5
2022-01-20 | 010730023 | 2 | 0.2 | Parts per million | 2 | North Birmingham | 18 | 75 | 42101 | Carbon monoxide | 093 | INSTRUMENTAL - GAS FILTER CORRELATION CO ANALYZER | 13820 | Birmingham-Hoover, AL | 33.553056 | -86.815 | POINT | 177 | NEIGHBORHOOD | 500 M TO 4KM | SLAMS | Jefferson County, AL Department Of Health | OTHER |  | NCORE | 17.5
2022-01-21 | 010730023 | 2 | 0.2 | Parts per million | 2 | North Birmingham | 15 | 63 | 42101 | Carbon monoxide | 093 | INSTRUMENTAL - GAS FILTER CORRELATION CO ANALYZER | 13820 | Birmingham-Hoover, AL | 33.553056 | -86.815 | POINT | 177 | NEIGHBORHOOD | 500 M TO 4KM | SLAMS | Jefferson County, AL Department Of Health | OTHER |  | NCORE | 17.5
2022-01-22 | 010730023 | 2 | 0.4 | Parts per million | 5 | North Birmingham | 24 | 100 | 42101 | Carbon monoxide | 093 | INSTRUMENTAL - GAS FILTER CORRELATION CO ANALYZER | 13820 | Birmingham-Hoover, AL | 33.553056 | -86.815 | POINT | 177 | NEIGHBORHOOD | 500 M TO 4KM | SLAMS | Jefferson County, AL Department Of Health | OTHER |  | NCORE | 17.5
2022-01-23 | 010730023 | 2 | 0.5 | Parts per million | 6 | North Birmingham | 24 | 100 | 42101 | Carbon monoxide | 093 | INSTRUMENTAL - GAS FILTER CORRELATION CO ANALYZER | 13820 | Birmingham-Hoover, AL | 33.553056 | -86.815 | POINT | 177 | NEIGHBORHOOD | 500 M TO 4KM | SLAMS | Jefferson County, AL Department Of Health | OTHER |  | NCORE | 17.5
2022-01-24 | 010730023 | 2 | 0.6 | Parts per million | 7 | North Birmingham | 24 | 100 | 42101 | Carbon monoxide | 093 | INSTRUMENTAL - GAS FILTER CORRELATION CO ANALYZER | 13820 | Birmingham-Hoover, AL | 33.553056 | -86.815 | POINT | 177 | NEIGHBORHOOD | 500 M TO 4KM | SLAMS | Jefferson County, AL Department Of Health | OTHER |  | NCORE | 17.5
2022-01-25 | 010730023 | 2 | 0.3 | Parts per million | 3 | North Birmingham | 18 | 75 | 42101 | Carbon monoxide | 093 | INSTRUMENTAL - GAS FILTER CORRELATION CO ANALYZER | 13820 | Birmingham-Hoover, AL | 33.553056 | -86.815 | POINT | 177 | NEIGHBORHOOD | 500 M TO 4KM | SLAMS | Jefferson County, AL Department Of Health | OTHER |  | NCORE | 17.5
2022-01-26 | 010730023 | 2 | 0.3 | Parts per million | 3 | North Birmingham | 12 | 50 | 42101 | Carbon monoxide | 093 | INSTRUMENTAL - GAS FILTER CORRELATION CO ANALYZER | 13820 | Birmingham-Hoover, AL | 33.553056 | -86.815 | POINT | 177 | NEIGHBORHOOD | 500 M TO 4KM | SLAMS | Jefferson County, AL Department Of Health | OTHER |  | NCORE | 17.5
2022-01-27 | 010730023 | 2 | 0.6 | Parts per million | 7 | North Birmingham | 24 | 100 | 42101 | Carbon monoxide | 093 | INSTRUMENTAL - GAS FILTER CORRELATION CO ANALYZER | 13820 | Birmingham-Hoover, AL | 33.553056 | -86.815 | POINT | 177 | NEIGHBORHOOD | 500 M TO 4KM | SLAMS | Jefferson County, AL Department Of Health | OTHER |  | NCORE | 17.5
2022-01-28 | 010730023 | 2 | 0.6 | Parts per million | 7 | North Birmingham | 24 | 100 | 42101 | Carbon monoxide | 093 | INSTRUMENTAL - GAS FILTER CORRELATION CO ANALYZER | 13820 | Birmingham-Hoover, AL | 33.553056 | -86.815 | POINT | 177 | NEIGHBORHOOD | 500 M TO 4KM | SLAMS | Jefferson County, AL Department Of Health | OTHER |  | NCORE | 17.5
2022-01-29 | 010730023 | 2 | 0.4 | Parts per million | 5 | North Birmingham | 24 | 100 | 42101 | Carbon monoxide | 093 | INSTRUMENTAL - GAS FILTER CORRELATION CO ANALYZER | 13820 | Birmingham-Hoover, AL | 33.553056 | -86.815 | POINT | 177 | NEIGHBORHOOD | 500 M TO 4KM | SLAMS | Jefferson County, AL Department Of Health | OTHER |  | NCORE | 17.5
2022-01-30 | 010730023 | 2 | 0.6 | Parts per million | 7 | North Birmingham | 24 | 100 | 42101 | Carbon monoxide | 093 | INSTRUMENTAL - GAS FILTER CORRELATION CO ANALYZER | 13820 | Birmingham-Hoover, AL | 33.553056 | -86.815 | POINT | 177 | NEIGHBORHOOD | 500 M TO 4KM | SLAMS | Jefferson County, AL Department Of Health | OTHER |  | NCORE | 17.5
2022-01-31 | 010730023 | 2 | 0.8 | Parts per million | 9 | North Birmingham | 24 | 100 | 42101 | Carbon monoxide | 093 | INSTRUMENTAL - GAS FILTER CORRELATION CO ANALYZER | 13820 | Birmingham-Hoover, AL | 33.553056 | -86.815 | POINT | 177 | NEIGHBORHOOD | 500 M TO 4KM | SLAMS | Jefferson County, AL Department Of Health | OTHER |  | NCORE | 17.5
2022-02-01 | 010730023 | 2 | 0.5 | Parts per million | 6 | North Birmingham | 24 | 100 | 42101 | Carbon monoxide | 093 | INSTRUMENTAL - GAS FILTER CORRELATION CO ANALYZER | 13820 | Birmingham-Hoover, AL | 33.553056 | -86.815 | POINT | 177 | NEIGHBORHOOD | 500 M TO 4KM | SLAMS | Jefferson County, AL Department Of Health | OTHER |  | NCORE | 17.5
2022-02-02 | 010730023 | 2 | 0.2 | Parts per million | 2 | North Birmingham | 17 | 71 | 42101 | Carbon monoxide | 093 | INSTRUMENTAL - GAS FILTER CORRELATION CO ANALYZER | 13820 | Birmingham-Hoover, AL | 33.553056 | -86.815 | POINT | 177 | NEIGHBORHOOD | 500 M TO 4KM | SLAMS | Jefferson County, AL Department Of Health | OTHER |  | NCORE | 17.5
2022-02-03 | 010730023 | 2 | 0.2 | Parts per million | 2 | North Birmingham | 18 | 75 | 42101 | Carbon monoxide | 093 | INSTRUMENTAL - GAS FILTER CORRELATION CO ANALYZER | 13820 | Birmingham-Hoover, AL | 33.553056 | -86.815 | POINT | 177 | NEIGHBORHOOD | 500 M TO 4KM | SLAMS | Jefferson County, AL Department Of Health | OTHER |  | NCORE | 17.5
2022-02-04 | 010730023 | 2 | 0.2 | Parts per million | 2 | North Birmingham | 24 | 100 | 42101 | Carbon monoxide | 093 | INSTRUMENTAL - GAS FILTER CORRELATION CO ANALYZER | 13820 | Birmingham-Hoover, AL | 33.553056 | -86.815 | POINT | 177 | NEIGHBORHOOD | 500 M TO 4KM | SLAMS | Jefferson County, AL Department Of Health | OTHER |  | NCORE | 17.5
2022-02-05 | 010730023 | 2 | 0.3 | Parts per million | 3 | North Birmingham | 24 | 100 | 42101 | Carbon monoxide | 093 | INSTRUMENTAL - GAS FILTER CORRELATION CO ANALYZER | 13820 | Birmingham-Hoover, AL | 33.553056 | -86.815 | POINT | 177 | NEIGHBORHOOD | 500 M TO 4KM | SLAMS | Jefferson County, AL Department Of Health | OTHER |  | NCORE | 17.5
2022-02-06 | 010730023 | 2 | 0.4 | Parts per million | 5 | North Birmingham | 24 | 100 | 42101 | Carbon monoxide | 093 | INSTRUMENTAL - GAS FILTER CORRELATION CO ANALYZER | 13820 | Birmingham-Hoover, AL | 33.553056 | -86.815 | POINT | 177 | NEIGHBORHOOD | 500 M TO 4KM | SLAMS | Jefferson County, AL Department Of Health | OTHER |  | NCORE | 17.5
2022-02-07 | 010730023 | 2 | 0.5 | Parts per million | 6 | North Birmingham | 24 | 100 | 42101 | Carbon monoxide | 093 | INSTRUMENTAL - GAS FILTER CORRELATION CO ANALYZER | 13820 | Birmingham-Hoover, AL | 33.553056 | -86.815 | POINT | 177 | NEIGHBORHOOD | 500 M TO 4KM | SLAMS | Jefferson County, AL Department Of Health | OTHER |  | NCORE | 17.5
2022-02-08 | 010730023 | 2 | 0.6 | Parts per million | 7 | North Birmingham | 18 | 75 | 42101 | Carbon monoxide | 093 | INSTRUMENTAL - GAS FILTER CORRELATION CO ANALYZER | 13820 | Birmingham-Hoover, AL | 33.553056 | -86.815 | POINT | 177 | NEIGHBORHOOD | 500 M TO 4KM | SLAMS | Jefferson County, AL Department Of Health | OTHER |  | NCORE | 17.5
2022-02-09 | 010730023 | 2 | 0.7 | Parts per million | 8 | North Birmingham | 18 | 75 | 42101 | Carbon monoxide | 093 | INSTRUMENTAL - GAS FILTER CORRELATION CO ANALYZER | 13820 | Birmingham-Hoover, AL | 33.553056 | -86.815 | POINT | 177 | NEIGHBORHOOD | 500 M TO 4KM | SLAMS | Jefferson County, AL Department Of Health | OTHER |  | NCORE | 17.5
2022-02-10 | 010730023 | 2 | 0.7 | Parts per million | 8 | North Birmingham | 24 | 100 | 42101 | Carbon monoxide | 093 | INSTRUMENTAL - GAS FILTER CORRELATION CO ANALYZER | 13820 | Birmingham-Hoover, AL | 33.553056 | -86.815 | POINT | 177 | NEIGHBORHOOD | 500 M TO 4KM | SLAMS | Jefferson County, AL Department Of Health | OTHER |  | NCORE | 17.5
2022-02-11 | 010730023 | 2 | 0.7 | Parts per million | 8 | North Birmingham | 24 | 100 | 42101 | Carbon monoxide | 093 | INSTRUMENTAL - GAS FILTER CORRELATION CO ANALYZER | 13820 | Birmingham-Hoover, AL | 33.553056 | -86.815 | POINT | 177 | NEIGHBORHOOD | 500 M TO 4KM | SLAMS | Jefferson County, AL Department Of Health | OTHER |  | NCORE | 17.5
2022-02-12 | 010730023 | 2 | 0.6 | Parts per million | 7 | North Birmingham | 24 | 100 | 42101 | Carbon monoxide | 093 | INSTRUMENTAL - GAS FILTER CORRELATION CO ANALYZER | 13820 | Birmingham-Hoover, AL | 33.553056 | -86.815 | POINT | 177 | NEIGHBORHOOD | 500 M TO 4KM | SLAMS | Jefferson County, AL Department Of Health | OTHER |  | NCORE | 17.5
2022-02-13 | 010730023 | 2 | 0.2 | Parts per million | 2 | North Birmingham | 24 | 100 | 42101 | Carbon monoxide | 093 | INSTRUMENTAL - GAS FILTER CORRELATION CO ANALYZER | 13820 | Birmingham-Hoover, AL | 33.553056 | -86.815 | POINT | 177 | NEIGHBORHOOD | 500 M TO 4KM | SLAMS | Jefferson County, AL Department Of Health | OTHER |  | NCORE | 17.5
2022-02-14 | 010730023 | 2 | 2.6 | Parts per million | 30 | North Birmingham | 12 | 50 | 42101 | Carbon monoxide | 093 | INSTRUMENTAL - GAS FILTER CORRELATION CO ANALYZER | 13820 | Birmingham-Hoover, AL | 33.553056 | -86.815 | POINT | 177 | NEIGHBORHOOD | 500 M TO 4KM | SLAMS | Jefferson County, AL Department Of Health | OTHER |  | NCORE | 17.5
2022-02-15 | 010730023 | 2 | 2.6 | Parts per million | 30 | North Birmingham | 18 | 75 | 42101 | Carbon monoxide | 093 | INSTRUMENTAL - GAS FILTER CORRELATION CO ANALYZER | 13820 | Birmingham-Hoover, AL | 33.553056 | -86.815 | POINT | 177 | NEIGHBORHOOD | 500 M TO 4KM | SLAMS | Jefferson County, AL Department Of Health | OTHER |  | NCORE | 17.5
2022-02-16 | 010730023 | 2 | 0.2 | Parts per million | 2 | North Birmingham | 18 | 75 | 42101 | Carbon monoxide | 093 | INSTRUMENTAL - GAS FILTER CORRELATION CO ANALYZER | 13820 | Birmingham-Hoover, AL | 33.553056 | -86.815 | POINT | 177 | NEIGHBORHOOD | 500 M TO 4KM | SLAMS | Jefferson County, AL Department Of Health | OTHER |  | NCORE | 17.5
2022-02-17 | 010730023 | 2 | 0.2 | Parts per million | 2 | North Birmingham | 24 | 100 | 42101 | Carbon monoxide | 093 | INSTRUMENTAL - GAS FILTER CORRELATION CO ANALYZER | 13820 | Birmingham-Hoover, AL | 33.553056 | -86.815 | POINT | 177 | NEIGHBORHOOD | 500 M TO 4KM | SLAMS | Jefferson County, AL Department Of Health | OTHER |  | NCORE | 17.5
2022-02-18 | 010730023 | 2 | 0.3 | Parts per million | 3 | North Birmingham | 24 | 100 | 42101 | Carbon monoxide | 093 | INSTRUMENTAL - GAS FILTER CORRELATION CO ANALYZER | 13820 | Birmingham-Hoover, AL | 33.553056 | -86.815 | POINT | 177 | NEIGHBORHOOD | 500 M TO 4KM | SLAMS | Jefferson County, AL Department Of Health | OTHER |  | NCORE | 17.5
2022-02-19 | 010730023 | 2 | 0.4 | Parts per million | 5 | North Birmingham | 24 | 100 | 42101 | Carbon monoxide | 093 | INSTRUMENTAL - GAS FILTER CORRELATION CO ANALYZER | 13820 | Birmingham-Hoover, AL | 33.553056 | -86.815 | POINT | 177 | NEIGHBORHOOD | 500 M TO 4KM | SLAMS | Jefferson County, AL Department Of Health | OTHER |  | NCORE | 17.5
2022-02-20 | 010730023 | 2 | 0.5 | Parts per million | 6 | North Birmingham | 24 | 100 | 42101 | Carbon monoxide | 093 | INSTRUMENTAL - GAS FILTER CORRELATION CO ANALYZER | 13820 | Birmingham-Hoover, AL | 33.553056 | -86.815 | POINT | 177 | NEIGHBORHOOD | 500 M TO 4KM | SLAMS | Jefferson County, AL Department Of Health | OTHER |  | NCORE | 17.5
2022-02-21 | 010730023 | 2 | 0.3 | Parts per million | 3 | North Birmingham | 24 | 100 | 42101 | Carbon monoxide | 093 | INSTRUMENTAL - GAS FILTER CORRELATION CO ANALYZER | 13820 | Birmingham-Hoover, AL | 33.553056 | -86.815 | POINT | 177 | NEIGHBORHOOD | 500 M TO 4KM | SLAMS | Jefferson County, AL Department Of Health | OTHER |  | NCORE | 17.5
2022-02-22 | 010730023 | 2 | 0.2 | Parts per million | 2 | North Birmingham | 18 | 75 | 42101 | Carbon monoxide | 093 | INSTRUMENTAL - GAS FILTER CORRELATION CO ANALYZER | 13820 | Birmingham-Hoover, AL | 33.553056 | -86.815 | POINT | 177 | NEIGHBORHOOD | 500 M TO 4KM | SLAMS | Jefferson County, AL Department Of Health | OTHER |  | NCORE | 17.5
2022-02-23 | 010730023 | 2 | 0.2 | Parts per million | 2 | North Birmingham | 17 | 71 | 42101 | Carbon monoxide | 093 | INSTRUMENTAL - GAS FILTER CORRELATION CO ANALYZER | 13820 | Birmingham-Hoover, AL | 33.553056 | -86.815 | POINT | 177 | NEIGHBORHOOD | 500 M TO 4KM | SLAMS | Jefferson County, AL Department Of Health | OTHER |  | NCORE | 17.5
2022-02-24 | 010730023 | 2 | 0.3 | Parts per million | 3 | North Birmingham | 24 | 100 | 42101 | Carbon monoxide | 093 | INSTRUMENTAL - GAS FILTER CORRELATION CO ANALYZER | 13820 | Birmingham-Hoover, AL | 33.553056 | -86.815 | POINT | 177 | NEIGHBORHOOD | 500 M TO 4KM | SLAMS | Jefferson County, AL Department Of Health | OTHER |  | NCORE | 17.5
2022-02-25 | 010730023 | 2 | 0.2 | Parts per million | 2 | North Birmingham | 24 | 100 | 42101 | Carbon monoxide | 093 | INSTRUMENTAL - GAS FILTER CORRELATION CO ANALYZER | 13820 | Birmingham-Hoover, AL | 33.553056 | -86.815 | POINT | 177 | NEIGHBORHOOD | 500 M TO 4KM | SLAMS | Jefferson County, AL Department Of Health | OTHER |  | NCORE | 17.5
2022-02-26 | 010730023 | 2 | 0.2 | Parts per million | 2 | North Birmingham | 24 | 100 | 42101 | Carbon monoxide | 093 | INSTRUMENTAL - GAS FILTER CORRELATION CO ANALYZER | 13820 | Birmingham-Hoover, AL | 33.553056 | -86.815 | POINT | 177 | NEIGHBORHOOD | 500 M TO 4KM | SLAMS | Jefferson County, AL Department Of Health | OTHER |  | NCORE | 17.5
2022-02-27 | 010730023 | 2 | 0.2 | Parts per million | 2 | North Birmingham | 24 | 100 | 42101 | Carbon monoxide | 093 | INSTRUMENTAL - GAS FILTER CORRELATION CO ANALYZER | 13820 | Birmingham-Hoover, AL | 33.553056 | -86.815 | POINT | 177 | NEIGHBORHOOD | 500 M TO 4KM | SLAMS | Jefferson County, AL Department Of Health | OTHER |  | NCORE | 17.5
2022-02-28 | 010730023 | 2 | 0.2 | Parts per million | 2 | North Birmingham | 13 | 54 | 42101 | Carbon monoxide | 093 | INSTRUMENTAL - GAS FILTER CORRELATION CO ANALYZER | 13820 | Birmingham-Hoover, AL | 33.553056 | -86.815 | POINT | 177 | NEIGHBORHOOD | 500 M TO 4KM | SLAMS | Jefferson County, AL Department Of Health | OTHER |  | NCORE | 17.5
2022-03-01 | 010730023 | 2 | 0.6 | Parts per million | 7 | North Birmingham | 22 | 92 | 42101 | Carbon monoxide | 093 | INSTRUMENTAL - GAS FILTER CORRELATION CO ANALYZER | 13820 | Birmingham-Hoover, AL | 33.553056 | -86.815 | POINT | 177 | NEIGHBORHOOD | 500 M TO 4KM | SLAMS | Jefferson County, AL Department Of Health | OTHER |  | NCORE | 17.5
2022-03-02 | 010730023 | 2 | 0.7 | Parts per million | 8 | North Birmingham | 15 | 63 | 42101 | Carbon monoxide | 093 | INSTRUMENTAL - GAS FILTER CORRELATION CO ANALYZER | 13820 | Birmingham-Hoover, AL | 33.553056 | -86.815 | POINT | 177 | NEIGHBORHOOD | 500 M TO 4KM | SLAMS | Jefferson County, AL Department Of Health | OTHER |  | NCORE | 17.5
2022-03-03 | 010730023 | 2 | 0.7 | Parts per million | 8 | North Birmingham | 18 | 75 | 42101 | Carbon monoxide | 093 | INSTRUMENTAL - GAS FILTER CORRELATION CO ANALYZER | 13820 | Birmingham-Hoover, AL | 33.553056 | -86.815 | POINT | 177 | NEIGHBORHOOD | 500 M TO 4KM | SLAMS | Jefferson County, AL Department Of Health | OTHER |  | NCORE | 17.5
2022-03-04 | 010730023 | 2 | 0.7 | Parts per million | 8 | North Birmingham | 17 | 71 | 42101 | Carbon monoxide | 093 | INSTRUMENTAL - GAS FILTER CORRELATION CO ANALYZER | 13820 | Birmingham-Hoover, AL | 33.553056 | -86.815 | POINT | 177 | NEIGHBORHOOD | 500 M TO 4KM | SLAMS | Jefferson County, AL Department Of Health | OTHER |  | NCORE | 17.5
2022-03-05 | 010730023 | 2 | 0.3 | Parts per million | 3 | North Birmingham | 24 | 100 | 42101 | Carbon monoxide | 093 | INSTRUMENTAL - GAS FILTER CORRELATION CO ANALYZER | 13820 | Birmingham-Hoover, AL | 33.553056 | -86.815 | POINT | 177 | NEIGHBORHOOD | 500 M TO 4KM | SLAMS | Jefferson County, AL Department Of Health | OTHER |  | NCORE | 17.5
2022-03-06 | 010730023 | 2 | 0.2 | Parts per million | 2 | North Birmingham | 24 | 100 | 42101 | Carbon monoxide | 093 | INSTRUMENTAL - GAS FILTER CORRELATION CO ANALYZER | 13820 | Birmingham-Hoover, AL | 33.553056 | -86.815 | POINT | 177 | NEIGHBORHOOD | 500 M TO 4KM | SLAMS | Jefferson County, AL Department Of Health | OTHER |  | NCORE | 17.5
2022-03-07 | 010730023 | 2 | 0.2 | Parts per million | 2 | North Birmingham | 24 | 100 | 42101 | Carbon monoxide | 093 | INSTRUMENTAL - GAS FILTER CORRELATION CO ANALYZER | 13820 | Birmingham-Hoover, AL | 33.553056 | -86.815 | POINT | 177 | NEIGHBORHOOD | 500 M TO 4KM | SLAMS | Jefferson County, AL Department Of Health | OTHER |  | NCORE | 17.5
2022-03-08 | 010730023 | 2 | 0.2 | Parts per million | 2 | North Birmingham | 24 | 100 | 42101 | Carbon monoxide | 093 | INSTRUMENTAL - GAS FILTER CORRELATION CO ANALYZER | 13820 | Birmingham-Hoover, AL | 33.553056 | -86.815 | POINT | 177 | NEIGHBORHOOD | 500 M TO 4KM | SLAMS | Jefferson County, AL Department Of Health | OTHER |  | NCORE | 17.5
2022-03-09 | 010730023 | 2 | 0.2 | Parts per million | 2 | North Birmingham | 24 | 100 | 42101 | Carbon monoxide | 093 | INSTRUMENTAL - GAS FILTER CORRELATION CO ANALYZER | 13820 | Birmingham-Hoover, AL | 33.553056 | -86.815 | POINT | 177 | NEIGHBORHOOD | 500 M TO 4KM | SLAMS | Jefferson County, AL Department Of Health | OTHER |  | NCORE | 17.5
2022-03-10 | 010730023 | 2 | 0.3 | Parts per million | 3 | North Birmingham | 12 | 50 | 42101 | Carbon monoxide | 093 | INSTRUMENTAL - GAS FILTER CORRELATION CO ANALYZER | 13820 | Birmingham-Hoover, AL | 33.553056 | -86.815 | POINT | 177 | NEIGHBORHOOD | 500 M TO 4KM | SLAMS | Jefferson County, AL Department Of Health | OTHER |  | NCORE | 17.5
2022-03-11 | 010730023 | 2 | 0.4 | Parts per million | 5 | North Birmingham | 24 | 100 | 42101 | Carbon monoxide | 093 | INSTRUMENTAL - GAS FILTER CORRELATION CO ANALYZER | 13820 | Birmingham-Hoover, AL | 33.553056 | -86.815 | POINT | 177 | NEIGHBORHOOD | 500 M TO 4KM | SLAMS | Jefferson County, AL Department Of Health | OTHER |  | NCORE | 17.5
2022-03-12 | 010730023 | 2 | 0.2 | Parts per million | 2 | North Birmingham | 24 | 100 | 42101 | Carbon monoxide | 093 | INSTRUMENTAL - GAS FILTER CORRELATION CO ANALYZER | 13820 | Birmingham-Hoover, AL | 33.553056 | -86.815 | POINT | 177 | NEIGHBORHOOD | 500 M TO 4KM | SLAMS | Jefferson County, AL Department Of Health | OTHER |  | NCORE | 17.5
2022-03-13 | 010730023 | 2 | 0.3 | Parts per million | 3 | North Birmingham | 24 | 100 | 42101 | Carbon monoxide | 093 | INSTRUMENTAL - GAS FILTER CORRELATION CO ANALYZER | 13820 | Birmingham-Hoover, AL | 33.553056 | -86.815 | POINT | 177 | NEIGHBORHOOD | 500 M TO 4KM | SLAMS | Jefferson County, AL Department Of Health | OTHER |  | NCORE | 17.5
2022-03-14 | 010730023 | 2 | 0.3 | Parts per million | 3 | North Birmingham | 24 | 100 | 42101 | Carbon monoxide | 093 | INSTRUMENTAL - GAS FILTER CORRELATION CO ANALYZER | 13820 | Birmingham-Hoover, AL | 33.553056 | -86.815 | POINT | 177 | NEIGHBORHOOD | 500 M TO 4KM | SLAMS | Jefferson County, AL Department Of Health | OTHER |  | NCORE | 17.5
2022-03-15 | 010730023 | 2 | 0.2 | Parts per million | 2 | North Birmingham | 24 | 100 | 42101 | Carbon monoxide | 093 | INSTRUMENTAL - GAS FILTER CORRELATION CO ANALYZER | 13820 | Birmingham-Hoover, AL | 33.553056 | -86.815 | POINT | 177 | NEIGHBORHOOD | 500 M TO 4KM | SLAMS | Jefferson County, AL Department Of Health | OTHER |  | NCORE | 17.5
2022-03-16 | 010730023 | 2 | 0.5 | Parts per million | 6 | North Birmingham | 18 | 75 | 42101 | Carbon monoxide | 093 | INSTRUMENTAL - GAS FILTER CORRELATION CO ANALYZER | 13820 | Birmingham-Hoover, AL | 33.553056 | -86.815 | POINT | 177 | NEIGHBORHOOD | 500 M TO 4KM | SLAMS | Jefferson County, AL Department Of Health | OTHER |  | NCORE | 17.5
2022-03-17 | 010730023 | 2 | 0.7 | Parts per million | 8 | North Birmingham | 24 | 100 | 42101 | Carbon monoxide | 093 | INSTRUMENTAL - GAS FILTER CORRELATION CO ANALYZER | 13820 | Birmingham-Hoover, AL | 33.553056 | -86.815 | POINT | 177 | NEIGHBORHOOD | 500 M TO 4KM | SLAMS | Jefferson County, AL Department Of Health | OTHER |  | NCORE | 17.5
2022-03-18 | 010730023 | 2 | 0.2 | Parts per million | 2 | North Birmingham | 17 | 71 | 42101 | Carbon monoxide | 093 | INSTRUMENTAL - GAS FILTER CORRELATION CO ANALYZER | 13820 | Birmingham-Hoover, AL | 33.553056 | -86.815 | POINT | 177 | NEIGHBORHOOD | 500 M TO 4KM | SLAMS | Jefferson County, AL Department Of Health | OTHER |  | NCORE | 17.5
2022-03-19 | 010730023 | 2 | 0.3 | Parts per million | 3 | North Birmingham | 24 | 100 | 42101 | Carbon monoxide | 093 | INSTRUMENTAL - GAS FILTER CORRELATION CO ANALYZER | 13820 | Birmingham-Hoover, AL | 33.553056 | -86.815 | POINT | 177 | NEIGHBORHOOD | 500 M TO 4KM | SLAMS | Jefferson County, AL Department Of Health | OTHER |  | NCORE | 17.5
2022-03-20 | 010730023 | 2 | 0.4 | Parts per million | 5 | North Birmingham | 24 | 100 | 42101 | Carbon monoxide | 093 | INSTRUMENTAL - GAS FILTER CORRELATION CO ANALYZER | 13820 | Birmingham-Hoover, AL | 33.553056 | -86.815 | POINT | 177 | NEIGHBORHOOD | 500 M TO 4KM | SLAMS | Jefferson County, AL Department Of Health | OTHER |  | NCORE | 17.5
2022-03-21 | 010730023 | 2 | 0.4 | Parts per million | 5 | North Birmingham | 24 | 100 | 42101 | Carbon monoxide | 093 | INSTRUMENTAL - GAS FILTER CORRELATION CO ANALYZER | 13820 | Birmingham-Hoover, AL | 33.553056 | -86.815 | POINT | 177 | NEIGHBORHOOD | 500 M TO 4KM | SLAMS | Jefferson County, AL Department Of Health | OTHER |  | NCORE | 17.5
2022-03-22 | 010730023 | 2 | 0.2 | Parts per million | 2 | North Birmingham | 23 | 96 | 42101 | Carbon monoxide | 093 | INSTRUMENTAL - GAS FILTER CORRELATION CO ANALYZER | 13820 | Birmingham-Hoover, AL | 33.553056 | -86.815 | POINT | 177 | NEIGHBORHOOD | 500 M TO 4KM | SLAMS | Jefferson County, AL Department Of Health | OTHER |  | NCORE | 17.5
2022-03-23 | 010730023 | 2 | 0.1 | Parts per million | 1 | North Birmingham | 12 | 50 | 42101 | Carbon monoxide | 093 | INSTRUMENTAL - GAS FILTER CORRELATION CO ANALYZER | 13820 | Birmingham-Hoover, AL | 33.553056 | -86.815 | POINT | 177 | NEIGHBORHOOD | 500 M TO 4KM | SLAMS | Jefferson County, AL Department Of Health | OTHER |  | NCORE | 17.5
2022-03-24 | 010730023 | 2 | 0.3 | Parts per million | 3 | North Birmingham | 24 | 100 | 42101 | Carbon monoxide | 093 | INSTRUMENTAL - GAS FILTER CORRELATION CO ANALYZER | 13820 | Birmingham-Hoover, AL | 33.553056 | -86.815 | POINT | 177 | NEIGHBORHOOD | 500 M TO 4KM | SLAMS | Jefferson County, AL Department Of Health | OTHER |  | NCORE | 17.5
2022-03-25 | 010730023 | 2 | 0.3 | Parts per million | 3 | North Birmingham | 24 | 100 | 42101 | Carbon monoxide | 093 | INSTRUMENTAL - GAS FILTER CORRELATION CO ANALYZER | 13820 | Birmingham-Hoover, AL | 33.553056 | -86.815 | POINT | 177 | NEIGHBORHOOD | 500 M TO 4KM | SLAMS | Jefferson County, AL Department Of Health | OTHER |  | NCORE | 17.5
2022-03-26 | 010730023 | 2 | 0.2 | Parts per million | 2 | North Birmingham | 24 | 100 | 42101 | Carbon monoxide | 093 | INSTRUMENTAL - GAS FILTER CORRELATION CO ANALYZER | 13820 | Birmingham-Hoover, AL | 33.553056 | -86.815 | POINT | 177 | NEIGHBORHOOD | 500 M TO 4KM | SLAMS | Jefferson County, AL Department Of Health | OTHER |  | NCORE | 17.5
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

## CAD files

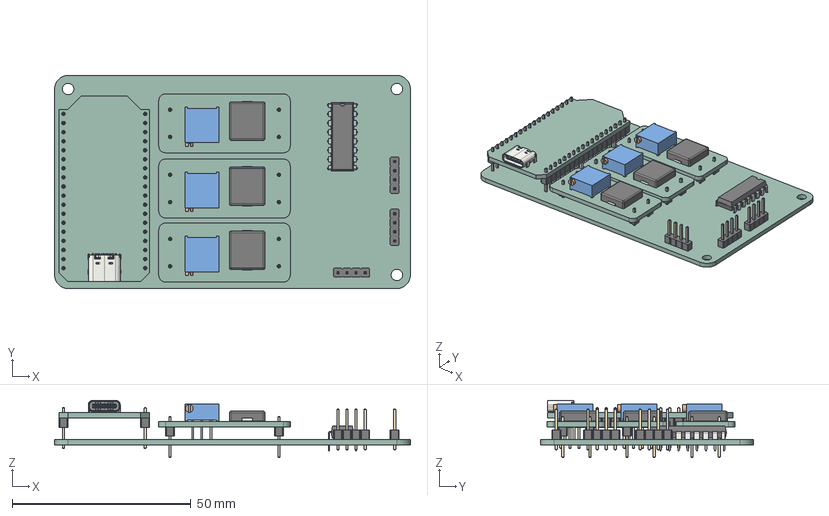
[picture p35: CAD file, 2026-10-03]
Proyecto/MóduloMecánico/Upper_board.step
99.7 x 59.7 x 16.0 mm
PinHeader_1x04_P254mm_Vertical x 3
DIP-16_W7.62mm
Potentiometer_Bourns_3296P_Horizontal x 3
L_APV_APH1030 x 3
PinHeader_1x01_P254mm_Vertical x 12
MT3608_PCB x 3
USB_C_Receptacle_16P_TopMnt_Horizontal_GCT_USB4105-xx-A
PinHeader_1x18_P254mm_Vertical x 2
LoraV4_PCB
Main board_PCB

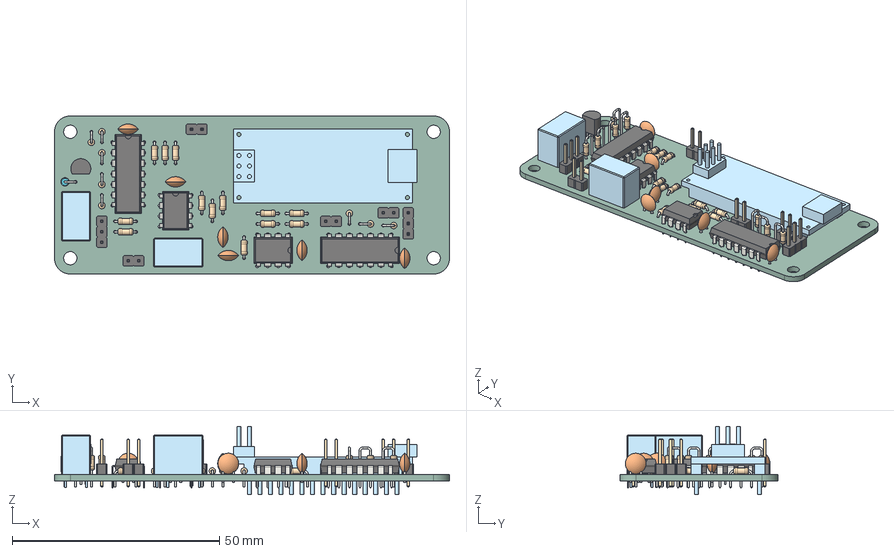
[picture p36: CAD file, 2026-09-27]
Proyecto/MóduloMecánico/Current_sensing_board.step
95.2 x 38.1 x 16.4 mm
R_Axial_DIN0204_L36mm_D16mm_P254mm_Vertical x 8
C_Disc_D50mm_W25mm_P250mm x 6
PinHeader_1x02_P254mm_Vertical x 4
R_Axial_DIN0204_L36mm_D16mm_P508mm_Horizontal x 13
DIP-14_W7.62mm x 2
TO-92_Narrow
D_DO-35_SOD27_P2.54mm_Vertical_AnodeUp
PinHeader_1x03_P254mm_Vertical x 2
DIP-8_W7.62mm x 2
Sensing probe_PCB

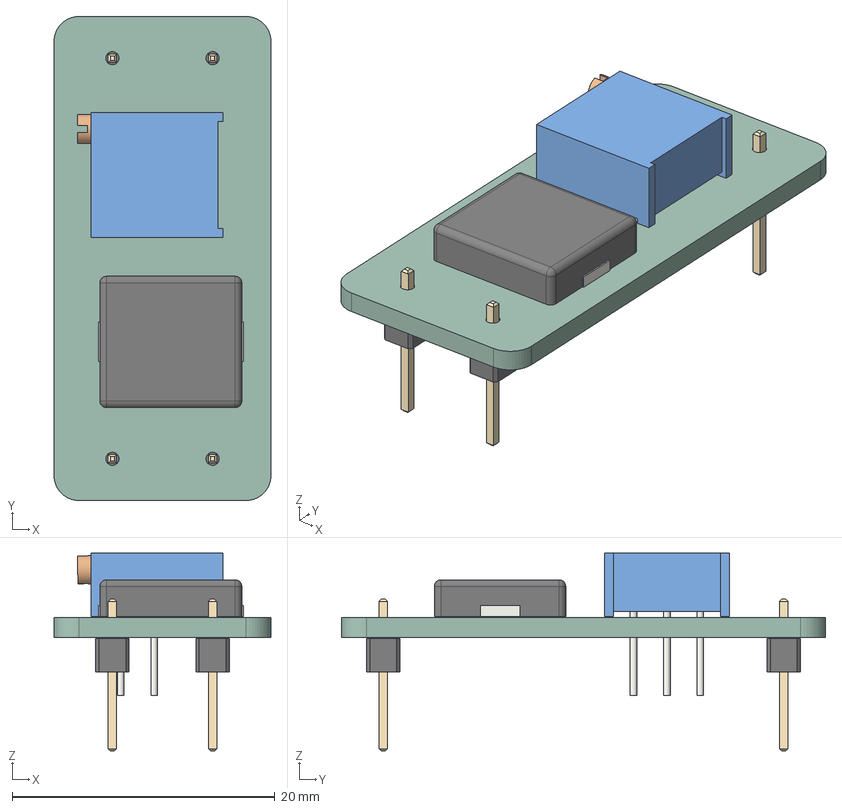
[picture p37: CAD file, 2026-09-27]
Proyecto/MóduloMecánico/MT3608.step
16.5 x 36.8 x 15.1 mm
Potentiometer_Bourns_3296P_Horizontal
L_APV_APH1030
PinHeader_1x01_P254mm_Vertical x 4
MT3608_PCB

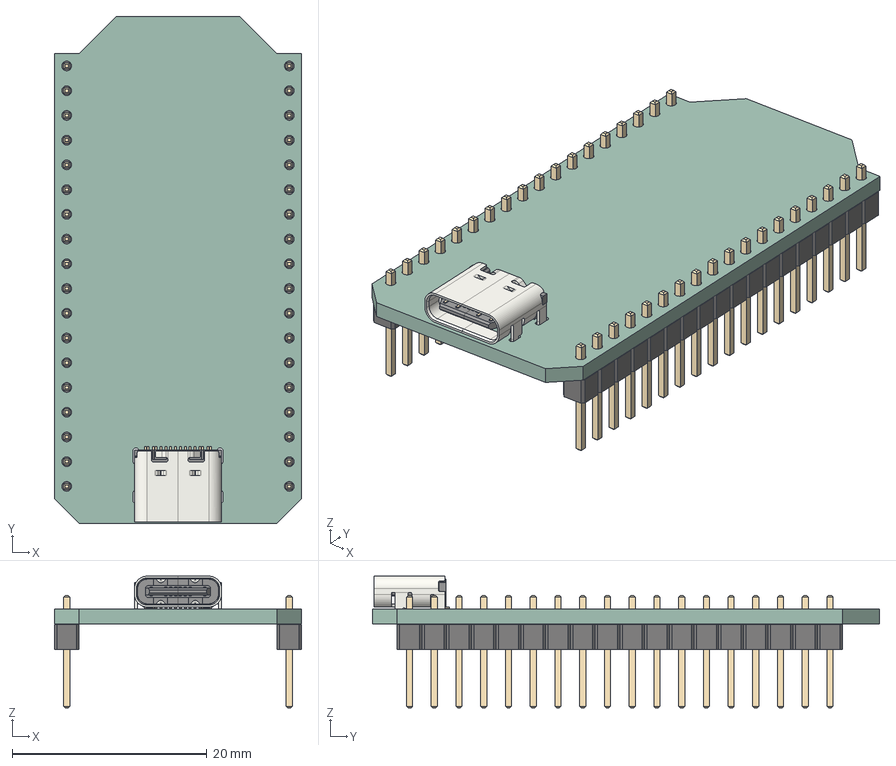
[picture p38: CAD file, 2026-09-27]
Proyecto/MóduloMecánico/LoraV4.step
25.4 x 52.1 x 13.5 mm
USB_C_Receptacle_16P_TopMnt_Horizontal_GCT_USB4105-xx-A
PinHeader_1x18_P254mm_Vertical x 2
LoraV4_PCB

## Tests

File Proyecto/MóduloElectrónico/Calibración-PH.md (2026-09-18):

Unidades: mV

### Amplificación X5
|ph4|ph7|ph10|
|--|--|--|
|86|-6.2|-200|
|86.8| -31.6| -199|
|86.2| -47.2| -206|
|87| -47.6| -208|
|87| -52| -214|

### Amplificación X3
|ph4|ph7|ph10|
|-|-|-|
|117| -60| -222|
|106| -52.6| -214|
|94| -67.3| -218|
|95.7| -68| -230|
|102| -63| -225|

- REF RIN
- OUT NC
- VCC GND
- SIGNAL PULSE

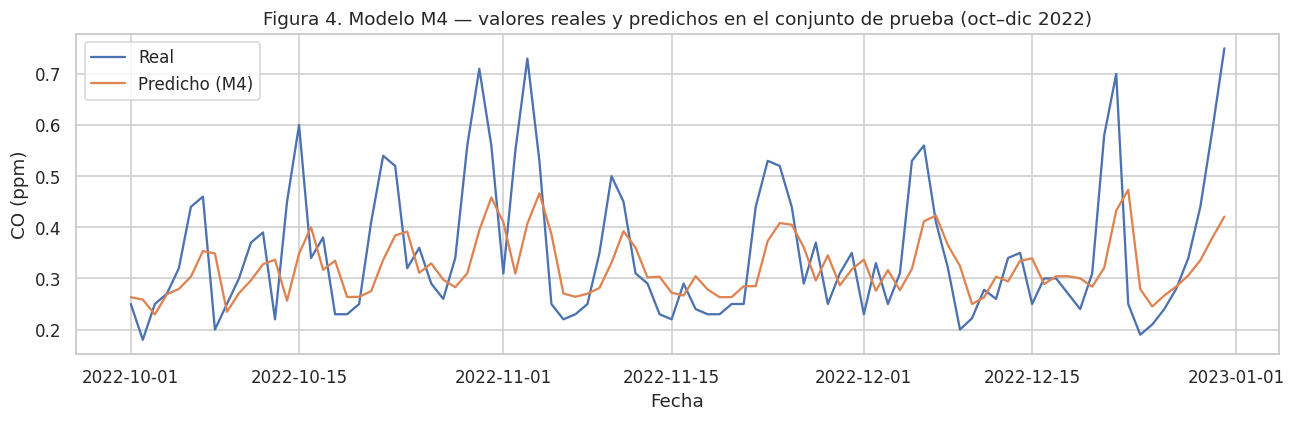
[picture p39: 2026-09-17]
Imagenes/TallerIA/Semana5_Tarea/Willy/fig4_m4_prueba.png

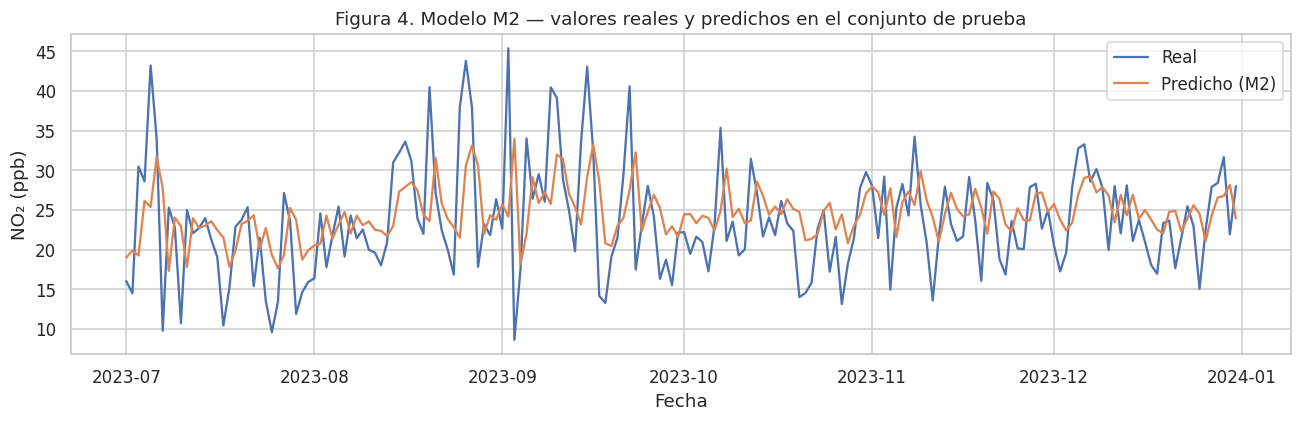
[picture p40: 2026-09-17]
Imagenes/TallerIA/Semana5_Tarea/Ruben/fig4_m2_prueba.png

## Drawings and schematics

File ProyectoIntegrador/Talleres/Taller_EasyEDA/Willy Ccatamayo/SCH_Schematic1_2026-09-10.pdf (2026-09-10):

D12 15 D13 16 3V3 17 B0 18 A0 19 A1 20 A2 21 A3 22 A4 23 A5 24 A6 25 A7 26 VBUS 27 B1 28 GND 29 VIN 30 EH ³¹ EH ³² EH 33 EH 34

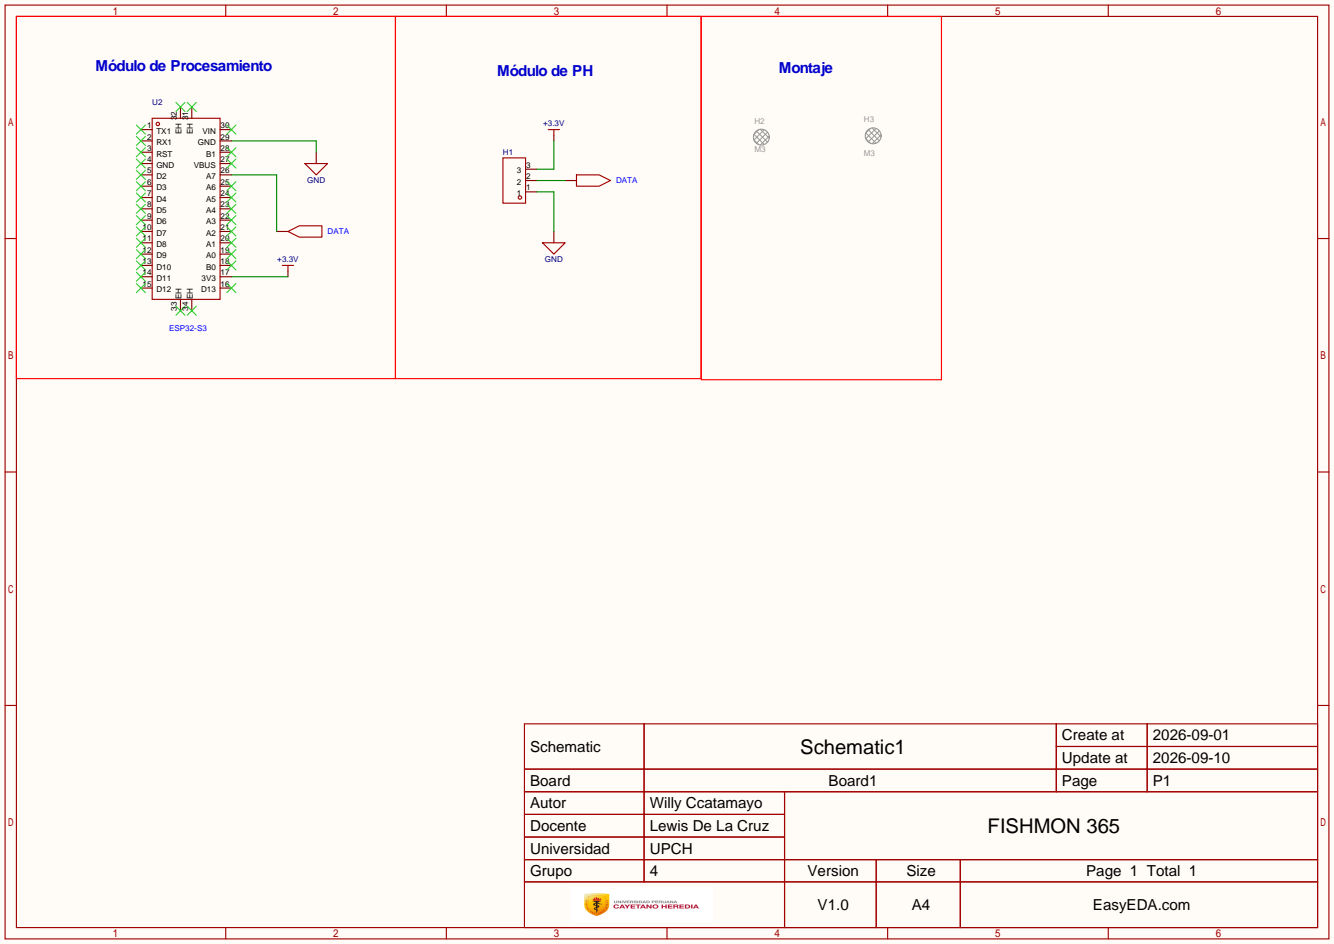
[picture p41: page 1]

Schematic | Schematic1 | Create at | 2026-09-01

Update at | 2026-09-10

Board | Board1 | Page | P1
Autor | Willy Ccatamayo | FISHMON 365
Docente | Lewis De La Cruz
Universidad | UPCH
Grupo | 4 | Version | Size | Page 1 Total 1

V1.0 | A4 | EasyEDA.com

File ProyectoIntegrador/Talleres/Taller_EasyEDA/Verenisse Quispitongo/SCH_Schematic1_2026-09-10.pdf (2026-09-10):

# Modulo de Procesamiento

# Modulo de Sensores

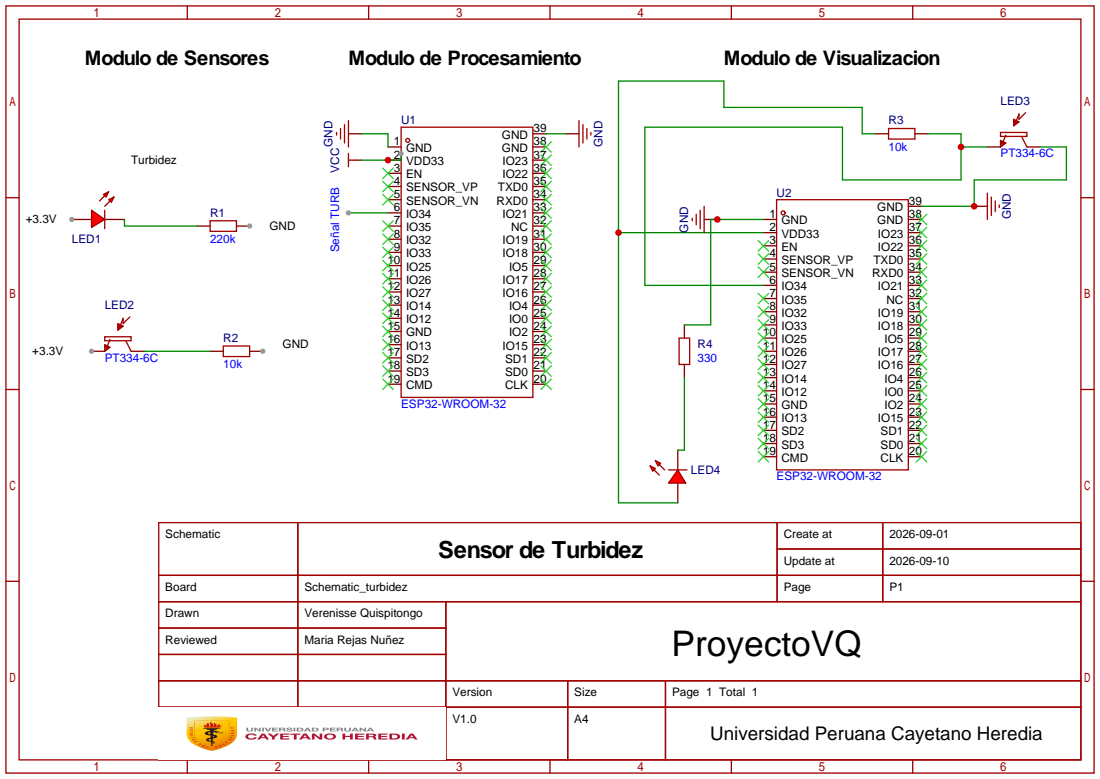
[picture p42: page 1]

Schematic | Sensor de Turbidez | Create at | 2026-09-01

Update at | 2026-09-10

Board | Schematic_turbidez | Page | P1
Drawn | Verenisse Quispitongo | ProyectoVQ
Reviewed | Maria Rejas Nuñez

Version | Size | Page 1 Total 1
V1.0 | A4 | Universidad Peruana Cayetano Heredia

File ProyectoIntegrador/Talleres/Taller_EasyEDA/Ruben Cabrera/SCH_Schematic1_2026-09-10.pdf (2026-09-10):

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

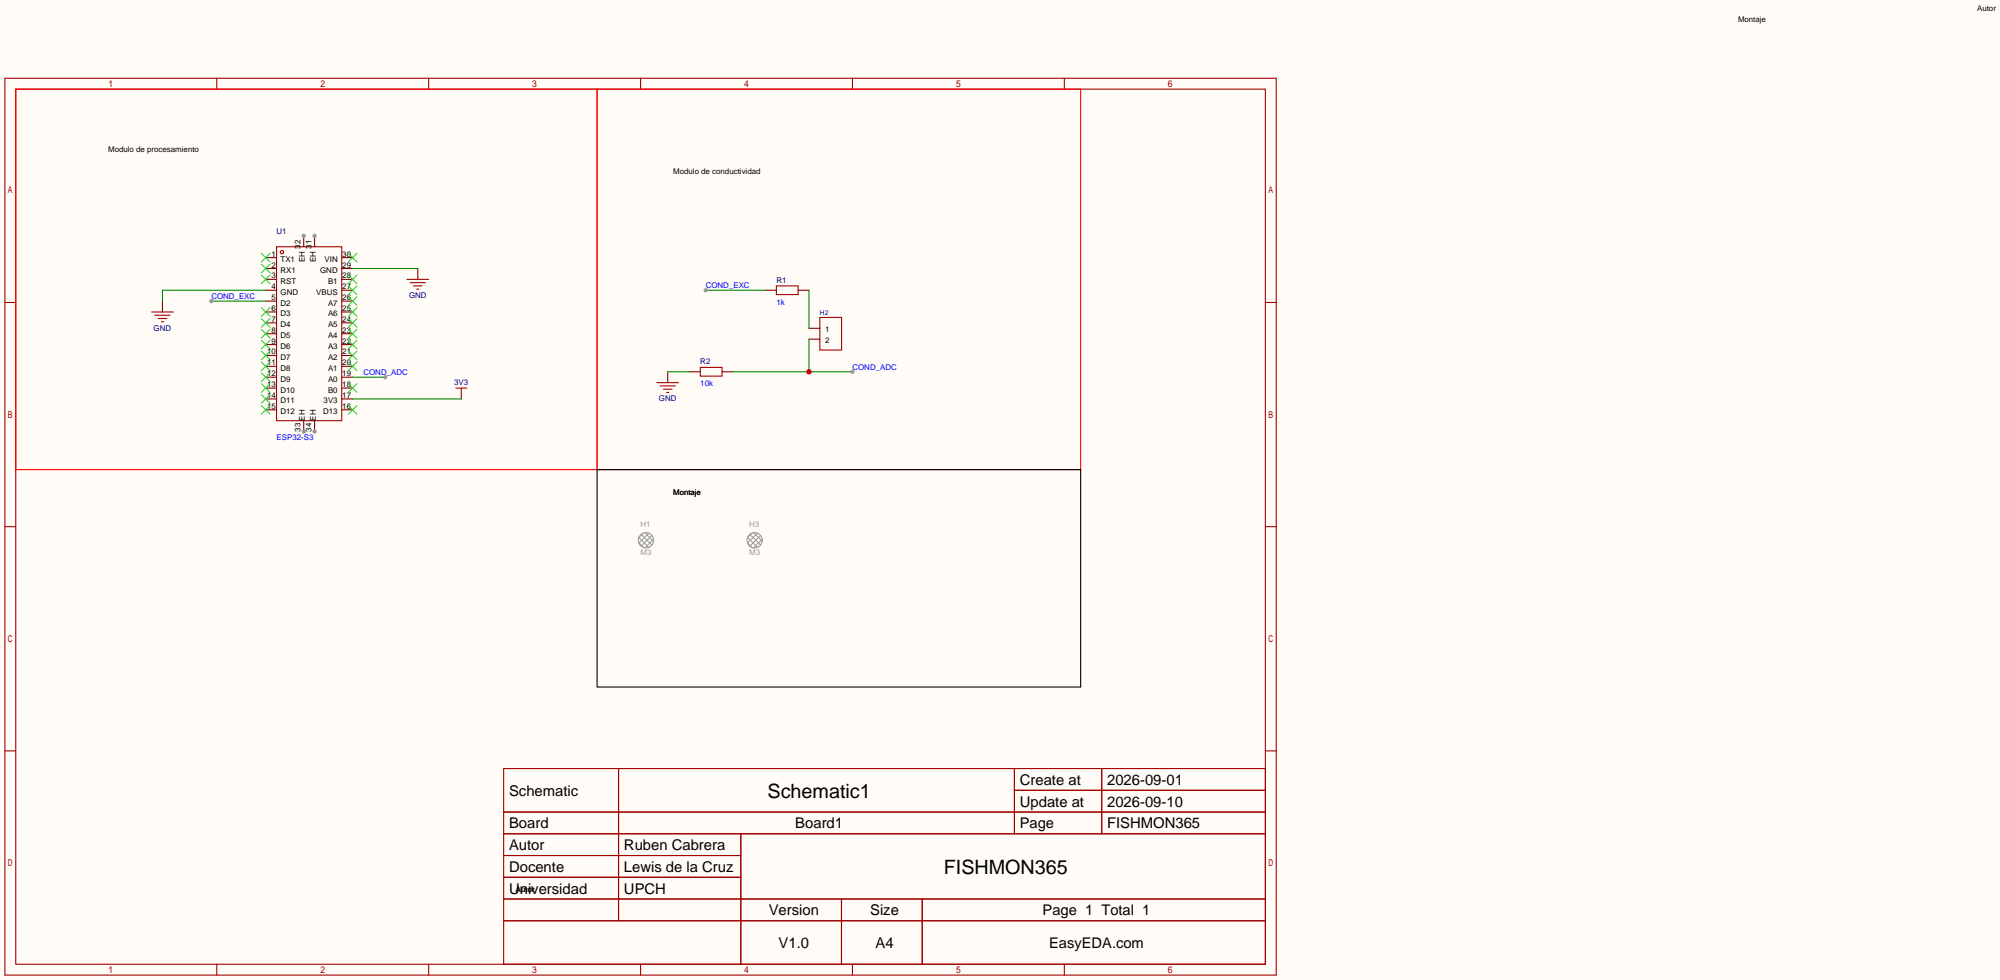
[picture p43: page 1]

Schematic | Schematic1 | Create at | 2026-09-01

Update at | 2026-09-10

Board | Board1 | Page | FISHMON365
Autor | Ruben Cabrera | FISHMON365
Docente | Lewis de la Cruz
Universidad Autor | UPCH

Version | Size | Page 1 Total 1
V1.0 | A4 | EasyEDA.com

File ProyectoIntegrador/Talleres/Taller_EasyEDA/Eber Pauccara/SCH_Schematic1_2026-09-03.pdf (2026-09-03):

MODULO DE TEMPERATURA | MODULO DE PROCESAMIENTO

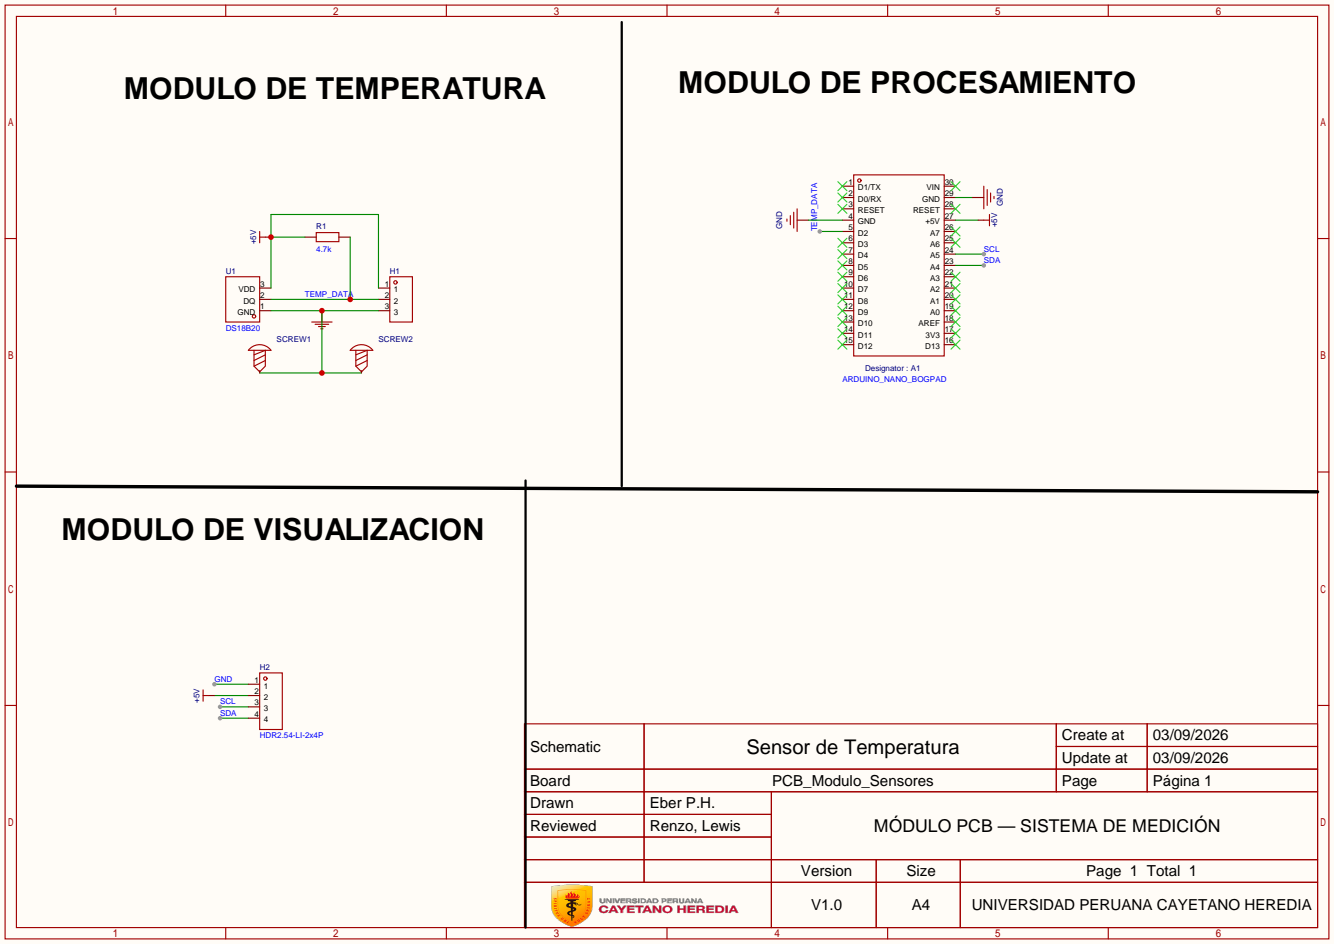
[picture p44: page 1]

Schematic | Sensor de Temperatura | Create at | 03/09/2026

Update at | 03/09/2026

Board | PCB_Modulo_Sensores | Page | Página 1
Drawn | Eber P.H. | MÓDULO PCB  SISTEMA DE MEDICIÓN

Reviewed | Renzo, Lewis

Version | Size | Page 1 Total 1
V1.0 | A4 | UNIVERSIDAD PERUANA CAYETANO HEREDIA

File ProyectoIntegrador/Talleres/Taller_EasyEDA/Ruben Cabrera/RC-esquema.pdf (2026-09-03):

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

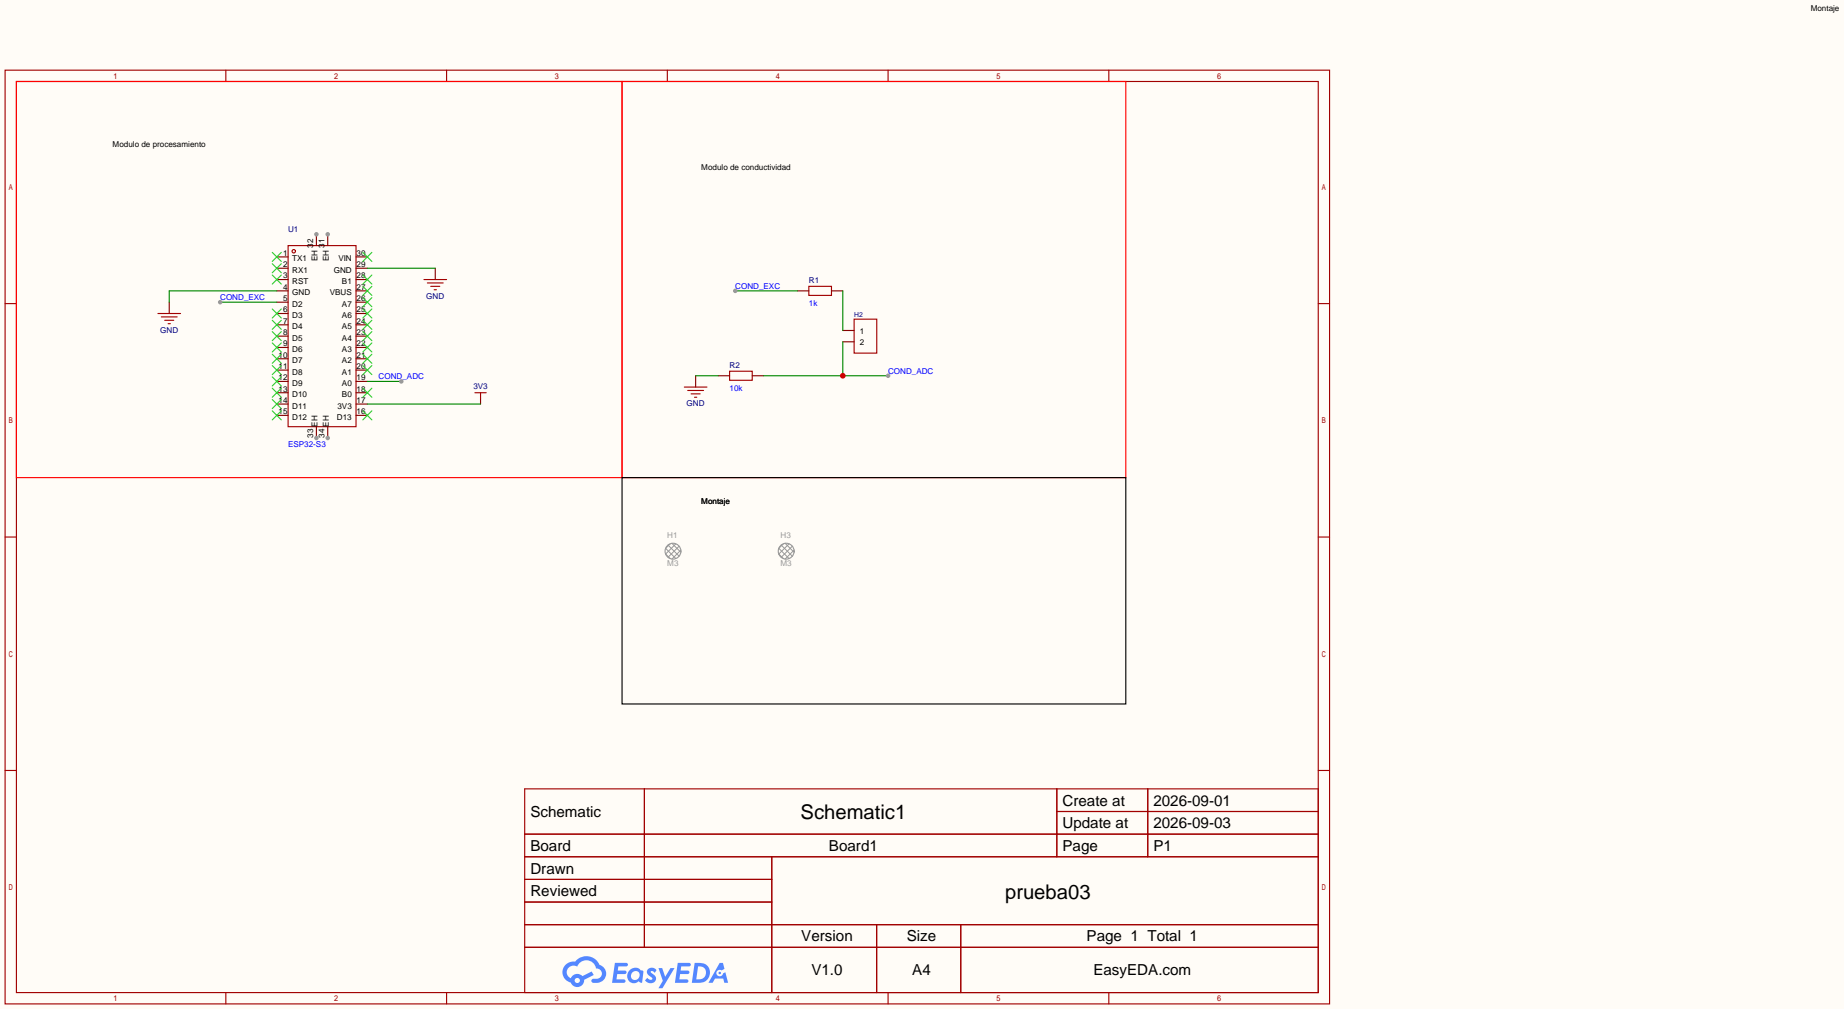
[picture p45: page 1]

Schematic | Schematic1 | Create at | 2026-09-01

Update at | 2026-09-03

Board | Board1 | Page | P1
Drawn | | prueba03
Reviewed

Version | Size | Page 1 Total 1
V1.0 | A4 | EasyEDA.com

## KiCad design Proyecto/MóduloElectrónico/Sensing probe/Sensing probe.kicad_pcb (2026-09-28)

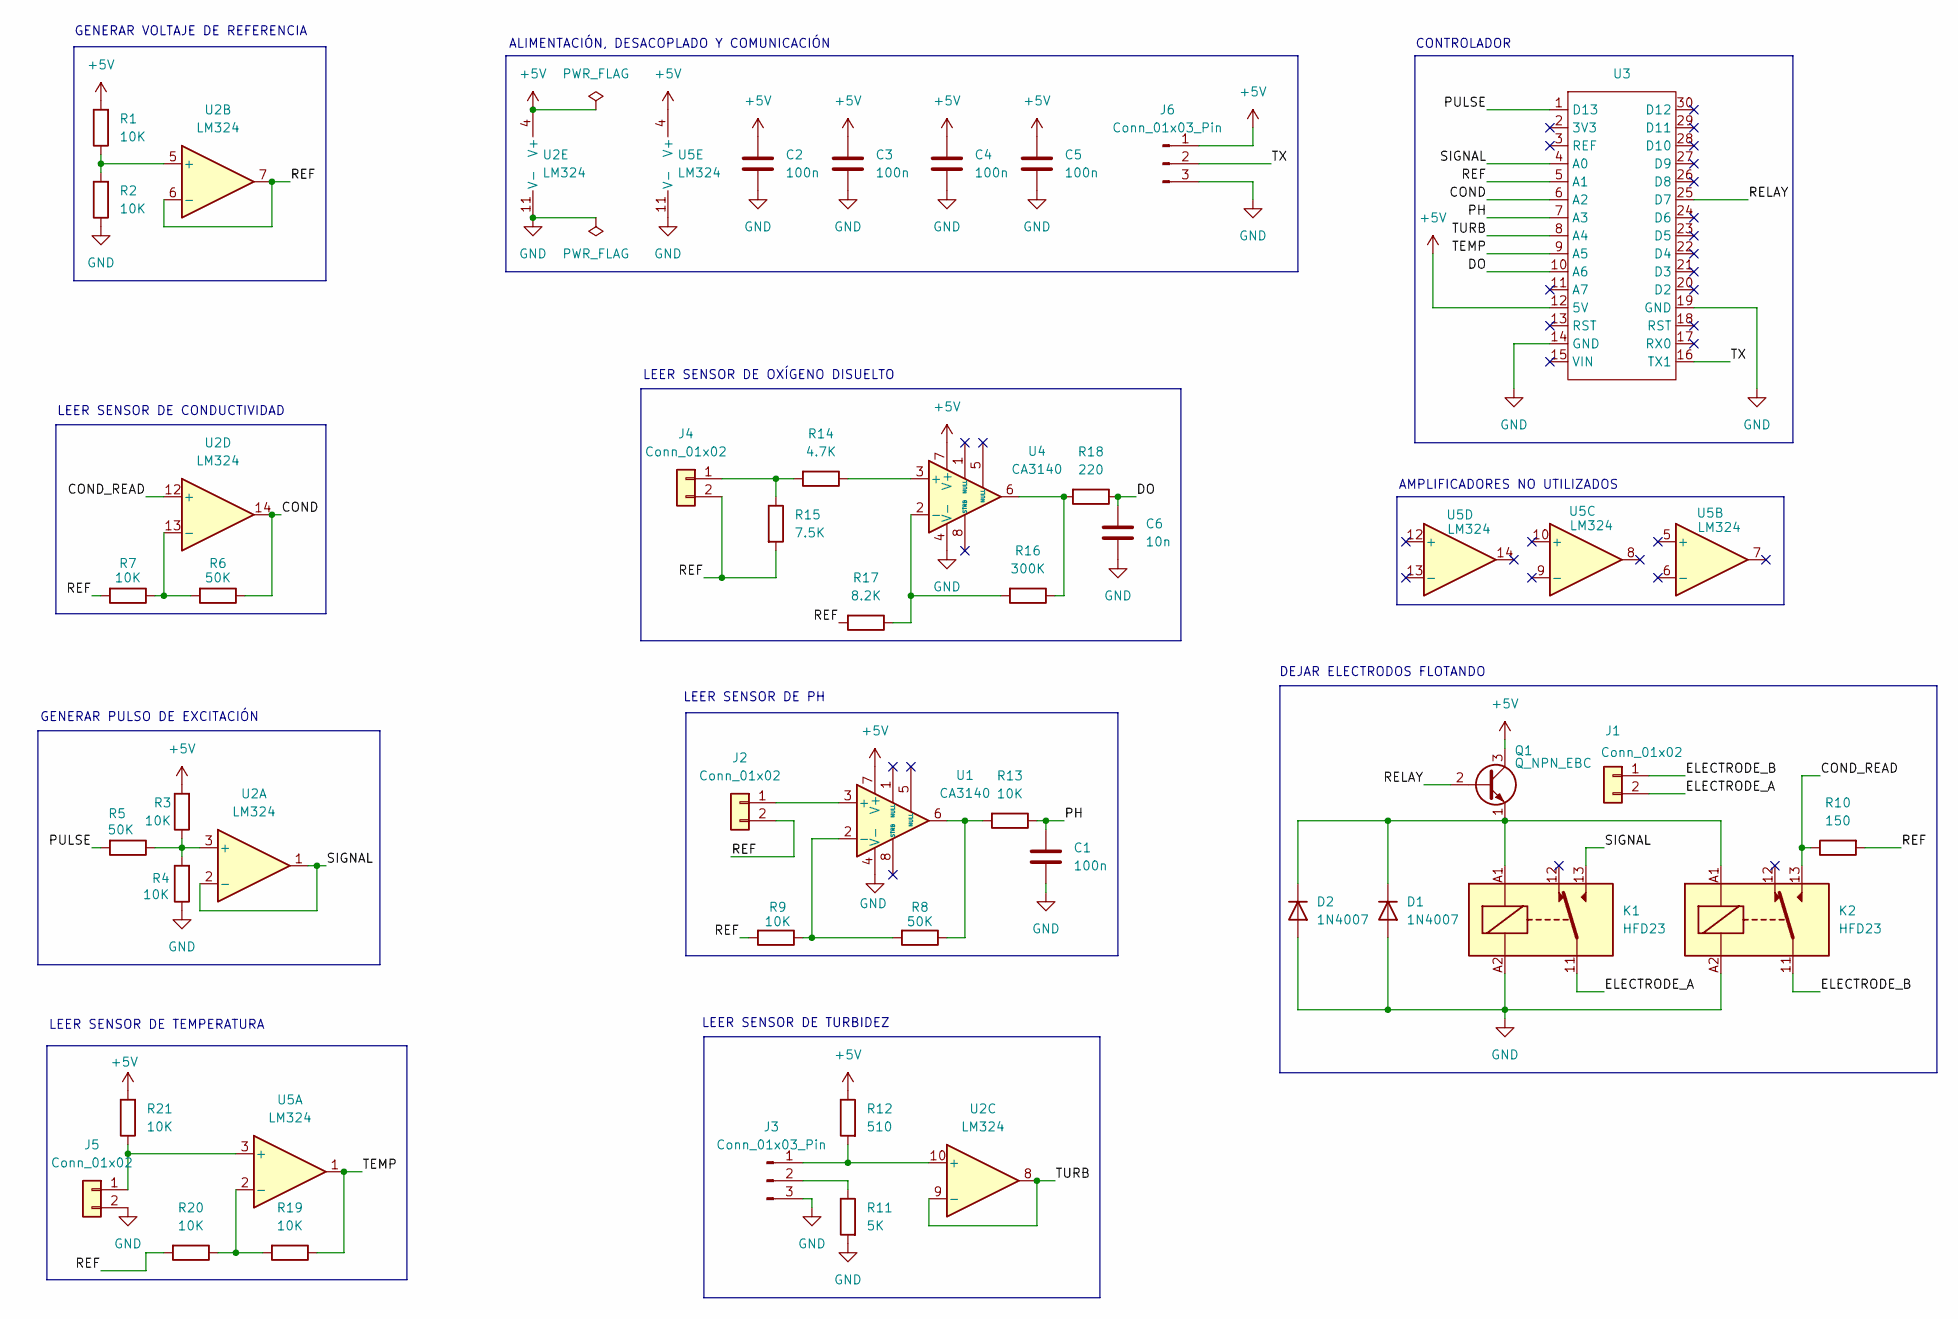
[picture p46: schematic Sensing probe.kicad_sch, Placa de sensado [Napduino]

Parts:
C1, C2, C3, C4, C5: 100n; C_Disc_D5.0mm_W2.5mm_P2.50mm
C6: 10n; C_Disc_D5.0mm_W2.5mm_P2.50mm
D1, D2: 1N4007; D_DO-34_SOD68_P2.54mm_Vertical_AnodeUp
J1, J2, J4, J5: Conn_01x02; PinHeader_1x02_P2.54mm_Vertical
J3, J6: Conn_01x03_Pin; PinHeader_1x03_P2.54mm_Vertical
K1, K2: HFD23
Q1: Q_NPN_EBC; TO-92
R1, R2, R3, R4, R19, R20, R21: 10K; R_Axial_DIN0204_L3.6mm_D1.6mm_P2.54mm_Vertical
R5: 50K; R_Axial_DIN0204_L3.6mm_D1.6mm_P2.54mm_Vertical
R6, R8: 50K; R_Axial_DIN0204_L3.6mm_D1.6mm_P5.08mm_Horizontal
R7, R9, R13: 10K; R_Axial_DIN0204_L3.6mm_D1.6mm_P5.08mm_Horizontal
R10: 150; R_Axial_DIN0204_L3.6mm_D1.6mm_P5.08mm_Horizontal
R11: 5K; R_Axial_DIN0204_L3.6mm_D1.6mm_P5.08mm_Horizontal
R12: 510; R_Axial_DIN0204_L3.6mm_D1.6mm_P5.08mm_Horizontal
R14: 4.7K; R_Axial_DIN0204_L3.6mm_D1.6mm_P5.08mm_Horizontal
R15: 7.5K; R_Axial_DIN0204_L3.6mm_D1.6mm_P5.08mm_Horizontal
R16: 300K; R_Axial_DIN0204_L3.6mm_D1.6mm_P5.08mm_Horizontal
R17: 8.2K; R_Axial_DIN0204_L3.6mm_D1.6mm_P5.08mm_Horizontal
R18: 220; R_Axial_DIN0204_L3.6mm_D1.6mm_P5.08mm_Horizontal
U1, U4: CA3140; DIP-8_W7.62mm
U2, U5: LM324; DIP-14_W7.62mm
U3: Arduino nano

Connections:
+5V: C2.1, C3.1, C4.1, C5.1, J6.1, Q1.3 (C), R1.2, R3.2, R12.1, R21.2, U1.7 (V+), U2.4 (V+), U3.12 (5V), U4.7 (V+), U5.4 (V+)
/COND: R6.1, U2.14, U3.6 (A2)
/COND_READ: K2.13, R10.1, U2.12 (+)
/DO: C6.1, R18.1, U3.10 (A6)
/ELECTRODE_A: J1.2, K1.11
/ELECTRODE_B: J1.1, K2.11
/PH: C1.1, R13.1, U3.7 (A3)
/PULSE: R5.2, U3.1 (D13)
/REF: J2.2, J4.2, R7.2, R9.2, R10.2, R15.2, R17.2, R20.2, U2.6 (-), U2.7, U3.5 (A1)
/RELAY: Q1.2 (B), U3.25 (D7)
/SIGNAL: K1.13, U2.1, U2.2 (-), U3.4 (A0)
/TEMP: R19.1, U3.9 (A5), U5.1
/TURB: U2.8, U2.9 (-), U3.8 (A4)
/TX: J6.2, U3.16 (TX1)
GND: C1.2, C2.2, C3.2, C4.2, C5.2, C6.2, D1.2 (A), D2.2 (A), J3.3, J5.2, J6.3, K1.A2, K2.A2, R2.1, R4.1, R11.2, U1.4 (V-), U2.11 (V-), U3.14 (GND), U3.19 (GND), U4.4 (V-), U5.11 (V-)
unnamed: D1.1 (K), D2.1 (K), K1.A1, K2.A1, Q1.1 (E)
unnamed: J2.1, U1.3 (+)
unnamed: J3.1, R12.2, U2.10 (+)
unnamed: J3.2, R11.1
unnamed: J4.1, R14.2, R15.1
unnamed: J5.1, R21.1, U5.3 (+)
unnamed: R8.1, R13.2, U1.6
unnamed: R16.1, R18.2, U4.6
unnamed: R8.2, R9.1, U1.2 (-)
unnamed: R3.1, R4.2, R5.1, U2.3 (+)
unnamed: R1.1, R2.2, U2.5 (+)
unnamed: R6.2, R7.1, U2.13 (-)
unnamed: R14.1, U4.3 (+)
unnamed: R16.2, R17.1, U4.2 (-)
unnamed: R19.2, R20.1, U5.2 (-)

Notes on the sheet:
DEJAR ELECTRODOS FLOTANDO
LEER SENSOR DE OXÍGENO DISUELTO
CONTROLADOR
LEER SENSOR DE TURBIDEZ
LEER SENSOR DE TEMPERATURA
AMPLIFICADORES NO UTILIZADOS
ALIMENTACIÓN, DESACOPLADO Y COMUNICACIÓN
GENERAR PULSO DE EXCITACIÓN
GENERAR VOLTAJE DE REFERENCIA
LEER SENSOR DE CONDUCTIVIDAD
LEER SENSOR DE PH

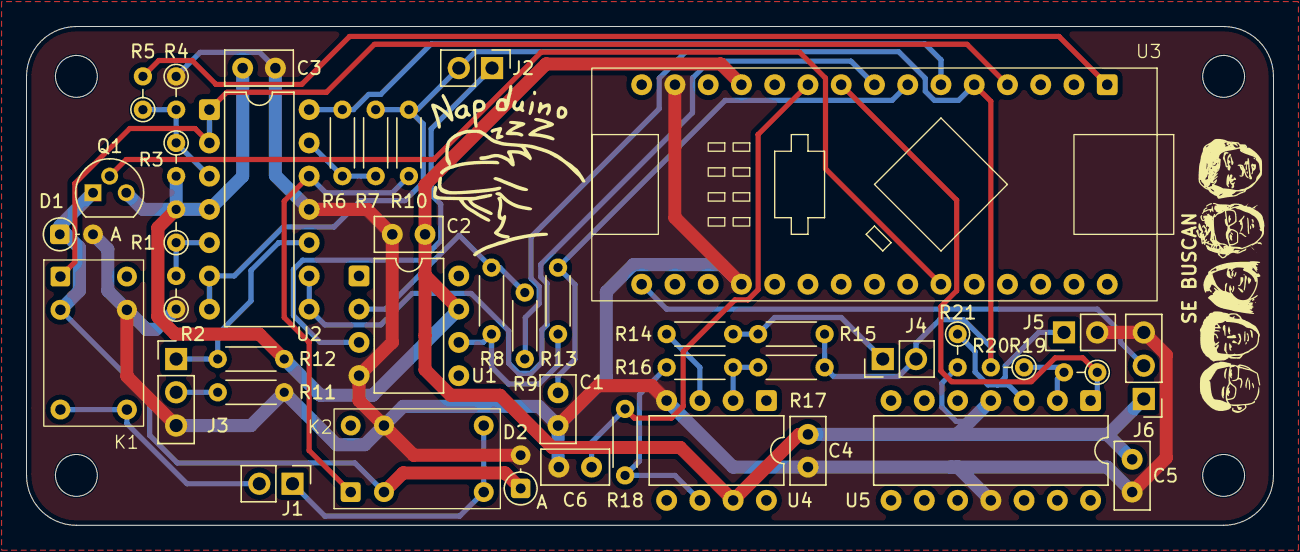
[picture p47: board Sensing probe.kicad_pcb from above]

Board: 2 copper layers, 95.2 x 38.1 mm, 43 parts (0 on the bottom side), 30 nets.

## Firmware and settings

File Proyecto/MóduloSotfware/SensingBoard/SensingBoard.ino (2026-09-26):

uint8_t signal = A0;    // Señal de excitación
uint8_t ref = A1;       // Referencia
uint8_t cond = A2;      // Lectura de conductividad
uint8_t ph = A3;        // Lectura de PH
uint8_t turb = A4;      // Lectura de Turbidez
uint8_t relay = 7;

uint8_t pulse = 13;     // Pulso de excitación

uint16_t adc = 1024;    // Precisión del ADC

float v_ref;
float v_pou;
float v_out;

float m_res = 150;      // Valor de resistencia para sensor de conductividad

float resistencia;
float turbidez;
float pothid;


void read_cond(){
  v_ref = 5 *  analogRead(ref) / adc;     // Leer voltaje de referencia 
  v_pou = 5 *  analogRead(signal) / adc;  // Leer voltaje de pulso
  v_out = 5 *  analogRead(cond) / adc;    // Leer voltaje de salida
  
  v_pou = v_pou - v_ref;                    // Relativizar los voltajes respecto a referencia
  v_out = v_out - v_ref;
}

float get_cond(){
  float acc = 0;
  float res = 0;
  uint8_t counter = 0;
  digitalWrite(relay, HIGH);
  pinMode(pulse, OUTPUT);
  
  while(counter != 250){
    digitalWrite(pulse, HIGH);
    delay(1);
    read_cond();
    res = ((m_res * v_pou)/(v_out / 6)) - m_res;  // Obtener una lectura de resistencia
    acc = acc + res;
    digitalWrite(pulse, LOW);
    delay(1);
    read_cond();
    res = ((m_res * v_pou)/(v_out / 6)) - m_res;  // Obtener una segunda lectura de resistencia
    acc = acc + res;
    counter ++;
  }
  digitalWrite(relay, LOW);
  pinMode(pulse, INPUT);
  return acc / 500;
}

float get_turb(){
  float acc = 0;
  float temp = 0;
  uint8_t counter = 0;

  while(counter != 250){
    temp = float(5.0 * analogRead(turb) / adc);
    acc = acc + temp;
    delay(1);
    counter ++;
  }

  return acc / 250;
}

float get_ph(){
  float acc = 0;
  uint8_t counter = 0;

  while(counter != 250){
    acc = acc + (5.0*(analogRead(ph) - analogRead(ref)))/6.0;
    delay(1);
    counter ++;
  }

  return acc / 250;
}

void setup() {
  pinMode(relay, OUTPUT);
  Serial.begin(115200);
}

void loop() {
  resistencia = get_cond();
  turbidez = get_turb();
  pothid = get_ph();

  Serial.println();
  Serial.print("Resistencia [ohms]: ");
  Serial.print(resistencia);
  Serial.println();
  Serial.print("Turbidez [volt]: ");
  Serial.print(turbidez);
  Serial.println();
  Serial.print("Ph [volt]: ");
  Serial.print(pothid);
  Serial.println();
  Serial.println();
}

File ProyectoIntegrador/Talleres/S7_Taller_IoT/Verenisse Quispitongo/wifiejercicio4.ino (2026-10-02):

#include <WiFi.h>
#include <PubSubClient.h>
#include <ArduinoJson.h>
#include <DHT.h>

// ================= CONFIGURACIÓN WIFI =================
const char* WIFI_SSID = "iPhone";
const char* WIFI_PASS = "20170051";

// ================= CONFIGURACIÓN MQTT =================
const char* MQTT_SERVER = "mqtt.rcr-labs.com";
const int MQTT_PORT = 1883;

const char* MQTT_USER = "alumno";
const char* MQTT_PASSWORD = "UPCH2026";
const char* CLIENT_ID = "ESP32_Equipo04";

// Topics MQTT
const char* TOPIC_PUB = "equipo04/sensor/datos";
const char* TOPIC_SUB = "equipo04/actuadores/led";

// ================= DHT11 =================
#define DHTPIN 4
#define DHTTYPE DHT11

DHT dht(DHTPIN, DHTTYPE);

// ================= OBJETOS Y VARIABLES =================
WiFiClient espClient;
PubSubClient client(espClient);

unsigned long ultimoEnvio = 0;
const long intervaloEnvio = 5000;

//conexión WiFi
void setupWiFi() {
  delay(10);

  Serial.println();
  Serial.print("Conectando a Wi-Fi: ");
  Serial.println(WIFI_SSID);

  WiFi.mode(WIFI_STA);
  WiFi.begin(WIFI_SSID, WIFI_PASS);

  while (WiFi.status() != WL_CONNECTED) {
    delay(500);
    Serial.print(".");
  }

  Serial.println("\nWiFi conectado con éxito");
  Serial.print("Dirección IP local: ");
  Serial.println(WiFi.localIP());
}

//callback MQTT
void callback(char* topic, byte* payload, unsigned int length) {
  Serial.print("Mensaje recibido en topic [");
  Serial.print(topic);
  Serial.print("]: ");

  String mensaje = "";

  for (unsigned int i = 0; i < length; i++) {
    mensaje += (char)payload[i];
  }

  Serial.println(mensaje);

  if (String(topic) == TOPIC_SUB) {
    if (mensaje == "ON") {
      digitalWrite(2, HIGH);
      Serial.println("Comando: Encender LED");
    }
    else if (mensaje == "OFF") {
      digitalWrite(2, LOW);
      Serial.println("Comando: Apagar LED");
    }
  }
}

//reconexión MQTT
void reconnect() {
  while (!client.connected()) {

    Serial.print("Intentando conectar con broker MQTT...");

    if (client.connect(CLIENT_ID, MQTT_USER, MQTT_PASSWORD)) {

      Serial.println(" ¡Conectado!");

      client.subscribe(TOPIC_SUB);

      Serial.print("Suscrito a: ");
      Serial.println(TOPIC_SUB);

    } else {

      Serial.print(" Falló. Código de error rc=");
      Serial.print(client.state());

      Serial.println(" Reintentando en 5 segundos...");

      delay(5000);
    }
  }
}

void setup() {

  Serial.begin(115200);

  setupWiFi();

  client.setServer(MQTT_SERVER, MQTT_PORT);
  client.setCallback(callback);

  pinMode(2, OUTPUT);

  dht.begin();
}

void loop() {

  if (!client.connected()) {
    reconnect();
  }

  client.loop();

  unsigned long ahora = millis();

  if (ahora - ultimoEnvio >= intervaloEnvio) {

    ultimoEnvio = ahora;

    //leer DHT11
    float temperatura = dht.readTemperature();
    float humedad = dht.readHumidity();

    //comprobar si la lectura fue válida
    if (isnan(temperatura) || isnan(humedad)) {
      Serial.println("Error al leer el DHT11");
      return;
    }

    Serial.print("Temperatura: ");
    Serial.print(temperatura);
    Serial.println(" °C");

    Serial.print("Humedad: ");
    Serial.print(humedad);
    Serial.println(" %");

    //crear JSON
    StaticJsonDocument<200> doc;

    doc["dispositivo"] = CLIENT_ID;
    doc["temperatura"] = temperatura;
    doc["humedad"] = humedad;

    char jsonBuffer[256];

    serializeJson(doc, jsonBuffer);

    //publicar MQTT
    Serial.print("Publicando en ");
    Serial.print(TOPIC_PUB);
    Serial.print(": ");
    Serial.println(jsonBuffer);

    client.publish(TOPIC_PUB, jsonBuffer);
  }
}

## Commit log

2026-08-20 Rename Opciones de Logo 3D (1).png to Logo
2026-08-20 Update measurement criteria section in README
    Renamed section to 'Posibles criterios de medición' and removed comment on expected impact.
2026-08-21 Rename README.md to Lista de exigencias.md
2026-08-21 Update Lista de exigencias.md
2026-08-21 En caso el único archivo MD resulta ilegible
2026-08-27 Update simulation section in Simulaciones.md
    Added simulation details for stress on gear teeth in both Z and X axes.
2026-08-27 SIMULACION EN simscale_EBER
    https://www.simscale.com/workbench/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
2026-08-27 modulo de sensores
    captura en simscale
2026-08-27 Add FEA simulation analysis for underwater prototype
    Added detailed analysis of FEA simulations for the underwater prototype, including mesh configuration, Von Mises stress distribution, and boundary conditions.
2026-09-03 Update electronic design documentation with images
    Added images and descriptions for circuit schematic, PCB layout, and 3D model.
2026-09-03 Create Sistema de Simulaciones en jpg
2026-09-03 Update Sistema de Simulaciones en jpg.md
2026-09-03 Update project details and circuit descriptions
2026-09-03 Add project documentation for temperature monitoring system
    Added documentation for the Subaquatic Temperature Monitoring System project, including circuit development and PCB design details.
2026-09-04 Matriz morfológica con formato xlsx
    [Matriz morfolófica.xlsx]
2026-09-08 Create Evaluación de matriz morfológica.md
2026-09-08 Rename Evaluación de matriz morfológica.md to P-Evaluación de matriz morfológica.md
2026-09-10 Update PCB design image with new version
2026-09-10 Document simulation setup for Fishmoon prototype
    Added simulation configuration details for the Fishmoon prototype under water, including material properties, gravity effects, lateral forces, hydrostatic pressure, and prototype support conditions.
2026-09-18 Rename README.md to Esquemático sensores.md
2026-09-22 Update title to include 'Resumen de la sesión'
2026-09-25 Update and rename Nuevo Documento de texto.txt to TallerTransferLearning.md
2026-09-26 Esquemático KiCAD
    [Sensing probe.kicad_pcb, Sensing probe.kicad_sch]
2026-09-26 Update sensing board
    [Sensing probe.kicad_pcb, Sensing probe.kicad_sch]
2026-09-26 Arduino nano
2026-09-27 Desconector de sensor de conductividad
    [Sensing probe.kicad_pcb, Sensing probe.kicad_sch]
2026-09-27 Modelos 3D para Onshape
    [Current_sensing_board.step, LoraV4.kicad_pcb, LoraV4.kicad_sch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]
2026-09-28 Previsualización KiCAD
2026-10-02 Update figure caption for ESP32 circuit
2026-10-02 Enhance Node-RED description in InformeTallerIOT2.md
    Expanded explanation of Node-RED's capabilities in the context of ESP32 data processing.
2026-10-03 Actualización - Placas KiCAD
    [Main board.kicad_pcb, Upper_board.step]
2026-10-05 Update INFORME TÉCNICO Lista de exigencias y plan de trabajo.md
2026-10-05 Revise ergonomics requirements for device installation
    Updated the ergonomics section to specify installation and maintenance ease.
2026-10-09 cambio de nombre
2026-10-16 Revisión esquemático
    Bias modificado para funcionar adecuadamente con los aplificadores CA3140
2026-10-28 Actualizar comparación de soluciones tecnológicas
    Se actualizó la sección de comparación de soluciones existentes para incluir una tabla que resume las características de diferentes tecnologías de monitoreo de calidad del agua, destacando FishMon 36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
2026-11-02 Rename Boceto técnico del sistema de boya sondadora.png to Boceto 2 de boya sondadora.png
2026-11-02 Add flowchart for FishMon 365 system overview
    Added a flowchart to illustrate the conceptual flow of the FishMon 365 system, detailing the interactions between the submerged module, floating module, and monitoring system.
2026-11-03 Update images in TRL2.md
    Updated images in TRL2.md to reflect new schematic and removed outdated images.
2026-11-04 Add challenges for scaling FishMon 365 to operational use
    Document challenges and requirements for scaling FishMon 365 to operational environments, including technical, regulatory, and commercial aspects.
